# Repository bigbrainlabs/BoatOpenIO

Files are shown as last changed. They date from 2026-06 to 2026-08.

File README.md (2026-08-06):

# BoatOpenIO




**Universal Marine IO System – Open Source, modular, fully configurable**

> *"Plug in, configure, done."*

BoatOpenIO is an open hardware platform for sensor integration on boats. Each of the 16 sensor terminals can be freely assigned to any of the up to 16 input channels via software. Pluggable mini-boards handle signal conditioning — no soldering, no rewiring.

Part of the **[Logbook Without Posing](https://www.amazon.com/s?k=logbook+without+posing)** series – Volume 3.

---

## 📚 Support the project

This project is 100% open source and free. The complete story – every idea, mistake, detour and solution – is documented in the book series **"Logbook Without Posing"**.

If you find this project useful and want to support it: buying the books is the best way.

> *"Found this useful? Grab a book — or the whole series. You'll be supporting further development."*

**[👉 Logbook Without Posing on Amazon](https://amzn.to/4e5swN6)**

Prefer not to deal with a PCB fab? The manufactured board set is available on Tindie — same design as the Gerbers in this repo, which stay free to download and order yourself.

**[👉 BoatOpenIO v2 PCB Set (4 boards) on Tindie](https://www.tindie.com/products/bigbrainlabs/boatopenio-v2-pcb-set-4-boards/)**

### 🏭 Boards sponsored by PCBWay

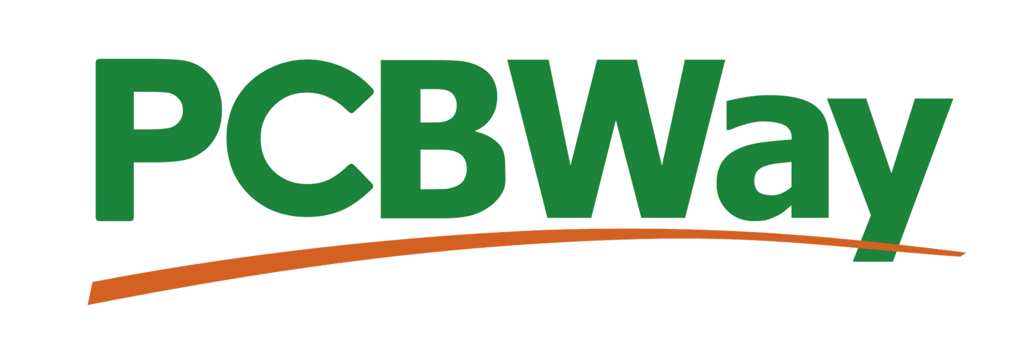
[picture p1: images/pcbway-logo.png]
PCBWay


**[PCBWay](https://www.pcbway.com)** sponsors the board manufacturing for BoatOpenIO, the sensor gateway of this ecosystem — thank you!

**[👉 Order the boards directly: PCBWay project page](https://www.pcbway.com/project/member/?bmbno=0EDF2E80-7ABD-44)**

---

## ⚠️ Safety Warning

**Always verify which mini-board is plugged into which channel before applying power.**

Connecting 12V directly to a pull-up channel (instead of through a voltage divider) will destroy the MUX, all ADS1115 and the ESP32 through I2C chain reaction.

The input board includes protection circuitry (3.3V) on all 16 signal inputs — but correct mini-board assignment is still essential.

---

## Concept

Commercial marine IO systems cost hundreds of euros and are closed black boxes.

BoatOpenIO costs a fraction of that — and anyone can adapt, extend, and improve it.

```
Sensor → Mini-Board → JST 3-Pin → PCB → Zener Protection → MUX → ADS1115 → ESP32 → MQTT → BoatOS
```

---

## Who Is This For?

**If your boat was built before 2000, this project was built for you.**

Boats from that era came with **analog VDO sensors** — oil pressure, oil temperature, coolant temperature, tank level, RPM. These sensors are robust, time-tested, and still doing their job perfectly. The problem: no modern system speaks their language.

NMEA 2000 gateways that bridge analog signals to modern boat networks exist — but they cost **300–500€**, are closed proprietary boxes, and give you zero insight or control over what happens inside.

**BoatOpenIO is an open analog marine gateway.**

Plug in your existing VDO sensors. Get clean MQTT output. Forward to Signal K or BoatOS. Done — without replacing a single sensor, without rewiring, without a black box.

```
VDO sensor → BoatOpenIO → MQTT → Signal K / BoatOS → modern dashboard
```

> **Built for boats built before 2000 that will sail for another 20 years — and deserve a modern dashboard without a full refit.**

---

## Hardware – v2 PCB

Four separate boards, connected via IDC ribbon cables: **input board**, **main board**, **ESP32 adapter board**, and **VCC distributor**. Gerber files ready to order in `hardware/v2/*/gerber/`.

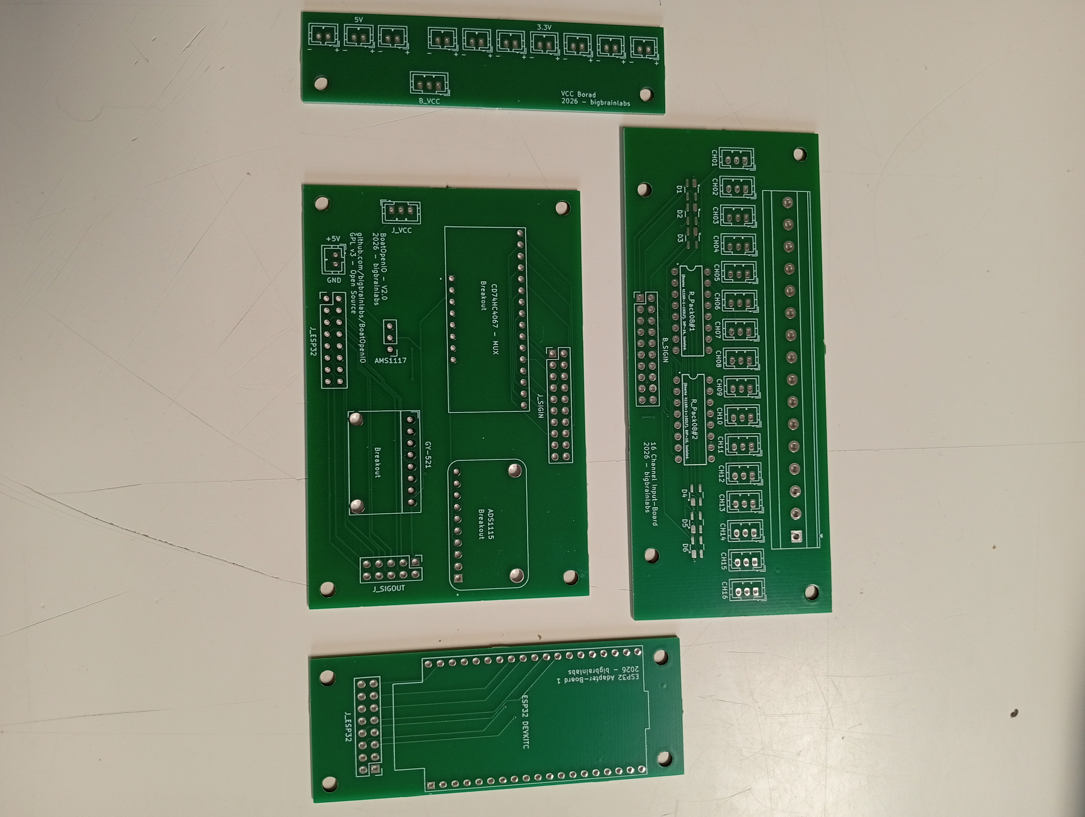
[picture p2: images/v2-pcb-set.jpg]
The bare v2 board set: input board, main board, ESP32 adapter board and VCC distributor


> 🛒 **Don't want to order at a PCB fab?** The fabricated set of all four boards is available ready-made: **[BoatOpenIO v2 PCB Set on Tindie](https://www.tindie.com/products/bigbrainlabs/boatopenio-v2-pcb-set-4-boards/)** — bare PCBs, components not included (see the parts list below).

```
Input Board ──20-pin ribbon──> Main Board <──16-pin ribbon── ESP32 Adapter Board
                                    │
                               3-pin JST
                                    │
                               VCC Board
```

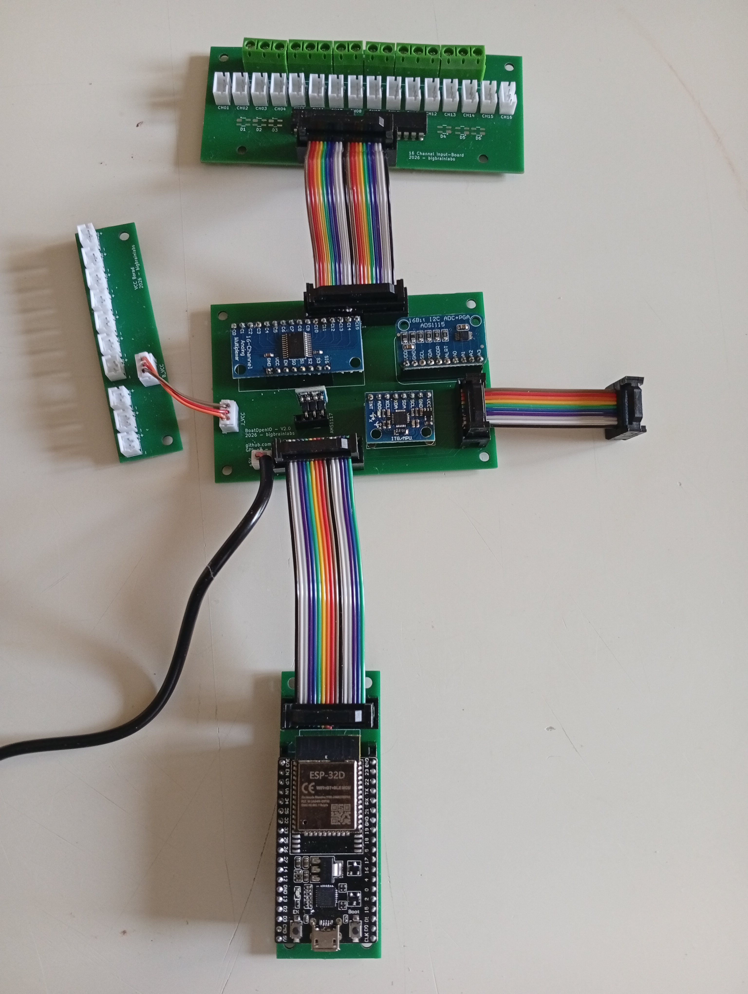
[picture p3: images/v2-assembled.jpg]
Populated and wired v2 assembly with breakouts and ribbon cables


### Main Board Components

| Component | Description | Socketed |
|---|---|---|
| ESP32-DEVKITC-32D-F (38-pin) | Microcontroller, WiFi, I2C, MUX control – on its own adapter board | ✅ |
| CD74HC4067 Breakout | 16:1 analog multiplexer | ✅ |
| ADS1115 Breakout (1×) | 16-bit ADC | ✅ |
| MPU6050 Breakout (GY-521) | 6-DOF IMU, tilt/impact detection | ✅ |
| AMS1117-3.3 Breakout | 5V → 3.3V regulator | ✅ |

**Everything socketed** — no component soldered directly. Faulty ESP32? Swap the adapter board. Done.

The ESP32 sits on its own dedicated adapter board. The first adapter board is designed for the 38-pin ESP32 DevKitC-32D — swappable and ready for future ESP32 variants.

### Protection Circuit (Input Board)

Every one of the 16 signal inputs has a hardware protection circuit, directly on the input board:

```
Sensor → Screw terminal → R_Pack08 (resistor network) → SP0503BAHTG (Zener array, 3.3V) → MUX signal
```

2× Bourns 4116R-1-102LF (R_Pack08, DIL-16, isolated) + 6× SP0503BAHTG (SOT-143, 3 channels each).

> ⚠️ **Pull-up voltage is 3.3V** — the ADS1115 VDD is at 3.3V; higher voltages on the inputs risk component damage.

#### Running without the protection circuit (not recommended)

If the Bourns or Zener components are unavailable and you want to get the board running first, the resistor networks can be bypassed — but understand what you are giving up.

**How to bypass the Bourns 4116R-1-102LF:**  
The DIL-16 package contains 8 isolated resistors. Each resistor connects a pin on the left row to the opposing pin on the right row:

```
Pin 1  ──[R]──  Pin 16
Pin 2  ──[R]──  Pin 15
Pin 3  ──[R]──  Pin 14
  ...             ...
Pin 8  ──[R]──  Pin 9
```

To bypass: solder a short jumper wire across each pair (8 bridges per chip, 16 total for both R_Pack08). The signal then passes through without series resistance. The SP0503BAHTG Zener pads can simply be left empty.

> 🔴 **Without this protection, all 16 inputs are exposed.** A wrong mini-board, a wiring mistake, or any brief overvoltage can destroy the MUX, ADS1115, and ESP32 in a chain reaction — all three at once. Only bypass for bench tests with known, clean signals. Fit the real parts before installing on the boat.

### Input Board – Connectors

```
16× screw terminal 5.08mm   → raw sensor signal
20-pin IDC header            → connection to main board (SIG1–16 + GND)
```

### VCC Board – Connectors

The VCC board distributes power to the mini-boards via JST connectors. It connects to the main board via a 3-pin JST cable (5V, 3.3V, GND).

```
7× JST 2-pin (3.3V)         → VCC rail for passive/ESP01 mini-boards
3× JST 2-pin (5V)           → VCC rail for Arduino Nano mini-boards
3-pin JST                   → connection to main board (5V · 3.3V · GND)
```

### I2C Address

Only 1× ADS1115 fitted (the MUX routes all 16 channels onto a single signal line) → fixed address **0x48**.

### GPIO Assignment (ESP32, via 16-pin main board ↔ adapter board connector)

| GPIO | Function |
|---|---|
| GPIO21 | I2C SDA |
| GPIO22 | I2C SCL |
| GPIO14 | MUX S0 |
| GPIO27 | MUX S1 |
| GPIO26 | MUX S2 |
| GPIO25 | MUX S3 |
| GPIO4 / 5 / 13 / 16 / 17 / 18 / 19 / 23 | OUT1–OUT8 (prepared for output channels) |

### Output Channels (prepared)

The main board already has a 10-pin header prepared for 8 signal output channels (+5V/GND) — e.g. for heaters, pumps, horns via relay or MOSFET mini-boards. Works on the same plug-in principle as the inputs.

### Compatible ESP32 Modules (first adapter board)

The footprint fits all modules in the 38-pin DevKitC layout: **ESP32-WROOM-32 / -32D / -32E / -32U / -32UE**, as well as **ESP32-SOLO-1**.

> ⚠️ **ESP32-WROVER is NOT compatible** — GPIO16/17 are internally reserved for PSRAM on WROVER and therefore blocked for output channels.

---

## Mini-Boards (pluggable)

| Type | Code | Use case |
|---|---|---|
| Voltage divider | VT | 12V VDO sensors → 3.3V |
| Pull-down | PD | Digital sensors, switches |
| Pull-up | PU | Open-collector outputs |
| Schmitt trigger | ST | Magnetic pickup sensors, 50Hz generators |
| Pulse board | ISP | RPM, flow (Arduino Nano / ESP01) |
| Optocoupler | OPT | Galvanic isolation (W-terminal RPM) |
| Direct / jumper | DIR | 3.3V signals directly |
| GND collector | GND | Multiple sensor ground loops → single reference |

### MotorCombo — everything on one board

The **MotorCombo** taps the most common engine sensors directly, so you don't have to plug in six separate mini-boards:

| Channel | Conditioning |
|---|---|
| Battery 1 + 2 | Voltage divider |
| Oil pressure | Pull-up |
| Temperature | Pull-up |
| Tank | Pull-up |
| RPM | Optocoupler + ESP-01 |

**[MotorCombo THT](hardware/mini-boards/MotorCombo_THT/README.md)** — through-hole, hand-solderable. Gerbers and documentation are in the repo. Resistor values are deliberately left open so everyone can fit what matches their own VDO senders — which is also why there is no pre-assembled SMD variant: with the values depending on the senders, a fixed pre-populated board makes no sense.

**Design and submit your own mini-boards** — pull requests welcome!

---

## Multiplexer Logic

The CD74HC4067 routes one of 16 inputs onto the shared ADS pin A0 via a 4-bit address (S3–S0). Address and chip input follow the datasheet: `0000 → C0` … `1111 → C15`.

> **Rev.1 note — channels are mirrored in software.** On the Rev.1 board the channel wiring is reversed (terminal 1 sits on the input that address `1111` selects, terminal 16 on `0000`). The firmware compensates in software (`MUX_MIRROR`): terminal *N* → address `16 − N`. The terminal numbering you see is therefore correct. A later board revision straightens the wiring, then the mirror is switched off (`MUX_MIRROR 0`).

| Terminal | Address S3 S2 S1 S0 | CD74HC4067 input |
|---|---|---|
| 1 | `1111` | C15 |
| 2 | `1110` | C14 |
| … | … | … |
| 16 | `0000` | C0 |

---

## Software Configuration

```json
{
  "kanaele": [
    {"klemme": 1, "sensor": "battery1",     "einheit": "V",   "faktor": 4.7, "offset": 0, "aktiv": true,  "topic": ""},
    {"klemme": 2, "sensor": "oil_temp",     "einheit": "°C",  "faktor": 1.0, "offset": 0, "aktiv": true,  "topic": "vessels/self/propulsion/engine/oilTemperature"},
    {"klemme": 3, "sensor": "oil_pressure", "einheit": "bar", "faktor": 1.0, "offset": 0, "aktiv": true,  "topic": "vessels/self/propulsion/engine/oilPressure"},
    {"klemme": 4, "sensor": "tank",         "einheit": "%",   "faktor": 1.0, "offset": 0, "aktiv": true,  "topic": ""},
    {"klemme": 5, "sensor": "rpm",          "einheit": "rpm", "faktor": 1.0, "offset": 0, "aktiv": false, "topic": ""}
  ]
}
```

> All 16 channels are routed via the MUX (CD74HC4067) to a single ADS1115 @ 0x48 on pin A0. No `ads` or `pin` fields needed — the channel number (`klemme`) maps directly to the MUX select lines.
>
> **`topic`** — optional. If empty (`""`), the firmware publishes to `boat/io/<sensor>` (default). Set a custom topic for Signal K compatibility or any other MQTT schema. The "SK" button in the web UI auto-fills the correct Signal K path for common sensor names.

---

## MQTT Topics

```
boat/io/battery1       → 12.43
boat/io/oil_temp       → 87
boat/io/oil_pressure   → 3.2
boat/io/tank           → 48
boat/io/rpm            → 1450
boat/io/pitch          → 1.2
boat/io/roll           → -0.5
boat/io/impact         → LIGHT
boatopenio/status      → online
```

---

## Firmware Features

| Feature | Description |
|---|---|
| Web UI | Configuration at `192.168.4.1`, bilingual DE/EN |
| WiFiManager | AP on first start for WiFi setup |
| MQTT | Publish all sensor values, LWT, auth support |
| OTA | Over-the-air firmware updates |
| mDNS | Reachable as `boatopenio.local` |
| Impact Detection | MPU6050 G-force monitoring with severity levels |
| Watchdog | Automatic restart on firmware hang |
| LittleFS | Persistent configuration storage |

---

## Supported Sensors

| Sensor | Type | Mini-Board |
|---|---|---|
| VDO temperature (NTC) | Resistance | VT |
| VDO oil pressure | Linear resistance | VT |
| VDO tank sender | Potentiometer | VT |
| Battery voltage 12V | Voltage divider | VT (10k/2.2k) |
| RPM (W-terminal) | Pulse/AC | OPT + ISP |
| RPM (magnetic pickup) | AC signal | ST + ISP |
| Fuel flow | Pulse | ISP |
| Bilge sensor | Digital | PD |
| Door/hatch contact | Digital | PD |
| DS18B20 temperature | Digital 1-Wire | custom board |

---

## Bill of Materials – PCB Kit

**[👉 Complete parts list on Amazon](https://www.amazon.de/hz/wishlist/ls/2ZLKK0GZJ5RZE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)**

> **Note:** Items 7, 8, 13, and 14 are from the same set — one purchase covers all. Same applies to 12 and 15.

| # | Component | Notes | Source |  |
|---|---|---|---|---|
| 1 | ESP32 DevKitC-32D (38-pin) | Main controller | [Amazon](https://amzn.to/441f1bl) |  |
| 2 | CD74HC4067 Breakout | 16:1 MUX | [Amazon](https://amzn.to/4vPmaHH) |  |
| 3 | ADS1115 Breakout (1×) | 16-bit ADC | [Amazon](https://amzn.to/4gg8mRQ) |  |
| 4 | MPU6050 Breakout (GY-521) | IMU | [Amazon](https://amzn.to/3S3gGKJ) |  |
| 5 | AMS1117-3.3 Breakout | Voltage regulator | [Amazon](https://amzn.to/4gfqqeL) |  |
| 6 | Female header assortment | Sockets for all breakouts | [Amazon](https://amzn.to/3S1rXLD) |  |
| 7 | Pin header 2×10 (20-pin) | Main board ↔ input board | [Amazon](https://amzn.to/4f2awU6) |  |
| 8 | Pin header 2×08 (16-pin) | Main board ↔ ESP32 adapter board | [Amazon](https://amzn.to/4f2awU6) |  |
| 9 | Screw terminals 5.08mm | 16× sensor inputs | [Amazon](https://amzn.to/4e6bJcN) |  |
| 10 | Bourns 4116R-1-102LF (2×) | Resistor network DIL-16 | [Conrad](https://www.conrad.de/de/p/bourns-4116r-1-102lf-4116r-1-102lf-widerstandsnetzwerk-1-k-radial-bedrahtet-dip-16-0-25-w-1-st-1055156.html) | [Amazon](https://amzn.to/3SuSZeD) |
| 11 | SP0503BAHTG (6×) | Zener array SOT-143 | [Amazon](https://amzn.to/4aippiv) |  |
| 12 | JST 2-pin connector | VCC rails | [Amazon](https://amzn.to/43y2Suh) |  |
| 13 | Pin header 2×10 (20-pin) | Input board side | [Amazon](https://amzn.to/4f2awU6) |  |
| 14 | Pin header 2×08 (16-pin) | ESP32 adapter board side | [Amazon](https://amzn.to/4f2awU6) |  |
| 15 | JST 2-pin connector (10×) | VCC distribution | [Amazon](https://amzn.to/43y2Suh) |  |
| 16 | Ribbon cable + IDC 20-pin | Main board ↔ input board | [Amazon](https://amzn.to/4w6858M) |  |
| 17 | Ribbon cable + IDC 16-pin | Main board ↔ ESP32 adapter board | [Amazon](https://amzn.to/3SuZ3DQ) |  |
| 18 | Pin socket 2×05 (10-pin) | SIG-OUT prep on main board | — |  |
| 19 | JST 3-pin connector | VCC board ↔ main board | [Amazon](https://amzn.to/4ush82N) |  |
| 20 | PCB set (4 boards) | Order the Gerbers in `hardware/v2/` yourself, or get the ready-made set | [Tindie](https://www.tindie.com/products/bigbrainlabs/boatopenio-v2-pcb-set-4-boards/) |  |

> Amazon: faster delivery. AliExpress links to follow.
>
> **Item 10 comes from Conrad**, not Amazon: the same Bourns part is around €1.30 there versus roughly €10. For the 2 pieces needed that saves nearly €18. The Amazon link beside it is just the fallback source.
>
> The Tindie set covers item 20 only — bare boards. Items 1–19 are the components you still need.

---

## Directory Structure

```
BoatOpenIO/
├── README.md                          ← English (this file)
├── README_de.md                       ← German version
├── LICENSE                            ← GPL-3.0
├── boatopenio_final_architektur.svg   ← system architecture diagram
├── firmware_src/
│   ├── firmware_src.ino               ← main firmware
│   ├── webui.h                        ← web UI & captive portal
│   └── data/
│       └── config.json                ← default channel config
├── hardware/
│   ├── boatopenio-gehaeuse-draufsicht.svg  ← housing top-view
│   ├── mini-boards/                   ← mini-board designs
│   └── v2/                            ← KiCad PCB project (4 boards)
│       ├── main-board/
│       │   └── gerber/main-board.zip
│       ├── input-board/
│       │   └── gerber/input-board.zip
│       ├── esp32-adapter-board/
│       │   └── gerber/esp32-adapter-board.zip
│       └── vcc-board/
│           └── gerber/vcc-board.zip
├── images/                            ← build photos
└── docs/
    ├── setup.md              / setup_de.md          ← commissioning guide
    ├── configuration.md      / configuration_de.md  ← config reference
    └── backend.md            / backend_de.md        ← firmware & backend reference
```

---

## Roadmap

What's done, what's planned, what's on the backlog — see [ROADMAP.md](ROADMAP.md).

---

## Integration with BoatOS

BoatOpenIO sends all values via MQTT. BoatOS auto-discovers all topics and displays them in the dashboard. No manual configuration needed.

**➡️ [github.com/bigbrainlabs/BoatOS](https://github.com/bigbrainlabs/BoatOS)**

---

## License

**GNU General Public License v3.0 (GPL-3.0)**

Free to use, modify, distribute — derivative works must also be GPL-3.0. See [LICENSE](LICENSE).

**Exception:** the community enclosure designs in `hardware/enclosures/` are licensed **CC BY-SA 4.0** — the better fit for CAD work. Submitting a design means licensing it that way; see the [enclosure README](hardware/enclosures/README.md).

---

## Part of the Series

**Logbook Without Posing** — authentic DIY projects around boating.

> *"Build it yourself and you know what's in it — and what it cost."*

📖 [Book series on Amazon](https://amzn.to/4e5swN6) · 🔧 [BoatOS](https://github.com/bigbrainlabs/BoatOS) · ⚡ [BoatOpenIO](https://github.com/bigbrainlabs/BoatOpenIO) · 🛒 [PCB set on Tindie](https://www.tindie.com/products/bigbrainlabs/boatopenio-v2-pcb-set-4-boards/)

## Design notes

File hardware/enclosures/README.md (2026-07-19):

# BoatOpenIO v2 — Enclosure Designs

Community-designed enclosures for the BoatOpenIO v2 PCB set.

## Contest

We're running a community design contest (August–September 2026). The winning designs go into the `winner/` folder and are free for everyone to print.

## Submitting

Designs are submitted via [GitHub issue](../../issues/new?template=enclosure-submission.yml). Alternatively, open a pull request placing the files directly in `community/<your-name>/`.

Please include:

- An STL for printing, plus the source format if possible (STEP, FCStd, f3d …) — that's the only way someone else can build on your design
- A short description: print settings, material, required screws / heat-set inserts
- A photo or render, if you have one

The template for this is in [`SUBMISSION_TEMPLATE.md`](SUBMISSION_TEMPLATE.md).

## Rights & License

> **By submitting a design you license it under [CC BY-SA 4.0](https://creativecommons.org/licenses/by-sa/4.0/).** Without that permission we cannot publish your design.

What this means in practice:

- **You keep your copyright.** You're only granting a license — you remain free to use and publish your design anywhere else.
- **Attribution (BY).** Anyone using or modifying your design must credit you. So tell us the name you want to be credited under.
- **Share-alike (SA).** Anyone who modifies and redistributes your design must license the result under CC BY-SA 4.0 as well. That includes us, should we develop a design into the official BoatOpenIO enclosure.
- **The license is irrevocable.** Copies already published stay usable even if you later have your design removed from the repo. Only submit what you're willing to release permanently.
- **It has to be your own work.** Watch out for imported third-party parts: manufacturer CAD for connectors or housings (STEP downloads) often may not be redistributed. Please remove such parts before submitting, or replace them with your own models.

You confirm these points explicitly when submitting — via checkbox in the issue form, or in the description of your pull request.

The rest of this repo is licensed GPL-3.0. The enclosure designs are deliberately excluded from that, because CC BY-SA 4.0 is the better fit for hardware and CAD work.

## Reference Scans

3D scans of all four assembled boards are in `reference_scans/`. Available as STL — import into your CAD software as reference geometry.

Provided by community member Bernd — attribution per CC BY-SA 4.0.

> **Note:** Scans are measurements, not engineering drawings. For fits and tolerances use the dimensions in the specs below, not the scan geometry.

## Specs

Four boards need to fit inside:

| Board | Dimensions | Mounting holes |
|---|---|---|
| Main Board | 90×60mm | 4× M3, 4.2mm from edge |
| Input Board | 110×46mm | 4× M3, 4.5mm from edge |
| ESP32 Adapter | 80×30mm | 4× M3, 4.5mm (X) / 3.8–4.2mm (Y) from edge |
| VCC Board | 20×80mm | 2× M3, 4.2mm from edge |

**Accessible with enclosure closed:**
- 16× screw terminals SIG-IN
- 16× JST 3-pin (mini board connectors)
- 10× JST 2-pin (VCC rails)
- 1× 5V power input
- Cable gland for SIG-OUT extension (8-pin IDC ribbon cable)

**Additional requirements:**
- Boat mounting — vibration resistant, wall mount or DIN rail
- Optional: space for active fan (40 or 60mm)
- Material: 3D print, ASA recommended

## Community Designs

All submitted designs are in `community/`. Print them, improve them, share them — crediting the respective author.

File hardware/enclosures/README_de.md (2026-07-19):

# BoatOpenIO v2 — Gehäuse-Designs

Community-Designs für das BoatOpenIO v2 Platinensatz-Gehäuse.

## Wettbewerb

Wir veranstalten einen Community-Design-Wettbewerb (August–September 2026). Die Gewinner-Designs landen im Ordner `winner/` und sind für alle zum Nachdrucken frei verfügbar.

## Einreichen

Designs werden über ein [GitHub-Issue eingereicht](../../issues/new?template=enclosure-submission.yml). Alternativ per Pull Request mit den Dateien direkt in `community/<dein-name>/`.

Bitte mitliefern:

- STL zum Drucken, plus wenn möglich das Quellformat (STEP, FCStd, f3d …) — nur so kann jemand dein Design weiterentwickeln
- Kurze Beschreibung: Druckeinstellungen, Material, benötigte Schrauben/Einschmelzmuttern
- Foto oder Render, wenn vorhanden

Die Vorlage dafür liegt in [`SUBMISSION_TEMPLATE.md`](SUBMISSION_TEMPLATE.md).

## Rechte & Lizenz

> **Mit dem Einreichen eines Designs stellst du es unter [CC BY-SA 4.0](https://creativecommons.org/licenses/by-sa/4.0/deed.de).** Ohne diese Zustimmung können wir dein Design nicht veröffentlichen.

Was das konkret bedeutet:

- **Du behältst dein Urheberrecht.** Du erteilst lediglich eine Nutzungslizenz — du darfst dein Design weiterhin überall sonst verwenden und veröffentlichen.
- **Namensnennung (BY).** Jeder, der dein Design nutzt oder verändert, muss dich nennen. Sag uns deshalb, unter welchem Namen du genannt werden willst.
- **Weitergabe unter gleichen Bedingungen (SA).** Wer dein Design verändert und weitergibt, muss das Ergebnis wieder unter CC BY-SA 4.0 stellen. Das gilt auch für uns, falls wir ein Design zum offiziellen BoatOpenIO-Gehäuse weiterentwickeln.
- **Die Lizenz ist unwiderruflich.** Einmal veröffentlichte Kopien bleiben nutzbar, auch wenn du dein Design später aus dem Repo entfernen lässt. Bitte reiche nur ein, was du dauerhaft freigeben willst.
- **Es muss deine eigene Arbeit sein.** Achtung bei importierten Fremdteilen: Hersteller-CAD von Steckern oder Gehäusen (STEP-Downloads) darf oft nicht weiterverbreitet werden. Solche Teile bitte vor dem Einreichen entfernen oder durch eigene Nachbauten ersetzen.

Beim Einreichen bestätigst du diese Punkte einmal ausdrücklich — im Issue-Formular per Checkbox, beim Pull Request in der Beschreibung.

Der übrige Inhalt dieses Repos steht unter GPL-3.0. Die Gehäuse-Designs sind davon bewusst ausgenommen, weil CC BY-SA 4.0 die passendere Lizenz für Hardware- und CAD-Werke ist.

## Referenz-Scans

3D-Scans aller vier bestückten Platinen befinden sich in `reference_scans/`. Als STL verfügbar — einfach in die CAD-Software als Referenzgeometrie importieren.

Bereitgestellt von Community-Mitglied Bernd — Namensnennung gemäß CC BY-SA 4.0.

> **Hinweis:** Scans sind Messwerte, keine Konstruktionszeichnungen. Für Passungen und Toleranzen gelten die Maße aus der Spezifikation unten, nicht die Scan-Geometrie.

## Spezifikation

Vier Boards müssen ins Gehäuse passen:

| Board | Abmessungen | Befestigungsbohrungen |
|---|---|---|
| Mainboard | 90×60mm | 4× M3, je 4,2mm vom Rand |
| Eingangsboard | 110×46mm | 4× M3, je 4,5mm vom Rand |
| ESP32-Adapterboard | 80×30mm | 4× M3, je 4,5mm (X) / 3,8–4,2mm (Y) vom Rand |
| VCC-Verteilerboard | 20×80mm | 2× M3, je 4,2mm vom Rand |

**Bei geschlossenem Gehäuse zugänglich:**
- 16× Schraubklemmen SIG-IN
- 16× JST 3-Pin (Mini-Platinen Signalstecker)
- 10× JST 2-Pin (VCC-Leisten)
- 1× 5V Stromeingang
- Kabeldurchführung für SIG-OUT Erweiterungsmodul (8-pol IDC Flachbandkabel)

**Weitere Anforderungen:**
- Bootsmontage berücksichtigen — vibrationssicher, Wandmontage oder Hutschiene
- Optional: Platz für aktiven Lüfter (40 oder 60mm)
- Material: 3D-Druck, ASA empfohlen

## Community-Designs

Alle eingereichten Designs befinden sich in `community/`. Nachdrucken, verbessern, teilen — unter Nennung des jeweiligen Urhebers.

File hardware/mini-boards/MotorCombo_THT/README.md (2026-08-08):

# MotorCombo THT — Combo Mini-Board for Engine Sensors

> 🚧 **Prototype stage.** This board (Rev.1) has not been fully validated yet. Five of the six channels are tested, the RPM channel is not (see below). Resistor values, mounting holes and layout may still change in future revisions. Build at your own risk, and ideally with feedback.

Through-hole (THT) variant of the MotorCombo board. Combines the six typical engine room signals onto a single board instead of plugging in six separate mini-boards.

Every part is through-hole — hand-solderable, no SMD equipment needed.

---

## Channels

| Channel | Connector | Signal conditioning | Typical sensor |
|---|---|---|---|
| Battery 1 | `Batt1` | Voltage divider (R1 / R2) | 12 V house voltage |
| Battery 2 | `Batt2` | Voltage divider (R3 / R4) | Second battery bank |
| Tank | `Tank1` | Pull-up to 3.3 V (R5) | VDO tank sender, resistive |
| Temperature | `Temp1` | Pull-up to 3.3 V (R6) | VDO temperature sender, resistive |
| Oil pressure | `Oil1` | Pull-up to 3.3 V (R7) | VDO pressure sender, resistive |
| RPM | `RPM1` | Optocoupler PC817 + ESP-01 | Alternator W terminal, pulse pickup |

Every channel has a 100 nF capacitor for signal smoothing (C1–C6).

> Channels 1–5 (`Batt1`, `Batt2`, `Tank1`, `Temp1`, `Oil1`) are **not hardwired** to one mode — two solder jumpers per channel select pull-up or voltage-divider. See [Channel Mode — Jumpers](#channel-mode--jumpers-channels-15). The table shows the typical default for each sensor.

---

## Signal Path

Per the netlist, the JST 3-pin connectors are wired as **input / GND / output**: the raw signal arrives on pin 1, the conditioned signal returns on pin 3.

```
Pin 1 (raw) → conditioning → Pin 3 (conditioned)
Pin 2 = GND
```

**Voltage divider (Batt1, Batt2)**
```
Pin 1 ──[R1]──┬── Pin 3
              ├── C1 ── GND
              └──[R2]── GND
```

**Pull-up (tank, temperature, oil)**
```
3.3 V ──[R5]──┬── Pin 1 = Pin 3
              └── C3 ── GND
```
Pin 1 and pin 3 are tied together — the resistive sender forms the divider together with the pull-up resistor.

**RPM (RPM1)**
```
Pin 1 ──[R8]── PC817 LED ── GND
               PC817 transistor ── GPIO0 (ESP-01), pull-up R9
               GPIO2 ──[R10]──┬── Pin 3
                              └── C6 ── GND
```
The optocoupler isolates the pulse input galvanically. The ESP-01 counts the pulses and outputs an RPM-proportional value on pin 3.

---

## Channel Mode — Jumpers (channels 1–5)

Channels 1–5 (`Batt1`, `Batt2`, `Tank1`, `Temp1`, `Oil1`) are **not hardwired to one mode**. Two solder jumpers **JP1** and **JP2** plus the channel's divider resistor **R2** select **pull-up** (resistive VDO senders) or **voltage-divider** (active voltage inputs) — per channel.

**JP1 (3 pads):**
- **P1 = 3.3 V** (pull-up)
- **P3 = SIG-IN** (voltage divider)
- **P2 = common** (centre pad)

| | Pull-up mode | Voltage-divider mode |
|---|---|---|
| **JP1** | bridge **P2–P3** | bridge **P2–P1** |
| **JP2** | **bridged** | **open** |
| **R2** (channel divider resistor) | **fit a bridge** (0 Ω) | **fit** |

- **Pull-up:** JP1 P2–P3 closed, JP2 closed, R2 position populated with a **bridge** (a 0 Ω resistor in the same footprint, or a wire link) — the pull-up is active and SIG-OUT is passed through. **Important:** do not leave R2 open here. The board has no separate direct GND connection, so the R2 position provides the ground for the smoothing capacitor; left open, the ceramic cap would sit in series in the signal path instead of to ground.
- **Voltage divider:** JP1 P2–P1 closed, JP2 open, R2 fitted — the divider is formed.

Channel 6 (`RPM1`) is the optocoupler + ESP-01 path and has no mode jumper.

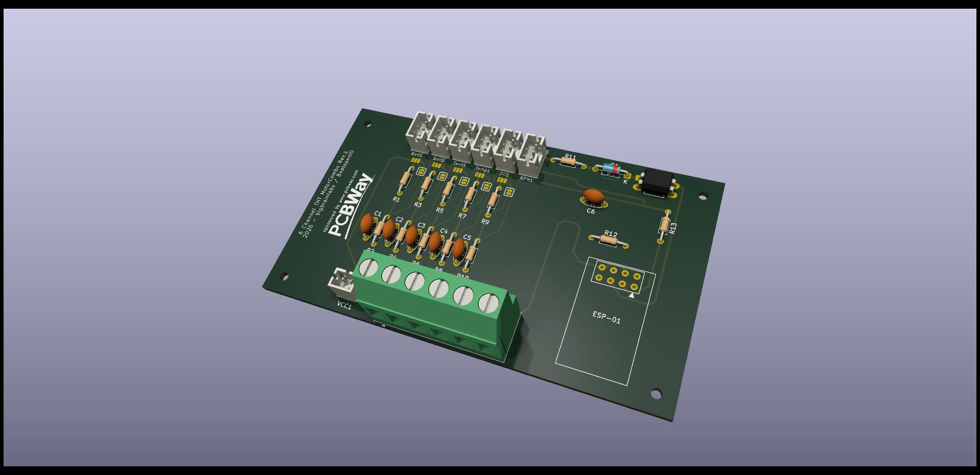
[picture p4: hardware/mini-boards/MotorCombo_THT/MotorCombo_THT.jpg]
MotorCombo THT Rev.1 board with component designators


---

## Connectors

| Designator | Type | Function |
|---|---|---|
| `Batt1`, `Batt2`, `Tank1`, `Temp1`, `Oil1`, `RPM1` | JST PH 3-pin, 2.0 mm | Channels to the main board |
| `J7` | JST PH 2-pin, 2.0 mm | 3.3 V / GND supply from the VCC board |
| `GND_Collector1` | Screw terminal 5-way, 5.08 mm | Common point for sensor grounds |

---

## Board

| | |
|---|---|
| Revision | Rev.1 |
| Dimensions | 75 × 55 mm |
| Layers | 2 |
| Assembly | through-hole throughout |
| Mounting | 4 holes, one per corner |
| Gerbers | [`gerber/`](gerber/) — ready to order, ZIP included |

> 🏭 **Order ready-made:** the boards are sponsored by [PCBWay](https://www.pcbway.com) and shared in the [PCBWay project](https://www.pcbway.com/project/member/?bmbno=0EDF2E80-7ABD-44) — order directly, no Gerber upload needed.
>
> <a href="https://www.pcbway.com/project/member/?bmbno=0EDF2E80-7ABD-44">PCBWay</a>

---

## Bill of Materials

| Item | Part | Qty | Package |
|---|---|-----|---|
| 1 | Resistor, axial | 10 | DIN0204, 7.62 mm pitch |
| 2 | Capacitor 100 nF, ceramic | 6 | disc D5 mm, 5.00 mm pitch |
| 3 | PC817 optocoupler | 1 | DIP-4 |
| 4 | ESP-01 (ESP8266) | 1 | ESP-01 module, 2×4 socket |
| 5 | JST PH header 3-pin, vertical | 6 | B3B-PH-K |
| 6 | JST PH header 2-pin, vertical | 1 | B2B-PH-K |
| 7 | Screw terminal 5-way | 1 | Phoenix MKDS-3/5-5.08 |

---

## Resistor Values

**Values R1–R10 are deliberately left open in the schematic.** VDO senders differ in resistance range depending on year and manufacturer — a value that works cleanly on one engine can cause distorted readings on the next. Rather than prescribing one size, everyone fits what matches their own senders.

The following values have proven themselves in practice and are a good starting point:

| Channel | Resistors | Recommended | Alternative |
|---|---|---|---|
| Battery 1 | R1 / R2 | 10 kΩ / 2.2 kΩ | 100 kΩ / 22 kΩ |
| Battery 2 | R3 / R4 | 10 kΩ / 2.2 kΩ | 100 kΩ / 22 kΩ |
| Tank | R5 | 10 kΩ | adjust to your sender |
| Temperature | R6 | 10 kΩ | adjust to your sender |
| Oil pressure | R7 | 10 kΩ | adjust to your sender |

**Voltage dividers.** 10 kΩ / 2.2 kΩ is tested and works. The divider ratio is 2.2 / (10 + 2.2) = 0.180, so 12 V becomes roughly 2.16 V. As a factor in the channel configuration that works out to about **5.55**, and with a 3.3 V input limit the upper end lands at roughly 18 V. The 100 kΩ / 22 kΩ variant has the same ratio but loads the battery ten times less — at the cost of being more susceptible to interference.

**Pull-ups.** 10 kΩ has shown itself to be a good compromise in testing. If a sender uses a different resistance range, the pull-up should be adjusted along with it — best measured on the installed sender, choosing a value that makes good use of the measuring range.

**Optocoupler.** R8 sets the PC817 LED current, R9 is the pull-up at the ESP-01. This combination has not yet been proven in practice (see below).

---

## ESP-01 Notes

The ESP-01 is **socketed** — it needs a dedicated USB adapter for flashing anyway, so it is taken out of the board for programming. That is why `RST`, `URXD` and `UTXD` are left unconnected.

> 🚧 **The RPM channel via PC817 and ESP-01 has not been tested in practice yet.** The other five channels are proven.

Worth keeping in mind during assembly: on the ESP8266, `GPIO0` and `GPIO2` double as boot-mode straps, and both are wired here.

- **GPIO0** is tied to the optocoupler transistor. If a pulse happens to be present at power-on, the optocoupler pulls GPIO0 low and the ESP-01 boots into flash mode instead of running the firmware — quite possible with the engine running.
- **GPIO2** drives the output through R10. C6 is discharged at power-on — depending on the values chosen for R10 and C6, this may hold GPIO2 low for too long during boot.

Both depend on the values of R8, R9, R10 and C6, and can be settled together when the RPM channel is trialled.

> 💡 **Tip: use an ESP-01S instead of an ESP-01.** The newer ESP-01S variant already has a pull-up fitted on GPIO0. This mitigates the boot-mode issue above, since GPIO0 is safely held high at idle. The ESP-01S is pin-compatible and fits the same socket.

---

## Safety

> ⚠️ **Verify which channel sits on which terminal before applying power.**
>
> The battery channels are designed for 12 V through voltage dividers. If 12 V accidentally reaches one of the pull-up channels (tank, temperature, oil), it will destroy the MUX, ADS1115 and ESP32 through an I2C chain reaction. See the safety warning in the [main README](../../../README.md).

---

## License

GPL-3.0, same as the rest of the repo. See [LICENSE](../../../LICENSE).

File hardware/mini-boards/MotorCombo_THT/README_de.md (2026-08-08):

# MotorCombo THT — Kombi-Mini-Platine für Motorsensoren

> 🚧 **Prototyp-Phase.** Diese Platine (Rev.1) ist noch nicht final erprobt. Fünf der sechs Kanäle sind getestet, der Drehzahlkanal noch nicht (siehe unten). Widerstandswerte, Bohrungen und Layout können sich in kommenden Revisionen noch ändern. Nachbau auf eigenes Risiko und am besten mit Rückmeldung.

Bedrahtete (THT) Variante der MotorCombo-Platine. Fasst die sechs typischen Motorraum-Signale auf einer Platine zusammen, statt sechs einzelne Mini-Platinen zu stecken.

Alle Bauteile sind bedrahtet — von Hand lötbar, ohne SMD-Ausrüstung.

---

## Kanäle

| Kanal | Stecker | Signalaufbereitung | Typischer Sensor |
|---|---|---|---|
| Batterie 1 | `Batt1` | Spannungsteiler (R1 / R2) | Bordspannung 12 V |
| Batterie 2 | `Batt2` | Spannungsteiler (R3 / R4) | Zweite Batteriebank |
| Tank | `Tank1` | Pull-up nach 3.3 V (R5) | VDO-Tankgeber, resistiv |
| Temperatur | `Temp1` | Pull-up nach 3.3 V (R6) | VDO-Temperaturgeber, resistiv |
| Öldruck | `Oil1` | Pull-up nach 3.3 V (R7) | VDO-Druckgeber, resistiv |
| Drehzahl | `RPM1` | Optokoppler PC817 + ESP-01 | W-Klemme Lichtmaschine, Impulsgeber |

Jeder Kanal hat einen 100 nF Kondensator zur Signalglättung (C1–C6).

> Die Kanäle 1–5 (`Batt1`, `Batt2`, `Tank1`, `Temp1`, `Oil1`) sind **nicht fest verdrahtet** — zwei Lötbrücken je Kanal wählen Pull-up- oder Spannungsteiler-Modus. Siehe [Kanalmodus — Jumper](#kanalmodus--jumper-kanäle-15). Die Tabelle zeigt den typischen Standard je Sensor.

---

## Signalführung

Die JST-3-Pin-Stecker sind laut Netzliste als **Eingang / GND / Ausgang** belegt: Das Rohsignal kommt auf Pin 1 an, das aufbereitete Signal geht auf Pin 3 zurück zum Board.

```
Pin 1 (roh) → Aufbereitung → Pin 3 (aufbereitet)
Pin 2 = GND
```

**Spannungsteiler (Batt1, Batt2)**
```
Pin 1 ──[R1]──┬── Pin 3
              ├── C1 ── GND
              └──[R2]── GND
```

**Pull-up (Tank, Temp, Öl)**
```
3.3 V ──[R5]──┬── Pin 1 = Pin 3
              └── C3 ── GND
```
Pin 1 und Pin 3 sind durchverbunden — der resistive Geber bildet zusammen mit dem Pull-up-Widerstand den Spannungsteiler.

**Drehzahl (RPM1)**
```
Pin 1 ──[R8]── PC817 LED ── GND
               PC817 Transistor ── GPIO0 (ESP-01), Pull-up R9
               GPIO2 ──[R10]──┬── Pin 3
                              └── C6 ── GND
```
Der Optokoppler trennt den Impulseingang galvanisch. Der ESP-01 zählt die Impulse und gibt auf Pin 3 einen drehzahlproportionalen Wert aus.

---

## Kanalmodus — Jumper (Kanäle 1–5)

Die Kanäle 1–5 (`Batt1`, `Batt2`, `Tank1`, `Temp1`, `Oil1`) sind **nicht fest auf einen Modus verdrahtet**. Zwei Lötbrücken **JP1** und **JP2** sowie der Teilerwiderstand **R2** des Kanals wählen **Pull-up** (resistive VDO-Geber) oder **Spannungsteiler** (aktive Spannungseingänge) — je Kanal.

**JP1 (3 Pads):**
- **P1 = 3.3 V** (Pull-up)
- **P3 = SIG-IN** (Spannungsteiler)
- **P2 = gemeinsam** (mittleres Pad)

| | Pull-up-Modus | Spannungsteiler-Modus |
|---|---|---|
| **JP1** | **P2–P3** brücken | **P2–P1** brücken |
| **JP2** | **gebrückt** | **offen** |
| **R2** (Teilerwiderstand des Kanals) | **Brücke einlöten** (0 Ω) | **einlöten** |

- **Pull-up:** JP1 P2–P3 gebrückt, JP2 gebrückt, R2-Position als **Brücke** bestückt (0-Ω-Widerstand im selben Footprint oder Drahtbrücke) — der Pull-up ist aktiv und SIG-OUT wird durchgereicht. **Wichtig:** R2 hier nicht offen lassen. Die direkte GND-Verbindung fehlt auf der Platine, deshalb stellt die R2-Position die Masse für den Glättungs-Kerko her; bliebe sie offen, läge der Kerko in Reihe im Signalpfad statt gegen Masse.
- **Spannungsteiler:** JP1 P2–P1 gebrückt, JP2 offen, R2 bestückt — der Teiler wird gebildet.

Kanal 6 (`RPM1`) ist der Optokoppler-/ESP-01-Pfad und hat keinen Modus-Jumper.

MotorCombo THT Rev.1 Platine mit Bauteilbezeichnern

---

## Anschlüsse

| Bezeichner | Typ | Funktion |
|---|-----|---|
| `Batt1`, `Batt2`, `Tank1`, `Temp1`, `Oil1`, `RPM1` | JST PH 3-Pin, 2.0 mm | Kanäle zum Mainboard |
| `J7` | JST PH 2-Pin, 2.0 mm | Versorgung 3.3 V / GND vom VCC-Board |
| `GND_Collector1` | Schraubklemme 5-polig, 5.08 mm | Sammelpunkt für Sensormassen |

---

## Platine

| | |
|---|---|
| Revision | Rev.1 |
| Abmessungen | 75 × 55 mm |
| Lagen | 2 |
| Bauform | durchgehend THT |
| Befestigung | 4 Bohrungen, eine je Ecke |
| Gerber | [`gerber/`](gerber/) — bestellfertig, inkl. ZIP |

> 🏭 **Fertig bestellen:** Die Platinen werden von [PCBWay](https://www.pcbway.com) gesponsert und sind im [PCBWay-Projekt](https://www.pcbway.com/project/member/?bmbno=0EDF2E80-7ABD-44) geteilt — direkt bestellbar, ohne Gerber hochzuladen.
>
> <a href="https://www.pcbway.com/project/member/?bmbno=0EDF2E80-7ABD-44">PCBWay</a>

---

## Stückliste

| Pos. | Bauteil | Anzahl | Gehäuse |
|---|---|---|---|
| 1 | Widerstand, axial | 10 | DIN0204, RM 7.62 mm |
| 2 | Kondensator 100 nF, keramisch | 6 | Scheibe D5 mm, RM 5.00 mm |
| 3 | PC817 Optokoppler | 1 | DIP-4 |
| 4 | ESP-01 (ESP8266) | 1 | ESP-01 Modul, 2×4 Buchsenleiste |
| 5 | JST PH Stiftleiste 3-Pin, vertikal | 6 | B3B-PH-K |
| 6 | JST PH Stiftleiste 2-Pin, vertikal | 1 | B2B-PH-K |
| 7 | Schraubklemme 5-polig | 1 | Phoenix MKDS-3/5-5.08 |

---

## Widerstandswerte

**Die Werte R1–R10 sind im Schaltplan bewusst offen gelassen.** VDO-Geber unterscheiden sich je nach Baujahr und Hersteller im Widerstandsbereich — ein Wert, der an einem Motor sauber funktioniert, kann am nächsten zu Verfälschungen führen. Statt eine Größe vorzugeben, bestückt jeder passend zu seinen eigenen Gebern.

Die folgenden Werte haben sich in der Praxis bewährt und sind ein guter Startpunkt:

| Kanal | Widerstände | Empfehlung | Alternative |
|---|---|---|---|
| Batterie 1 | R1 / R2 | 10 kΩ / 2.2 kΩ | 100 kΩ / 22 kΩ |
| Batterie 2 | R3 / R4 | 10 kΩ / 2.2 kΩ | 100 kΩ / 22 kΩ |
| Tank | R5 | 10 kΩ | je nach Geber anpassen |
| Temperatur | R6 | 10 kΩ | je nach Geber anpassen |
| Öldruck | R7 | 10 kΩ | je nach Geber anpassen |

**Spannungsteiler.** 10 kΩ / 2.2 kΩ ist getestet und funktioniert. Das Teilerverhältnis beträgt 2.2 / (10 + 2.2) = 0.180, aus 12 V werden also rund 2.16 V. Als Faktor in der Kanalkonfiguration ergibt das etwa **5.55**, die Obergrenze liegt bei 3.3 V Eingangsspannung entsprechend bei rund 18 V. Die Variante 100 kΩ / 22 kΩ hat dasselbe Verhältnis, belastet die Batterie aber zehnmal weniger — dafür ist sie empfindlicher gegen Einstreuungen.

**Pull-ups.** 10 kΩ hat sich in Tests als guter Kompromiss gezeigt. Nutzt ein Geber einen anderen Widerstandsbereich, sollte der Pull-up mit angepasst werden — am besten am eingebauten Geber durchmessen und den Wert so wählen, dass der Messbereich gut ausgenutzt wird.

**Optokoppler.** R8 bestimmt den LED-Strom des PC817, R9 ist der Pull-up am ESP-01. Diese Kombination ist noch nicht in der Praxis erprobt (siehe unten).

---

## ESP-01 Hinweise

Der ESP-01 wird **gesockelt** — er braucht zum Flashen ohnehin einen speziellen USB-Adapter und wird deshalb zum Programmieren aus der Platine genommen. `RST`, `URXD` und `UTXD` sind aus diesem Grund nicht beschaltet.

> 🚧 **Der Drehzahlkanal über PC817 und ESP-01 ist noch nicht in der Praxis getestet.** Die übrigen fünf Kanäle sind erprobt.

Beim Aufbau zu beachten: `GPIO0` und `GPIO2` legen beim ESP8266 gleichzeitig den Bootmodus fest, und beide sind hier beschaltet.

- **GPIO0** hängt am Optokoppler-Transistor. Liegt beim Einschalten gerade ein Impuls an, zieht der Optokoppler GPIO0 auf Masse und der ESP-01 startet in den Flash-Modus statt in die Firmware. Bei laufendem Motor also durchaus möglich.
- **GPIO2** treibt über R10 den Ausgang. C6 ist beim Einschalten entladen — je nach Wahl von R10 und C6 kann GPIO2 dadurch beim Booten zu lange auf Masse liegen.

Beides hängt an den Werten von R8, R9, R10 und C6 und lässt sich beim Erproben des Drehzahlkanals gemeinsam festlegen.

> 💡 **Tipp: ESP-01S statt ESP-01 verwenden.** Die neuere ESP-01S-Variante hat GPIO0 bereits mit einem Pull-up bestückt. Das entschärft das Boot-Modus-Problem oben, da GPIO0 im Ruhezustand sicher auf High gehalten wird. Der ESP-01S ist pinkompatibel und passt in denselben Sockel.

---

## Sicherheit

> ⚠️ **Vor dem Einschalten prüfen, welcher Kanal auf welcher Klemme liegt.**
>
> Die Batteriekanäle sind für 12 V über Spannungsteiler ausgelegt. Kommen 12 V versehentlich auf einen der Pull-up-Kanäle (Tank, Temperatur, Öl), zerstört das MUX, ADS1115 und ESP32 über eine I2C-Kettenreaktion. Siehe Sicherheitshinweis in der [Haupt-README](../../../README_de.md).

---

## Lizenz

GPL-3.0, wie das übrige Repo. Siehe [LICENSE](../../../LICENSE).

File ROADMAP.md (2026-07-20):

# BoatOpenIO – Roadmap

> Feature freeze in effect. The items below reflect planned directions, not commitments.  
> Pull requests welcome for anything on this list.

---

## Done – v2.2 (current)

**Security & hardening**
- [x] First-time setup routes (`/setup`, `/dosetup`) auth-gated once completed
- [x] JSON APIs (`/api/values`, `/api/raw`, `/api/imu`) require authentication
- [x] CSRF protection on all POST endpoints (Origin/Referer check)
- [x] Input filtering (sensor/topic whitelist) + HTML escaping against injection

**Field reliability**
- [x] Automatic WiFi reconnect after outage (cold start after power loss)
- [x] OTA update no longer aborted by the watchdog
- [x] Config integrity: larger JSON buffers, overflow-safe save (no data loss)
- [x] Retained impact alarm cleared on MQTT connect (no "stuck" alarm)
- [x] TEST mode publishes alarms to `boat/test/alarm/*` instead of real topics
- [x] Reduced flash wear (write config only on change) · ADC averaging · terminal validation

**Calibration**
- [x] Two-point calibration calculator (computes factor **and** offset)
- [x] Ω mode for resistive VDO senders (+ `/api/adc` endpoint for live reads)

**Documentation**
- [x] New firmware/backend reference (`docs/backend.md` / `backend_de.md`)
- [x] `setup.md` and `configuration.md` brought up to date

---

## Done – v2.1

**Hardware**
- [x] 4-board architecture: main board, input board, ESP32 adapter, VCC distributor
- [x] Single ADS1115 @ 0x48 + CD74HC4067 16:1 MUX (all 16 channels on one ADC)
- [x] Hardware protection on all 16 inputs: Bourns resistor network + SP0503BAHTG Zener array (3.3V clamp)
- [x] All components socketed — no direct soldering
- [x] 8× output channel header prepared on main board (GPIO 4/5/13/16–19/23)
- [x] Pluggable mini-boards: VT, PD, PU, ST, ISP, OPT, DIR, GND
- [x] Gerber files ready for JLCPCB (all 4 boards)

**Firmware**
- [x] 16-channel analog read via MUX (faktor + offset calibration per channel)
- [x] MPU6050 IMU: pitch / roll / impact detection with severity levels
- [x] MQTT: all sensor values, LWT, auth, configurable topic per channel
- [x] Signal K path suggestions (SK button in web UI)
- [x] OTA firmware updates (ArduinoOTA)
- [x] mDNS (`boatopenio.local`)
- [x] WiFiManager captive portal (AP on first boot)
- [x] LittleFS config persistence (config.json)
- [x] Watchdog (automatic restart on hang)
- [x] Web UI: bilingual DE/EN, dark theme, responsive, live values, calibration

---

## Planned – v2.x

**Firmware**
- [ ] Output channels: firmware support for 8× GPIO outputs (on/off, PWM)
- [ ] Output mini-boards: relay and MOSFET designs
- [ ] DS18B20 1-Wire temperature sensor support
- [ ] Web UI: inline config.json editor (raw JSON view/edit in browser)
- [ ] Web UI: OTA upload trigger (flash firmware directly from browser)
- [ ] Clean up legacy `ads` / `pin` fields from config schema and firmware

**Docs**
- [ ] Node-RED integration example (MQTT → dashboard)
- [ ] Signal K server setup guide (BoatOpenIO as data source)

---

## Ideas / Backlog

These are directions worth exploring — no timeline attached.

- [ ] **BoatOS auto-discovery** — announce all active topics and units on connect
- [ ] **Second ESP32 adapter board** — smaller footprint, or ESP32-S3 / C3 variant
- [ ] **PWM gauge output** — drive analog cockpit instruments from digital values
- [ ] **Data logging** — optional SD card module for offline value history
- [ ] **NMEA 2000 bridge** — CAN bus module, both directions:
  - [ ] **Transmit** — output active channels to NMEA 2000
  - [ ] **Receive** — read existing NMEA 2000 devices on the bus and publish them as MQTT
- [ ] **Per-channel alert thresholds** — configurable min/max with MQTT alert topic
- [ ] **Enclosure** — housing for all 4 boards with dedicated slots for mini-boards (3D print / DIN rail)

---

## Not Planned

To keep the project focused:

- No cloud dependency, no vendor accounts, no subscriptions
- No proprietary app — web UI runs entirely on the ESP32
- No support for sensors that require active current excitation (4–20mA loops) — out of scope for this hardware revision

---

## Contributing

Found a bug? Have a mini-board design? Open a pull request or issue on GitHub.

**[github.com/bigbrainlabs/BoatOpenIO](https://github.com/bigbrainlabs/BoatOpenIO)**

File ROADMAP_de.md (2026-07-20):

# BoatOpenIO – Roadmap

> Feature Freeze aktiv. Die folgenden Punkte zeigen geplante Richtungen, keine verbindlichen Zusagen.  
> Pull Requests für alles auf dieser Liste sind willkommen.

---

## Fertig – v2.2 (aktuell)

**Sicherheit & Härtung**
- [x] Ersteinrichtungs-Routen (`/setup`, `/dosetup`) nach Abschluss auth-geschützt
- [x] JSON-APIs (`/api/values`, `/api/raw`, `/api/imu`) erfordern Authentifizierung
- [x] CSRF-Schutz auf allen POST-Endpunkten (Origin/Referer-Prüfung)
- [x] Eingabe-Filterung (Sensor/Topic-Whitelist) + HTML-Escaping gegen Injection

**Zuverlässigkeit im Feld**
- [x] Automatischer WiFi-Reconnect nach Ausfall (Kaltstart nach Stromausfall)
- [x] OTA-Update wird nicht mehr vom Watchdog abgebrochen
- [x] Config-Integrität: größere JSON-Puffer, overflow-sicheres Speichern (kein Datenverlust)
- [x] Retained Aufprall-Alarm wird beim MQTT-Connect bereinigt (kein „hängender" Alarm)
- [x] TEST-Modus publiziert Alarme auf `boat/test/alarm/*` statt echter Topics
- [x] Flash-Wear reduziert (Config nur bei Änderung schreiben) · ADC-Mittelung · Klemme-Validierung

**Kalibrierung**
- [x] Zwei-Punkt-Kalibrierungs-Rechner (berechnet Faktor **und** Offset)
- [x] Ω-Modus für resistive VDO-Geber (+ `/api/adc`-Endpunkt zum Live-Lesen)

**Dokumentation**
- [x] Neue Firmware-/Backend-Referenz (`docs/backend.md` / `backend_de.md`)
- [x] `setup.md` und `configuration.md` auf aktuellen Stand gebracht

---

## Fertig – v2.1

**Hardware**
- [x] 4-Platinen-Architektur: Mainboard, Eingangsboard, ESP32-Adapterboard, VCC-Verteiler
- [x] Einzelner ADS1115 @ 0x48 + CD74HC4067 16:1 MUX (alle 16 Kanäle über einen ADC)
- [x] Hardwareschutz an allen 16 Eingängen: Bourns Widerstandsnetzwerk + SP0503BAHTG Zener-Array (3,3V Clamp)
- [x] Alle Komponenten auf Sockeln — kein Bauteil fest verlötet
- [x] 8× Ausgangskanal-Header auf dem Mainboard vorbereitet (GPIO 4/5/13/16–19/23)
- [x] Steckbare Mini-Platinen: VT, PD, PU, ST, ISP, OPT, DIR, GND
- [x] Gerber-Dateien bestellfertig für JLCPCB (alle 4 Platinen)

**Firmware**
- [x] 16-Kanal-Analogmessung über MUX (Faktor + Offset-Kalibrierung pro Kanal)
- [x] MPU6050 IMU: Pitch / Roll / Aufprallerkennung mit Schweregradabstufung
- [x] MQTT: alle Sensorwerte, LWT, Auth, frei konfigurierbarer Topic pro Kanal
- [x] Signal K-Pfadvorschläge (SK-Button im Web-UI)
- [x] OTA-Firmware-Updates (ArduinoOTA)
- [x] mDNS (`boatopenio.local`)
- [x] WiFiManager Captive Portal (WLAN-Einrichtung beim ersten Start)
- [x] LittleFS Konfigurationsspeicher (config.json)
- [x] Watchdog (automatischer Neustart bei Firmware-Hänger)
- [x] Web-UI: zweisprachig DE/EN, dunkles Theme, responsiv, Live-Werte, Kalibrierung

---

## Geplant – v2.x

**Firmware**
- [ ] Ausgangskanäle: Firmware-Unterstützung für 8× GPIO-Ausgänge (An/Aus, PWM)
- [ ] Ausgangs-Mini-Platinen: Relais- und MOSFET-Designs
- [ ] DS18B20 1-Wire Temperatursensor-Unterstützung
- [ ] Web-UI: eingebetteter config.json-Editor (JSON direkt im Browser bearbeiten)
- [ ] Web-UI: OTA-Upload direkt aus dem Browser heraus
- [ ] Veraltete Felder `ads` / `pin` aus Config-Schema und Firmware entfernen

**Dokumentation**
- [ ] Node-RED Integrationsbeispiel (MQTT → Dashboard)
- [ ] Signal K Server Einrichtungsanleitung (BoatOpenIO als Datenquelle)

---

## Ideen / Backlog

Mögliche Richtungen ohne festen Zeitplan.

- [ ] **BoatOS Auto-Discovery** — alle aktiven Topics und Einheiten beim Verbinden ankündigen
- [ ] **Zweites ESP32-Adapterboard** — kleinerer Footprint oder ESP32-S3 / C3 Variante
- [ ] **PWM-Gauge-Ausgang** — analoge Cockpit-Instrumente aus digitalen Werten ansteuern
- [ ] **Datenprotokollierung** — optionales SD-Karten-Modul für lokale Wertehistorie
- [ ] **NMEA-2000-Bridge** — CAN-Bus-Modul, beide Richtungen:
  - [ ] **Senden** — aktive Kanäle auf NMEA 2000 ausgeben
  - [ ] **Empfangen** — bestehende NMEA-2000-Geräte am Bus mitlesen und als MQTT publizieren
- [ ] **Kanalbasierte Grenzwerte** — konfigurierbare Min/Max-Schwellen mit MQTT-Alarm-Topic
- [ ] **Gehäuse** — Aufnahme für alle 4 Platinen mit dedizierten Steckplätzen für Mini-Platinen (3D-Druck / Hutschiene)

---

## Nicht geplant

Um den Projektkern zu erhalten:

- Keine Cloud-Abhängigkeit, keine Herstellerkonten, keine Abonnements
- Keine proprietäre App — das Web-UI läuft vollständig auf dem ESP32
- Keine Unterstützung für Sensoren mit Stromspeisung (4–20mA-Schleifen) — außerhalb des Rahmens dieser Hardware-Revision

---

## Mitmachen

Fehler gefunden? Eigenes Mini-Platinen-Design? Pull Request oder Issue auf GitHub eröffnen.

**[github.com/bigbrainlabs/BoatOpenIO](https://github.com/bigbrainlabs/BoatOpenIO)**

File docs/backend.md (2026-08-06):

# BoatOpenIO – Firmware & Backend Reference

This reference describes **what the firmware does at runtime** – boot sequence, measurement
and publishing behaviour, the HTTP/MQTT interfaces, the security model and persistence.
It is meant as a lookup and operating manual for the backend.

For first-time commissioning see [`setup.md`](setup.md); for the field-by-field
configuration reference see [`configuration.md`](configuration.md).

> As of firmware **v2.2**. Source files: `firmware_src/firmware_src.ino` (logic) and
> `firmware_src/webui.h` (web UI, HTTP handlers).

---

## 1. Architecture at a glance

```
              ┌──────────────────────────── ESP32-WROOM-32D ───────────────────────────┐
  Sensors  →  │  CD74HC4067 MUX ──► ADS1115 @ 0x48 (A0)      MPU6050 @ 0x68/0x69 (I²C)  │
  (16 terms)  │         ▲                                                                │
              │         │ S0–S3 (GPIO 14/27/26/25)                                       │
              │   ┌─────┴───── loop() (Core 1, non-blocking, millis()-paced) ────────┐   │
              │   │  channels 2 s · IMU 50 Hz · pitch/roll 1 s · heartbeat 10 s      │   │
              │   └──────────────────────────────────────────────────────────────────┘  │
              │      │                 │                    │                             │
              │   WebServer:80    PubSubClient (MQTT)   ArduinoOTA / mDNS                 │
              └──────┼─────────────────┼────────────────────┼─────────────────────────────┘
                     │                 │                    │
                Browser (AP/STA)   MQTT broker         Arduino IDE (OTA)
```

There are **no** application FreeRTOS tasks – everything runs cooperatively in `loop()`.
All timing uses the overflow-safe `millis()` subtraction pattern, so no timer drifts after
the 49.7-day millis rollover.

---

## 2. Boot sequence (`setup()`)

Order at boot:

1. **Serial** (115200 baud) – status output.
2. **Factory-reset check** – holding GPIO0 at power-on for 3 s clears NVS and `config.json`
   and restarts (see §11).
3. **I²C** (`Wire.begin`, SDA 21 / SCL 22) and **LittleFS** mount.
4. **`loadNetConfig()`** – network/portal/IMU settings from NVS.
5. **`loadConfig()`** – channel config from `/config.json`. On a read/JSON error the default
   channels stay active and the file is **not** overwritten.
6. **I²C scan** – discovered addresses are listed in the serial monitor.
7. **ADS1115 @ 0x48**, gain `GAIN_TWOTHIRDS` (±6.144 V range, matching the 3.3 V front-end).
8. **MPU6050 @ 0x68 or 0x69**, accel ±8 g, gyro ±250 °/s, filter bandwidth **94 Hz**
   (high enough to catch impact transients). If absent, the fake IMU (demo motion) runs.
9. **Gyro-bias calibration** – 100 samples (~0.5 s), keep the board still.
10. **WiFi** in `WIFI_AP_STA` mode: the **AP always starts immediately**; if STA credentials
    exist it additionally waits up to 10 s for a router connection.
11. **MQTT** – server/port set, receive buffer **4096 bytes** (so full config payloads arrive).
12. **`ensureStaServices()`** – mDNS (`boatopenio.local`) + OTA as soon as STA is connected.
13. **Web server + captive portal** start.
14. **Task watchdog** (10 s, panic reset) registered on the loop task.

---

## 3. Operating modes: TEST vs. LIVE

| Mode | Channel values | Purpose |
|---|---|---|
| **TEST** (default) | Simulated sine values (`2.5 V + sin(...)·0.3`) | Safe commissioning without real sensors |
| **LIVE** | Real ADS1115 readings via the MUX | Production |

Toggle in the portal under **Actions**. The mode is stored in NVS and restored at boot.

> **Important:** In TEST mode impact alarms are published to `boat/test/alarm/*` instead of
> the real `boat/alarm/*` topics – a freshly configured device won't trigger real alarm
> displays.

---

## 4. Measurement chain

### 4.1 Analog channels (all 16)

All 16 terminals share **one** ADS1115. The CD74HC4067 multiplexer routes the selected
terminal onto ADS pin A0:

```
selectChannel(terminal-1)  →  set S0–S3 (mirrored, Rev.1)  →  settle  →  read ADS A0
```

> **Rev.1:** the Rev.1 board has the channel wiring reversed, so `selectChannel()` mirrors the address in software (`MUX_MIRROR`, terminal *N* → address `16 − N`). See the Multiplexer Logic section in the [README](../README.md#multiplexer-logic). A later board revision drops the mirror.

Each reading **averages 4 samples** (`ADS_SAMPLES`) to smooth engine-bay noise
(alternator, ignition). Conversion to the published value:

```
published_value = raw_voltage × factor + offset
```

Only channels marked **active** are read and published, every **2 s** (`READ_INTERVAL`).

### 4.2 Attitude & impact (MPU6050)

- **50 Hz sampling** (`IMU_INTERVAL` = 20 ms): a complementary filter (α = 0.98) of gyro +
  accel yields pitch/roll; in parallel the acceleration magnitude is checked for impacts.
- **Pitch/roll publishing** is decoupled to every **1 s** (`IMU_PUBLISH_INTERVAL`) to avoid
  flooding the broker. Values are axis-swap, mounting-offset and inversion corrected (in that order).
- **Impact detection:** when net acceleration `|a|/9.81 − 1` exceeds **0.5 g** an impact is
  active; the peak is held. After **8 s** without a new spike (`IMPACT_DECAY`) the alarm resets.

| Peak (g) | Severity |
|---|---|
| < 1.0 | `LEICHT` (light) |
| < 3.0 | `MITTEL` (medium) |
| < 6.0 | `STARK` (strong) |
| ≥ 6.0 | `KRITISCH` (critical) |

---

## 5. MQTT interface

### 5.1 Connection

- Client ID `BoatOpenIO`, optionally with user/password.
- **Last Will (LWT):** `boatopenio/status` = `offline` (retained), on connect → `online`.
- **Reconnect backoff:** 5 s after success, **30 s** after a failed attempt – a dead broker
  won't keep stalling the loop.
- **On (re)connect** the retained alarm state is cleared (see §5.2), unless an impact is
  currently active – this prevents a permanently "stuck" alarm after a brownout mid-impact.

### 5.2 Published topics (ESP32 → broker)

| Topic | Payload | Retained | Interval |
|---|---|:---:|---|
| `boat/io/<sensor>` or custom `topic` | float value | no | 2 s |
| `boat/io/pitch` | float °, corrected | yes | 1 s |
| `boat/io/roll` | float °, corrected | yes | 1 s |
| `boatopenio/status` | `online` / `offline` | yes | 10 s + LWT |
| `boatopenio/uptime` | seconds since boot | no | 10 s |
| `boatopenio/rssi` | WiFi signal (dBm) | no | 10 s |
| `boatopenio/mode` | `TEST` / `LIVE` | yes | 10 s |
| `boat/alarm/impact_g` ¹ | peak g value | yes | on event |
| `boat/alarm/impact_severity` ¹ | `LEICHT`/`MITTEL`/`STARK`/`KRITISCH` | yes | on event |
| `boat/alarm/impact_active` ¹ | `true` / `false` | yes | on event |

¹ In **TEST** mode the prefix is `boat/test/alarm/` instead of `boat/alarm/`.

### 5.3 Subscribed topics (broker → ESP32)

**`boatopenio/config`** – full or partial `config.json` structure (JSON). Overwrites the
in-RAM channel config and stores it (only when actually changed) to LittleFS. Only fields
present in the payload are changed. Sensor and topic strings are filtered server-side (only
`A–Z a–z 0–9 _ - . /`), `klemme` is clamped to 1–16. After applying, `boatopenio/status` =
`config_updated` is reported.

**Example – activate a channel with a Signal K topic:**
```json
{ "kanaele": [
  { "klemme": 3, "sensor": "oeldruck", "faktor": 1.25, "aktiv": true,
    "topic": "vessels/self/propulsion/engine/oilPressure" }
] }
```

> **Signal K units:** the firmware sends **raw values** (degrees, °C, bar, %), not the SI
> units Signal K expects (rad, K, Pa, ratio). Convert via factor/offset or in the SK server
> if needed.

---

## 6. Web portal & HTTP API

### 6.1 Reachability

| Address | Requirement |
|---|---|
| `http://192.168.4.1` | Always – via the built-in AP |
| `http://boatopenio.local` | When on WiFi (mDNS) |
| `http://<IP>` | When on WiFi (IP in serial monitor) |

### 6.2 Routes

| Route | Method | Protection | Function |
|---|---|---|---|
| `/` | GET | Auth | Dashboard (full web UI) |
| `/setup` | GET | setup only, Auth afterwards | First-time setup form |
| `/dosetup` | POST | setup/Auth + CSRF | Set portal/AP credentials |
| `/save` | POST | Auth + CSRF | Save channel config |
| `/savenet` | POST | Auth + CSRF | Save WiFi/MQTT (+ restart) |
| `/savesec` | POST | Auth + CSRF | AP/portal credentials (+ restart) |
| `/testmode` | POST | Auth + CSRF | Toggle TEST/LIVE (+ restart) |
| `/reboot` | POST | Auth + CSRF | Restart |
| `/calibrate` | POST | Auth + CSRF | Set current pitch/roll as mounting offset |
| `/setinvert` | POST | Auth + CSRF | Set pitch/roll inversion and axis swap (`pi`/`ri`/`as`) |
| `/api/values` | GET | Auth | Active channel values + pitch/roll (corrected), JSON |
| `/api/raw` | GET | Auth | Raw ADS A0–A3 voltages (diagnostics), JSON |
| `/api/adc?ch=<1–16>` | GET | Auth | Select MUX terminal, averaged voltage, JSON |
| `/api/imu` | GET | Auth | Pitch/roll raw + corrected, offsets, gyro bias, JSON |

`/api/adc` always reads real ADS hardware (regardless of TEST mode) and serves the
calibration calculator (§8).

### 6.3 JSON response examples

```
GET /api/values → {"batterie_starter":12.48,"tank_diesel":47.0,"pitch":1.2,"roll":-0.4}
GET /api/adc?ch=3 → {"ok":true,"v":1.8342}
GET /api/imu    → {"pitch_raw":1.4,"roll_raw":-0.3,"pitch_corr":1.2,...,"bias_x":0.0012,...}
```

---

## 7. Security model

- **Enforced first-time setup:** while no portal password is set, all routes redirect to
  `/setup`. After setup, `/setup` and `/dosetup` require admin login.
- **HTTP Basic Auth** on every route (dashboard, POST actions, JSON APIs). Portal user and
  password are independent of the AP password.
- **CSRF protection:** POST requests are only accepted when `Origin`/`Referer` match the own
  host (foreign pages can't trigger actions).
- **Input filtering:** sensor/topic names are restricted to `A–Z a–z 0–9 _ - . /` – ruling
  out MQTT wildcards (`#`, `+`) and HTML/script injection.
- **Output escaping:** all stored values are HTML-escaped when rendered.
- **Factory guard:** while the AP password is still the default (`boatopenio`), the portal
  shows a yellow warning banner at the top.

---

## 8. Calibration calculator (web UI)

Two-point linear calibration that derives **factor and offset** from two known states
(`value = factor·V + offset`):

- For each point you enter the **real value** of that state (e.g. 40 °C and 100 °C, or 50 %
  and 75 %) and the ADS voltage measured for it.
- **"Read A0"** grabs the current voltage of the selected channel via `/api/adc`.
- **"Apply to channel"** writes the result straight into the factor/offset fields of the
  channel table.

Calculation:
```
Factor = (value₂ − value₁) / (V₂ − V₁)
Offset = value₁ − Factor · V₁
```

### Ω mode (resistive VDO senders)

Switchable to **resistance input** for resistive senders (e.g. fuel 10–180 Ω). Instead of
voltage you enter each point's **resistance**; the firmware converts it to ADS voltage via
the divider parameters:

| Parameter | Default | Meaning |
|---|---|---|
| Reference voltage | 3.3 V | Divider supply voltage |
| Fixed resistor | 1000 Ω | Fixed resistor (Bourns 4116R-1-102, 1 kΩ) |
| Circuit | pull-up | `sender → GND` (pull-up) or `sender → Vref` (pull-down) |

Conversion (pull-up): `V = Vref · R / (R_fix + R)`, inverse `R = R_fix · V / (Vref − V)`.
In Ω mode "Read A0" returns the back-calculated resistance.

---

## 9. Persistence

### 9.1 NVS (Preferences, namespace `boatopenio`)

Survives firmware updates. Only changeable via the portal or clearable by a factory reset.

| Key | Type | Default | Description |
|-----|---|---|---|
| `wifi_ssid` / `wifi_pass` | string | `""` | WiFi credentials |
| `mqtt_ip` | string | `192.168.1.100` | Broker address |
| `mqtt_port` | string | `1883` | Broker port (1–65535, validated) |
| `mqtt_user` / `mqtt_pass` | string | `""` | MQTT auth |
| `testmode` | bool | `true` | TEST mode active |
| `pitch_off` / `roll_off` | float | `0.0` | IMU mounting offset (°) |
| `pitch_inv` / `roll_inv` | bool | `false` | Axis inversion |
| `axes_swap` | bool | `false` | Swap pitch/roll axes (IMU mounted rotated 90°) |
| `ap_ssid` | string | `BoatOpenIO-Setup` | AP name |
| `ap_pass` | string | `boatopenio` | AP password |
| `portal_user` | string | `admin` | Portal user |
| `portal_pass` | string | `""` | Portal password (empty = setup pending) |

### 9.2 LittleFS `/config.json`

Channel config (16 entries). Loaded at boot and **only rewritten when actually changed**
(saves flash). Local source: `firmware_src/data/config.json`.

| Field | Type | Description |
|---|---|---|
| `klemme` | int 1–16 | Physical terminal (clamped to 1–16) |
| `sensor` | string | Sensor name → topic suffix when `topic` empty |
| `einheit` | string | Unit label (display only) |
| `faktor` | float | Voltage multiplier |
| `offset` | float | Additive offset |
| `aktiv` | bool | Read/publish channel |
| `topic` | string | Custom MQTT topic (empty = `boat/io/<sensor>`) |

The `ads`/`pin` fields exist in the format for historical reasons but are no longer used in
the single-ADS design.

---

## 10. Network resilience & OTA

- **AP always on:** the access point runs regardless of WiFi status – the portal stays
  reachable even without a router.
- **WiFi reconnect:** if STA is configured but disconnected, `loop()` forces a new attempt
  every **30 s**. Once connected, mDNS and OTA are brought up automatically – important for
  cold start after a power outage when the router boots slower than the ESP32.
- **OTA update:** over WiFi via the Arduino IDE (network port "BoatOpenIO at \<IP\>").
  Password = portal password (before setup, `boatopenio` as fallback). During upload the
  loop task is de-registered from the watchdog so the TWDT doesn't abort the update.
- **Watchdog:** 10 s task watchdog with panic reset on the loop task. If the loop hangs
  (e.g. a stuck I²C bus) the device reboots automatically.

---

## 11. Factory reset

| Action | Trigger | Effect |
|---|---|---|
| **WiFi reset** | Hold GPIO0 **during operation** for 3 s | Clears only `wifi_ssid`/`wifi_pass`, restarts. Everything else stays. |
| **Full reset** | Hold GPIO0 **at boot** for 3 s | Clears all NVS + `config.json`. First-time setup required afterwards. |

After a full reset `config.json` may need re-uploading to LittleFS
(Arduino IDE → *ESP32 Sketch Data Upload*).

---

## 12. Timing & constants reference

| Constant | Value | Meaning |
|---|---|---|
| `READ_INTERVAL` | 2000 ms | Read/publish channels |
| `IMU_INTERVAL` | 20 ms (50 Hz) | IMU sampling / impact check |
| `IMU_PUBLISH_INTERVAL` | 1000 ms | Pitch/roll over MQTT |
| `STATUS_INTERVAL` | 10 000 ms | Heartbeat (status/uptime/rssi/mode) |
| `ADS_SAMPLES` | 4 | Averaging per channel reading |
| `WDT_TIMEOUT` | 10 s | Task watchdog |
| `IMPACT_THRESHOLD` | 0.5 g | Impact threshold |
| `IMPACT_DECAY` | 8000 ms | Alarm fall-back time |
| MQTT buffer | 4096 B | Receive buffer (config payloads) |
| WiFi reconnect | 30 s | Interval when STA disconnected |
| MQTT backoff | 5 s / 30 s | after success / after failed attempt |

---

## 13. Troubleshooting (serial monitor, 115200 baud)

| Symptom | Cause / check |
|---|---|
| `ADS1115 @ 0x48 nicht gefunden` | Check I²C wiring, address jumper, VCC/GND (see I²C scan in log). |
| `MPU6050 nicht gefunden – Fake-IMU aktiv` | Sensor at 0x68/0x69? Check AD0 level. Pitch/roll are then simulated. |
| Channels jump a lot | LIVE mode in the engine bay without a clean ground; check wiring/shielding (4-sample averaging is already on). |
| No MQTT data | Broker IP/port, reachability; is `boatopenio/status` = `online`? Check RSSI in log. |
| Portal asks for login, AP password doesn't work | Portal login ≠ AP password. Use the portal user/password from setup. |
| POST rejected with `403 CSRF blocked` | Request didn't originate from the portal page itself (foreign origin). Operate from the portal directly. |
| MQTT config update has no effect | Payload > 4096 B, invalid JSON, or sensor/topic emptied by the filter. |
| Impact alarm stuck at "true" | Should clear on reconnect; in TEST mode alarms live under `boat/test/alarm/*`. |

---

*Part of the "Logbook Without Posing" series · [BoatOpenIO](https://github.com/bigbrainlabs/BoatOpenIO)*

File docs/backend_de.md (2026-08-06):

# BoatOpenIO – Firmware- & Backend-Referenz

Diese Referenz beschreibt, **was die Firmware im Betrieb tut** – Startablauf, Mess- und
Publish-Verhalten, die HTTP-/MQTT-Schnittstellen, das Sicherheitsmodell und die
Persistenz. Sie ist als Nachschlagewerk und Bedienungsanleitung für das Backend gedacht.

Für die reine Erstinbetriebnahme siehe [`setup_de.md`](setup_de.md), für die
Feld-für-Feld-Konfigurationsreferenz [`configuration_de.md`](configuration_de.md).

> Stand: Firmware **v2.2**. Quelldateien: `firmware_src/firmware_src.ino` (Logik) und
> `firmware_src/webui.h` (Web-UI, HTTP-Handler).

---

## 1. Architektur auf einen Blick

```
              ┌──────────────────────────── ESP32-WROOM-32D ───────────────────────────┐
  Sensoren →  │  CD74HC4067 MUX ──► ADS1115 @ 0x48 (A0)      MPU6050 @ 0x68/0x69 (I²C)  │
  (16 Klemmen)│         ▲                                                                │
              │         │ S0–S3 (GPIO 14/27/26/25)                                       │
              │   ┌─────┴───── loop() (Core 1, non-blocking, millis()-getaktet) ─────┐   │
              │   │  Kanäle 2 s · IMU 50 Hz · Pitch/Roll 1 s · Heartbeat 10 s        │   │
              │   └──────────────────────────────────────────────────────────────────┘  │
              │      │                 │                    │                             │
              │   WebServer:80    PubSubClient (MQTT)   ArduinoOTA / mDNS                 │
              └──────┼─────────────────┼────────────────────┼─────────────────────────────┘
                     │                 │                    │
                Browser (AP/STA)   MQTT-Broker         Arduino IDE (OTA)
```

Es gibt **keine** FreeRTOS-Tasks in der Anwendung – alles läuft kooperativ in `loop()`.
Sämtliche Zeitsteuerung nutzt das overflow-feste `millis()`-Subtraktionsmuster, sodass
kein Timer nach 49,7 Tagen (millis-Überlauf) aus dem Tritt gerät.

---

## 2. Startablauf (`setup()`)

Reihenfolge beim Booten:

1. **Serial** (115200 Baud) – Statusausgaben.
2. **Werksreset-Prüfung** – ist GPIO0 beim Einschalten gedrückt und bleibt 3 s gedrückt,
   werden NVS und `config.json` gelöscht und das Gerät startet neu (siehe §11).
3. **I²C** (`Wire.begin`, SDA 21 / SCL 22) und **LittleFS** mounten.
4. **`loadNetConfig()`** – Netzwerk-/Portal-/IMU-Einstellungen aus NVS.
5. **`loadConfig()`** – Kanalkonfiguration aus `/config.json`. Bei Lese-/JSON-Fehler
   bleiben die Default-Kanäle aktiv und die Datei wird **nicht** überschrieben.
6. **I²C-Scan** – gefundene Adressen werden im Serial Monitor gelistet.
7. **ADS1115 @ 0x48**, Gain `GAIN_TWOTHIRDS` (±6,144 V Messbereich, passend zur 3,3-V-Beschaltung).
8. **MPU6050 @ 0x68 oder 0x69**, Accel ±8 g, Gyro ±250 °/s, Filterbandbreite **94 Hz**
   (hoch genug, um Aufprall-Transienten zu erfassen). Fehlt der Sensor, läuft die
   Fake-IMU (Demo-Bewegung).
9. **Gyro-Bias-Kalibrierung** – 100 Samples (~0,5 s), Board dabei ruhig halten.
10. **WiFi** im `WIFI_AP_STA`-Modus: der **AP startet immer sofort**; bei hinterlegten
    STA-Zugangsdaten wird zusätzlich max. 10 s auf eine Router-Verbindung gewartet.
11. **MQTT** – Server/Port gesetzt, Empfangspuffer auf **4096 Byte** (damit vollständige
    Konfig-Payloads ankommen).
12. **`ensureStaServices()`** – mDNS (`boatopenio.local`) + OTA, sobald STA verbunden ist.
13. **Webserver + Captive Portal** starten.
14. **Task-Watchdog** (10 s, Panik-Reset) auf die loop-Task registrieren.

---

## 3. Betriebsmodi: TEST vs. LIVE

| Modus | Kanalwerte | Zweck |
|---|---|---|
| **TEST** (Default) | Simulierte Sinuswerte (`2,5 V + sin(...)·0,3`) | Gefahrlose Inbetriebnahme ohne echte Sensoren |
| **LIVE** | Echte ADS1115-Messung über den MUX | Realbetrieb |

Umschalten im Portal unter **Aktionen**. Der Modus wird in NVS gespeichert und beim
Booten wiederhergestellt.

> **Wichtig:** Im TEST-Modus werden Aufprall-Alarme auf `boat/test/alarm/*` statt auf die
> echten `boat/alarm/*`-Topics publiziert – ein frisch aufgesetztes Gerät löst so keine
> realen Alarm-Anzeigen aus.

---

## 4. Messkette

### 4.1 Analogkanäle (alle 16)

Alle 16 Klemmen teilen sich **einen** ADS1115. Der CD74HC4067-Multiplexer routet die
gewählte Klemme auf ADS-Pin A0:

```
selectChannel(klemme-1)  →  S0–S3 setzen (gespiegelt, Rev.1)  →  Settling  →  ADS A0 lesen
```

> **Rev.1:** Die Rev.1-Platine hat die Kanäle vertauscht verdrahtet, daher spiegelt `selectChannel()` die Adresse softwareseitig (`MUX_MIRROR`, Klemme *N* → Adresse `16 − N`). Siehe Abschnitt Multiplexer-Logik in der [README](../README_de.md#multiplexer-logik). Eine spätere Board-Revision entfernt die Spiegelung.

Pro Messung werden **4 Samples gemittelt** (`ADS_SAMPLES`), um Störungen im Motorraum
(Lichtmaschine, Zündimpulse) zu glätten. Die Umrechnung in den publizierten Wert:

```
publizierter_wert = rohspannung × faktor + offset
```

Nur als **aktiv** markierte Kanäle werden gelesen und publiziert. Getaktet alle
**2 s** (`READ_INTERVAL`).

### 4.2 Lage & Aufprall (MPU6050)

- **50 Hz Sampling** (`IMU_INTERVAL` = 20 ms): Komplementärfilter (α = 0,98) aus Gyro +
  Accel liefert Pitch/Roll; parallel wird die Beschleunigungs­magnitude auf Aufprall geprüft.
- **Pitch/Roll-Publish** entkoppelt nur alle **1 s** (`IMU_PUBLISH_INTERVAL`), um den
  Broker nicht zu fluten. Ausgegeben werden achsentausch-, montage-offset- und invertierungs-korrigierte Werte (in dieser Reihenfolge).
- **Aufprallerkennung:** übersteigt die Netto-Beschleunigung `|a|/9,81 − 1` den Schwellwert
  **0,5 g**, gilt ein Impact als aktiv; der Spitzenwert wird gehalten. Nach **8 s** ohne
  neuen Ausschlag (`IMPACT_DECAY`) wird der Alarm zurückgesetzt.

| Peak (g) | Schweregrad |
|---|---|
| < 1,0 | `LEICHT` |
| < 3,0 | `MITTEL` |
| < 6,0 | `STARK` |
| ≥ 6,0 | `KRITISCH` |

---

## 5. MQTT-Schnittstelle

### 5.1 Verbindung

- Client-ID `BoatOpenIO`, optional mit User/Passwort.
- **Last Will (LWT):** `boatopenio/status` = `offline` (retained), bei Verbindung → `online`.
- **Reconnect-Backoff:** 5 s nach Erfolg, **30 s** nach Fehlversuch – ein toter Broker
  bremst so nicht dauerhaft die loop-Schleife.
- **Beim (Neu-)Verbinden** wird der retained Alarm-Zustand bereinigt (siehe §5.2), sofern
  gerade kein Impact aktiv ist – verhindert einen dauerhaft „hängenden" Alarm nach einem
  Spannungseinbruch mitten im Aufprall.

### 5.2 Publizierte Topics (ESP32 → Broker)

| Topic | Payload | Retained | Intervall |
|---|---|:---:|---|
| `boat/io/<sensor>` oder eigener `topic` | Float-Wert | nein | 2 s |
| `boat/io/pitch` | Float °, korrigiert | ja | 1 s |
| `boat/io/roll` | Float °, korrigiert | ja | 1 s |
| `boatopenio/status` | `online` / `offline` | ja | 10 s + LWT |
| `boatopenio/uptime` | Sekunden seit Boot | nein | 10 s |
| `boatopenio/rssi` | WLAN-Signal (dBm) | nein | 10 s |
| `boatopenio/mode` | `TEST` / `LIVE` | ja | 10 s |
| `boat/alarm/impact_g` ¹ | Peak-G-Wert | ja | bei Ereignis |
| `boat/alarm/impact_severity` ¹ | `LEICHT`/`MITTEL`/`STARK`/`KRITISCH` | ja | bei Ereignis |
| `boat/alarm/impact_active` ¹ | `true` / `false` | ja | bei Ereignis |

¹ Im **TEST**-Modus lautet das Präfix `boat/test/alarm/` statt `boat/alarm/`.

### 5.3 Abonnierte Topics (Broker → ESP32)

**`boatopenio/config`** – vollständige oder partielle `config.json`-Struktur (JSON).
Überschreibt die Kanalkonfiguration im RAM und speichert sie (nur bei tatsächlicher
Änderung) in LittleFS. Es werden nur die im Payload vorhandenen Felder geändert.
Sensor- und Topic-Strings werden serverseitig gefiltert (nur `A–Z a–z 0–9 _ - . /`),
`klemme` wird auf 1–16 begrenzt. Nach Übernahme wird `boatopenio/status` = `config_updated`
gemeldet.

**Beispiel – einen Kanal mit Signal-K-Topic aktivieren:**
```json
{ "kanaele": [
  { "klemme": 3, "sensor": "oeldruck", "faktor": 1.25, "aktiv": true,
    "topic": "vessels/self/propulsion/engine/oilPressure" }
] }
```

> **Signal-K-Einheiten:** Die Firmware sendet **Rohwerte** (Grad, °C, bar, %), nicht die
> von Signal K erwarteten SI-Einheiten (rad, K, Pa, Ratio). Bei Bedarf über Faktor/Offset
> oder im SK-Server umrechnen.

---

## 6. Web-Portal & HTTP-API

### 6.1 Erreichbarkeit

| Adresse | Voraussetzung |
|---|---|
| `http://192.168.4.1` | Immer – über den integrierten AP |
| `http://boatopenio.local` | Bei WLAN-Verbindung (mDNS) |
| `http://<IP>` | Bei WLAN-Verbindung (IP im Serial Monitor) |

### 6.2 Routen

| Route | Methode | Schutz | Funktion |
|---|---|---|---|
| `/` | GET | Auth | Dashboard (gesamte Web-UI) |
| `/setup` | GET | nur Ersteinrichtung, danach Auth | Ersteinrichtungs-Formular |
| `/dosetup` | POST | Ersteinrichtung/Auth + CSRF | Portal-/AP-Zugangsdaten setzen |
| `/save` | POST | Auth + CSRF | Kanalkonfiguration speichern |
| `/savenet` | POST | Auth + CSRF | WiFi/MQTT speichern (+ Neustart) |
| `/savesec` | POST | Auth + CSRF | AP-/Portal-Zugangsdaten (+ Neustart) |
| `/testmode` | POST | Auth + CSRF | TEST/LIVE umschalten (+ Neustart) |
| `/reboot` | POST | Auth + CSRF | Neustart |
| `/calibrate` | POST | Auth + CSRF | Aktuellen Pitch/Roll als Montage-Offset setzen |
| `/setinvert` | POST | Auth + CSRF | Pitch-/Roll-Invertierung und Achsentausch setzen (`pi`/`ri`/`as`) |
| `/api/values` | GET | Auth | Aktive Kanalwerte + Pitch/Roll (korrigiert), JSON |
| `/api/raw` | GET | Auth | Rohspannungen ADS A0–A3 (Diagnose), JSON |
| `/api/adc?ch=<1–16>` | GET | Auth | MUX auf Klemme wählen, gemittelte Spannung, JSON |
| `/api/imu` | GET | Auth | Pitch/Roll roh + korrigiert, Offsets, Gyro-Bias, JSON |

`/api/adc` liest immer die echte ADS-Hardware (unabhängig vom TEST-Modus) und dient dem
Kalibrierungs-Rechner (§8).

### 6.3 JSON-Antwortbeispiele

```
GET /api/values → {"batterie_starter":12.48,"tank_diesel":47.0,"pitch":1.2,"roll":-0.4}
GET /api/adc?ch=3 → {"ok":true,"v":1.8342}
GET /api/imu    → {"pitch_raw":1.4,"roll_raw":-0.3,"pitch_corr":1.2,...,"bias_x":0.0012,...}
```

---

## 7. Sicherheitsmodell

- **Ersteinrichtung erzwungen:** Solange kein Portal-Passwort gesetzt ist, leiten alle
  Routen auf `/setup` um. `/setup` und `/dosetup` sind nach abgeschlossener Einrichtung
  nur noch mit Admin-Login erreichbar.
- **HTTP Basic Auth** auf allen Routen (Dashboard, POST-Aktionen, JSON-APIs). Portal-User
  und -Passwort sind unabhängig vom AP-Passwort.
- **CSRF-Schutz:** POST-Requests werden nur akzeptiert, wenn `Origin`/`Referer` zum eigenen
  Host passen (Fremd-Seiten können so keine Aktionen auslösen).
- **Eingabe-Filterung:** Sensor-/Topic-Namen werden auf `A–Z a–z 0–9 _ - . /` beschränkt –
  schließt MQTT-Wildcards (`#`, `+`) und HTML/Script-Injection aus.
- **Ausgabe-Escaping:** Alle gespeicherten Werte werden beim Rendern HTML-escaped.
- **Werksschutz:** Solange das AP-Passwort dem Standard (`boatopenio`) entspricht, blendet
  das Portal oben ein gelbes Warnbanner ein.

---

## 8. Kalibrierungs-Rechner (Web-UI)

Zwei-Punkt-Linearkalibrierung, die **Faktor und Offset** aus zwei bekannten Zuständen
bestimmt (`Wert = Faktor·V + Offset`):

- Pro Punkt trägt man den **echten Wert** des Zustands (z. B. 40 °C und 100 °C, oder 50 %
  und 75 %) sowie die dazu gemessene ADS-Spannung ein.
- **„A0 lesen"** holt die aktuelle Spannung des gewählten Kanals per `/api/adc`.
- **„In Kanal übernehmen"** schreibt das Ergebnis direkt in die Faktor-/Offset-Felder der
  Kanaltabelle.

Berechnung:
```
Faktor = (Wert₂ − Wert₁) / (V₂ − V₁)
Offset = Wert₁ − Faktor · V₁
```

### Ω-Modus (resistive VDO-Geber)

Umschaltbar auf **Widerstands-Eingabe** für resistive Geber (z. B. Tank 10–180 Ω). Statt
Spannung gibt man je Punkt den **Widerstand** ein; die Firmware rechnet ihn über die
Teilerparameter in die ADS-Spannung um:

| Parameter | Default | Bedeutung |
|---|---|---|
| Referenzspannung | 3,3 V | Speisespannung des Teilers |
| Vorwiderstand | 1000 Ω | Fester Widerstand (Bourns 4116R-1-102, 1 kΩ) |
| Schaltung | Pull-up | `Geber → GND` (Pull-up) oder `Geber → Vref` (Pull-down) |

Umrechnung (Pull-up): `V = Vref · R / (R_fix + R)`, Umkehrung `R = R_fix · V / (Vref − V)`.
Im Ω-Modus liefert „A0 lesen" den zurückgerechneten Widerstand.

---

## 9. Persistenz

### 9.1 NVS (Preferences, Namespace `boatopenio`)

Überlebt Firmware-Updates. Nur über das Portal änderbar oder per Werksreset löschbar.

| Schlüssel | Typ | Default | Beschreibung |
|---|-----|---|---|
| `wifi_ssid` / `wifi_pass` | string | `""` | WLAN-Zugangsdaten |
| `mqtt_ip` | string | `192.168.1.100` | Broker-Adresse |
| `mqtt_port` | string | `1883` | Broker-Port (1–65535, validiert) |
| `mqtt_user` / `mqtt_pass` | string | `""` | MQTT-Auth |
| `testmode` | bool | `true` | TEST-Modus aktiv |
| `pitch_off` / `roll_off` | float | `0.0` | IMU-Montage-Offset (°) |
| `pitch_inv` / `roll_inv` | bool | `false` | Achsen-Invertierung |
| `axes_swap` | bool | `false` | Pitch/Roll tauschen (IMU um 90° gedreht montiert) |
| `ap_ssid` | string | `BoatOpenIO-Setup` | AP-Name |
| `ap_pass` | string | `boatopenio` | AP-Passwort |
| `portal_user` | string | `admin` | Portal-Benutzer |
| `portal_pass` | string | `""` | Portal-Passwort (leer = Ersteinrichtung offen) |

### 9.2 LittleFS `/config.json`

Kanalkonfiguration (16 Einträge). Wird beim Booten geladen und **nur bei tatsächlicher
Änderung** neu geschrieben (schont den Flash). Lokale Quelle: `firmware_src/data/config.json`.

| Feld | Typ | Beschreibung |
|---|-----|---|
| `klemme` | int 1–16 | Physische Klemme (auf 1–16 begrenzt) |
| `sensor` | string | Sensorname → Topic-Suffix, wenn `topic` leer |
| `einheit` | string | Einheitenkürzel (nur Anzeige) |
| `faktor` | float | Spannungsmultiplikator |
| `offset` | float | Additiver Offset |
| `aktiv` | bool | Kanal lesen/publizieren |
| `topic` | string | Eigener MQTT-Topic (leer = `boat/io/<sensor>`) |

Die Felder `ads`/`pin` existieren im Format aus historischen Gründen, werden aber im
Single-ADS-Design nicht mehr ausgewertet.

---

## 10. Netzwerk-Resilienz & OTA

- **AP immer aktiv:** Der Access Point läuft unabhängig vom WLAN-Status – so bleibt das
  Portal auch ohne Router erreichbar.
- **WiFi-Reconnect:** Ist STA konfiguriert aber getrennt, erzwingt `loop()` alle **30 s**
  einen neuen Verbindungsversuch. Sobald die Verbindung steht, werden mDNS und OTA
  automatisch nachgezogen – wichtig für den Kaltstart nach Stromausfall, wenn der Router
  langsamer bootet als der ESP32.
- **OTA-Update:** Bei WLAN-Verbindung über die Arduino IDE (Netzwerk-Port „BoatOpenIO bei
  \<IP\>"). Passwort = Portal-Passwort (vor der Ersteinrichtung `boatopenio` als Fallback).
  Während des Uploads wird die loop-Task vom Watchdog abgemeldet, damit der TWDT das Update
  nicht abbricht.
- **Watchdog:** 10 s Task-Watchdog mit Panik-Reset auf die loop-Task. Hängt die Schleife
  (z. B. blockierender I²C-Bus), rebootet das Gerät automatisch.

---

## 11. Werksreset

| Aktion | Auslöser | Wirkung |
|---|---|---|
| **WiFi-Reset** | GPIO0 **im Betrieb** 3 s halten | Löscht nur `wifi_ssid`/`wifi_pass`, Neustart. Alles andere bleibt. |
| **Voll-Reset** | GPIO0 **beim Booten** gedrückt halten, 3 s | Löscht kompletten NVS + `config.json`. Danach ist erneut die Ersteinrichtung nötig. |

Nach einem Voll-Reset muss `config.json` ggf. neu ins LittleFS geladen werden
(Arduino IDE → *ESP32 Sketch Data Upload*).

---

## 12. Zeit- & Kennwerte-Referenz

| Konstante | Wert | Bedeutung |
|---|---|---|
| `READ_INTERVAL` | 2000 ms | Kanäle lesen/publizieren |
| `IMU_INTERVAL` | 20 ms (50 Hz) | IMU-Sampling / Aufprallprüfung |
| `IMU_PUBLISH_INTERVAL` | 1000 ms | Pitch/Roll per MQTT |
| `STATUS_INTERVAL` | 10 000 ms | Heartbeat (status/uptime/rssi/mode) |
| `ADS_SAMPLES` | 4 | Mittelung pro Kanalmessung |
| `WDT_TIMEOUT` | 10 s | Task-Watchdog |
| `IMPACT_THRESHOLD` | 0,5 g | Aufprall-Schwelle |
| `IMPACT_DECAY` | 8000 ms | Alarm-Rückfallzeit |
| MQTT-Puffer | 4096 B | Empfangspuffer (Config-Payloads) |
| WiFi-Reconnect | 30 s | Intervall bei getrennter STA |
| MQTT-Backoff | 5 s / 30 s | nach Erfolg / nach Fehlversuch |

---

## 13. Fehlersuche (Serial Monitor, 115200 Baud)

| Symptom | Ursache / Prüfung |
|---|---|
| `ADS1115 @ 0x48 nicht gefunden` | I²C-Verkabelung, Adress-Jumper, VCC/GND prüfen (I²C-Scan im Log). |
| `MPU6050 nicht gefunden – Fake-IMU aktiv` | Sensor auf 0x68/0x69? AD0-Pegel prüfen. Pitch/Roll sind dann simuliert. |
| Kanäle springen stark | LIVE-Modus im Motorraum ohne saubere Masse; ggf. Verkabelung/Abschirmung prüfen (4-fach-Mittelung ist bereits aktiv). |
| Keine MQTT-Daten | Broker-IP/Port, Erreichbarkeit; `boatopenio/status` = `online`? RSSI im Log. |
| Portal fragt Login, das AP-Passwort passt nicht | Portal-Login ≠ AP-Passwort. Portal-User/-Passwort aus der Ersteinrichtung nutzen. |
| POST wird mit `403 CSRF blocked` abgewiesen | Request kam nicht von der Portal-Seite selbst (fremder Origin). Direkt im Portal bedienen. |
| Config-Update per MQTT wirkt nicht | Payload > 4096 B, kein gültiges JSON, oder Sensor/Topic durch Filter geleert. |
| Aufprall-Alarm bleibt „true" hängen | Sollte durch Connect-Bereinigung verschwinden; im TEST-Modus liegen Alarme unter `boat/test/alarm/*`. |

---

*Teil der Serie „Logbook Without Posing" · [BoatOpenIO](https://github.com/bigbrainlabs/BoatOpenIO)*

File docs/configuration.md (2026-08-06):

# BoatOpenIO – Configuration Reference

There are three ways to configure BoatOpenIO. They complement each other — you don't have to use all of them.

---

## Overview

| What | Where stored | How to change |
|---|---|---|
| Channel mapping | LittleFS (`config.json`) | Web portal · MQTT · LittleFS upload |
| WiFi credentials | NVS (Preferences) | Web portal |
| MQTT connection | NVS (Preferences) | Web portal |
| AP credentials (SSID + password) | NVS (Preferences) | Web portal (Security card) · first-time setup |
| Portal credentials (user + password) | NVS (Preferences) | Web portal (Security card) · first-time setup |
| Test/Live mode | NVS (Preferences) | Web portal |
| IMU mounting offset | NVS (Preferences) | Web portal (IMU calibration) |
| Gyro bias | RAM only | Measured automatically at every boot |

NVS survives firmware updates. LittleFS `config.json` is only overwritten when you explicitly save via portal, MQTT, or re-upload the file.

---

## 1. Web Portal

### Access

| Address | Condition |
|---|---|
| `http://192.168.4.1` | Always — via the built-in AP |
| `http://boatopenio.local` | When connected to local network (mDNS) |
| `http://<IP>` | When connected to local network (IP shown in Serial Monitor) |

The portal requires **HTTP Basic Auth** after first-time setup. Enter the portal username and password set during `/setup`. This is separate from the AP password.

### First-Time Setup (`/setup`)

On first boot, all routes redirect to `/setup`. The portal is not accessible until a portal password is set here.

| Field | Requirement |
|---|---|
| Portal User | required |
| Portal Password | min. 6 characters |
| AP Name (SSID) | required |
| AP Password | min. 8 characters |

---

### WiFi & MQTT

```
WiFi SSID       your router's network name
WiFi Password   leave blank = keep existing
MQTT Server     IP or hostname, e.g. 192.168.1.100
MQTT Port       default 1883
MQTT User       leave blank if no auth
MQTT Password   leave blank = keep existing
```

→ Saved to NVS. Takes effect after restart.

---

### Channel Assignment

Each of the 16 terminals can be configured independently:

```
Sensor    sensor name — used as MQTT topic suffix if no custom topic is set
Factor    output = raw_voltage × factor + offset
Offset    additive offset (applied after factor)
Unit      string label, e.g. V · °C · bar · %  (display only)
Topic     custom MQTT topic — leave empty to use boat/io/<sensor>
          use the SK button to auto-fill a Signal K path
Active    only active channels are read and published to MQTT
```

> All 16 channels share a single ADS1115 @ 0x48. The CD74HC4067 MUX routes each channel in sequence — no ADS or pin selection needed.

→ Saved to LittleFS `config.json`. Takes effect immediately, no restart needed.

---

### IMU Calibration

```
Set Zero Now    stores current pitch/roll as mounting offset in NVS
                applied to all subsequent readings and MQTT publishes
```

Gyro bias (automatic): measured at boot over 100 samples (~0.5 s).  
Shown in the calibration card: `Gyro Bias: X=... Y=... Z=... rad/s`

The calibration card shows three rows for Pitch and Roll:

| Row | Description |
|-----|---|
| Raw | Gyro-bias-corrected angle, before mounting offset |
| Corrected | Final value — what gets published to MQTT |
| Offset | Stored mounting offset |

---

### Security

AP and portal credentials can be changed at any time in the **Security** card.

| Field | Requirement | Stored in |
|---|---|---|
| AP Name (SSID) | required | NVS `ap_ssid` |
| AP Password | min. 8 chars, blank = keep | NVS `ap_pass` |
| Portal User | required | NVS `portal_user` |
| Portal Password | min. 6 chars, blank = keep | NVS `portal_pass` |

A **yellow warning banner** is shown at the top of the portal as long as the AP password equals the factory default (`boatopenio`).

---

### API Endpoints

All endpoints are accessible without additional auth once the browser session is authenticated via Basic Auth.

| Endpoint | Method | Returns |
|---|---|---|
| `/api/values` | GET | Active channel values + pitch + roll (corrected) |
| `/api/raw` | GET | Raw ADS A0–A3 voltages (diagnostics) |
| `/api/adc?ch=<1–16>` | GET | Select MUX terminal, averaged voltage |
| `/api/imu` | GET | Pitch/roll raw, corrected, offset, gyro bias |
| `/calibrate` | POST | Sets current pitch/roll as mounting offset, returns new offsets |
| `/setinvert` | POST | Set pitch/roll inversion and axis swap |

> POST endpoints are additionally CSRF-protected (Origin/Referer must match the device).
> A full backend description is in [`backend.md`](backend.md).

---

## 2. config.json (LittleFS)

Stored on the ESP32's flash filesystem. Loaded at boot.

**Location on device:** `/config.json`  
**Local source:** `firmware_src/data/config.json`

### Structure

```json
{
  "kanaele": [
    {
      "klemme":  1,
      "sensor":  "battery_starter",
      "einheit": "V",
      "faktor":  3.127,
      "offset":  0.0,
      "aktiv":   true,
      "topic":   ""
    },
    {
      "klemme":  2,
      "sensor":  "oil_temp",
      "einheit": "°C",
      "faktor":  1.0,
      "offset":  0.0,
      "aktiv":   true,
      "topic":   "vessels/self/propulsion/engine/oilTemperature"
    }
  ]
}
```

### Field Reference

| Field | Type | Description |
|---|---|---|
| `klemme` | int 1–16 | Physical terminal number on the board |
| `sensor` | string | Sensor name — used as MQTT topic suffix when `topic` is empty |
| `einheit` | string | Unit label (display only) |
| `faktor` | float | Voltage multiplier: `value = voltage × faktor + offset` |
| `offset` | float | Additive offset after factor |
| `aktiv` | bool | `true` = channel is read and published |
| `topic` | string | Custom MQTT topic. Empty = publishes to `boat/io/<sensor>` |

### Voltage → Physical Value

Use the **Calibration Calculator** in the web portal (two-point, linear):
```
Per point: enter the real value of a known state + the measured ADS voltage
→ factor AND offset are computed and can be applied straight to the channel
```

Manual formula from two points (value₁@V₁, value₂@V₂):
```
faktor = (value₂ − value₁) / (V₂ − V₁)
offset = value₁ − faktor · V₁
```

For resistive VDO senders there is also an **Ω mode** (enter resistance instead of voltage,
converted via divider parameters). Details in [`backend.md`](backend.md) §8.

### How to Upload

1. Edit `firmware_src/data/config.json`
2. Arduino IDE → **Tools → ESP32 Sketch Data Upload**

Or: configure via the web portal — changes are saved to LittleFS automatically on every save.

---

## 3. MQTT

### Publish (ESP32 → Broker)

| Topic | Payload | Retained | Interval |
|---|---|---|---|
| `boat/io/<sensor>` or custom `topic` | float value | no | 2 s |
| `boat/io/pitch` | float °, corrected | yes | 1 s |
| `boat/io/roll` | float °, corrected | yes | 1 s |
| `boatopenio/status` | `online` / `offline` | yes | 10 s + LWT |
| `boatopenio/uptime` | seconds since boot | no | 10 s |
| `boatopenio/rssi` | WiFi signal dBm | no | 10 s |
| `boatopenio/mode` | `TEST` / `LIVE` | yes | 10 s |
| `boat/alarm/impact_g` ¹ | peak G value | yes | on event |
| `boat/alarm/impact_severity` ¹ | `LEICHT` / `MITTEL` / `STARK` / `KRITISCH` | yes | on event |
| `boat/alarm/impact_active` ¹ | `true` / `false` | yes | on event |

¹ In **TEST** mode the prefix is `boat/test/alarm/` instead of `boat/alarm/`.

### Subscribe (Broker → ESP32)

#### Update channel config

```
Topic:   boatopenio/config
Payload: full or partial config.json structure (JSON)
```

Overwrites the current channel configuration in memory and saves to LittleFS. Partial updates are supported — only fields present in the payload are changed.

**Example — activate one channel with a custom Signal K topic:**
```json
{
  "kanaele": [
    {"klemme": 3, "sensor": "oil_pressure", "faktor": 1.25, "aktiv": true, "topic": "vessels/self/propulsion/engine/oilPressure"}
  ]
}
```

---

## 4. NVS (Non-Volatile Storage)

Stored in the ESP32's NVS partition under namespace `boatopenio`. Survives firmware flashing (unless a full factory reset is performed).

| Key | Type | Default | Description |
|-----|---|---|---|
| `wifi_ssid` | string | `""` | WiFi network name |
| `wifi_pass` | string | `""` | WiFi password |
| `mqtt_ip` | string | `192.168.1.100` | MQTT broker address |
| `mqtt_port` | string | `1883` | MQTT broker port |
| `mqtt_user` | string | `""` | MQTT username |
| `mqtt_pass` | string | `""` | MQTT password |
| `testmode` | bool | `true` | Test mode active |
| `pitch_off` | float | `0.0` | IMU pitch mounting offset (°) |
| `roll_off` | float | `0.0` | IMU roll mounting offset (°) |
| `ap_ssid` | string | `BoatOpenIO-Setup` | AP network name |
| `ap_pass` | string | `boatopenio` | AP password |
| `portal_user` | string | `admin` | Web portal username |
| `portal_pass` | string | `""` | Web portal password (empty = first-time setup required) |

NVS is **not** accessible directly. All values are managed via the web portal or cleared by a factory reset.

---

## 5. Factor & Offset Calculation

The conversion formula for every channel:

```
published_value = raw_voltage × faktor + offset
```

### Common examples

**12V battery via resistor divider (R1=30kΩ, R2=10kΩ):**
```
ADS reads max 3.127V when battery is at 12.5V
faktor = 12.5 / 3.127 ≈ 4.0
offset = 0.0
```

**VDO oil pressure sender (0–150 psi, 10–180Ω):**
```
Requires voltage divider board (VT) first
Measure actual voltage at ADS pin and real pressure with gauge
faktor = real_pressure / ads_voltage
```

**NTC temperature sensor (linearized range):**
```
Use the calibration calculator in the web portal
Measure two points, calculate factor and offset from the linear fit
```

**Direct 3.3V signal:**
```
faktor = 1.0
offset = 0.0
```

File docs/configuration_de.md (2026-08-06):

# BoatOpenIO – Konfigurationsreferenz

Es gibt drei Wege BoatOpenIO zu konfigurieren. Sie ergänzen sich — nicht alle müssen genutzt werden.

---

## Übersicht

| Was | Wo gespeichert | Wie ändern |
|-----|---|---|
| Kanalzuordnung | LittleFS (`config.json`) | Web-Portal · MQTT · LittleFS-Upload |
| WiFi-Zugangsdaten | NVS (Preferences) | Web-Portal |
| MQTT-Verbindung | NVS (Preferences) | Web-Portal |
| AP-Zugangsdaten (SSID + Passwort) | NVS (Preferences) | Web-Portal (Sicherheit) · Ersteinrichtung |
| Portal-Zugangsdaten (Benutzer + Passwort) | NVS (Preferences) | Web-Portal (Sicherheit) · Ersteinrichtung |
| Test/Live-Modus | NVS (Preferences) | Web-Portal |
| IMU-Montage-Offset | NVS (Preferences) | Web-Portal (IMU-Kalibrierung) |
| Gyro-Bias | Nur RAM | Automatisch bei jedem Neustart gemessen |

NVS überlebt Firmware-Updates. LittleFS `config.json` wird nur überschrieben, wenn explizit über das Portal, MQTT oder einen Datei-Upload gespeichert wird.

---

## 1. Web-Portal

### Erreichbarkeit

| Adresse | Voraussetzung |
|---|---|
| `http://192.168.4.1` | Immer — über den integrierten AP |
| `http://boatopenio.local` | Bei WLAN-Verbindung im lokalen Netz (mDNS) |
| `http://<IP>` | Bei WLAN-Verbindung im lokalen Netz (IP im Serial Monitor) |

Das Portal erfordert **HTTP Basic Auth** nach der Ersteinrichtung. Portal-Benutzername und -Passwort eingeben (gesetzt bei `/setup`). Diese sind unabhängig vom AP-Passwort.

### Ersteinrichtung (`/setup`)

Beim ersten Start leiten alle Routen auf `/setup` um. Das Portal ist erst nach dem Setzen eines Portal-Passworts zugänglich.

| Feld | Anforderung |
|---|---|
| Portal-Benutzer | erforderlich |
| Portal-Passwort | min. 6 Zeichen |
| AP-Name (SSID) | erforderlich |
| AP-Passwort | min. 8 Zeichen |

---

### WiFi & MQTT

```
WiFi SSID       Name des Heim-/Bordsnetzes
WiFi Passwort   Leer = bestehendes Passwort beibehalten
MQTT Server     IP oder Hostname, z.B. 192.168.1.100
MQTT Port       Standard: 1883
MQTT User       Leer wenn keine Authentifizierung nötig
MQTT Passwort   Leer = bestehendes Passwort beibehalten
```

→ In NVS gespeichert. Wirksam nach Neustart.

---

### Kanalzuordnung

Jede der 16 Klemmen kann unabhängig konfiguriert werden:

```
Sensor    Sensorname — als MQTT-Topic-Suffix verwendet, wenn kein Topic gesetzt ist
Faktor    Ausgabe = Rohspannung × Faktor + Offset
Offset    Additiver Offset nach dem Faktor
Einheit   Einheitenkürzel, z.B. V · °C · bar · %  (nur Anzeige)
Topic     Eigener MQTT-Topic — leer lassen für boat/io/<sensor>
          SK-Button füllt Signal K-Pfad automatisch ein
Aktiv     Nur aktive Kanäle werden gelesen und an MQTT publiziert
```

> Alle 16 Kanäle teilen sich einen einzigen ADS1115 @ 0x48. Der CD74HC4067 MUX schaltet die Kanäle der Reihe nach durch — keine ADS- oder Pin-Auswahl nötig.

→ In LittleFS `config.json` gespeichert. Sofort wirksam, kein Neustart nötig.

---

### IMU-Kalibrierung

```
Jetzt Null setzen    Speichert aktuellen Pitch/Roll als Montage-Offset in NVS
                     Wird auf alle nachfolgenden Messwerte und MQTT-Publizierungen angewendet
```

Gyro-Bias (automatisch): beim Booten über 100 Samples gemessen (~0,5 s).  
In der Kalibrierungs-Card angezeigt: `Gyro-Bias: X=... Y=... Z=... rad/s`

Die Kalibrierungs-Card zeigt drei Zeilen für Pitch und Roll:

| Zeile | Beschreibung |
|---|---|
| Rohwert | Gyro-Bias-korrigierter Winkel, vor Montage-Offset |
| Korrigiert | Endwert — wird an MQTT publiziert |
| Offset | Gespeicherter Montage-Offset |

---

### Sicherheit

AP- und Portal-Zugangsdaten können jederzeit in der **Sicherheit**-Card geändert werden.

| Feld | Anforderung | Gespeichert in |
|---|---|---|
| AP-Name (SSID) | erforderlich | NVS `ap_ssid` |
| AP-Passwort | min. 8 Zeichen, leer = beibehalten | NVS `ap_pass` |
| Portal-Benutzer | erforderlich | NVS `portal_user` |
| Portal-Passwort | min. 6 Zeichen, leer = beibehalten | NVS `portal_pass` |

Solange das AP-Passwort dem Werksstandard (`boatopenio`) entspricht, wird oben im Portal ein **gelber Warnhinweis** angezeigt.

---

### API-Endpunkte

Alle Endpunkte sind im authentifizierten Browser-Session ohne weitere Anmeldung erreichbar.

| Endpunkt | Methode | Liefert |
|---|---|---|
| `/api/values` | GET | Aktive Kanalwerte + Pitch + Roll (korrigiert) |
| `/api/raw` | GET | Rohspannungen ADS A0–A3 (Diagnose) |
| `/api/adc?ch=<1–16>` | GET | MUX auf Klemme wählen, gemittelte Spannung |
| `/api/imu` | GET | Pitch/Roll roh, korrigiert, Offset, Gyro-Bias |
| `/calibrate` | POST | Setzt aktuellen Pitch/Roll als Montage-Offset, gibt neue Offsets zurück |
| `/setinvert` | POST | Pitch-/Roll-Invertierung und Achsentausch setzen |

> POST-Endpunkte sind zusätzlich CSRF-geschützt (Origin/Referer muss zum Gerät passen).
> Eine vollständige Backend-Beschreibung steht in [`backend_de.md`](backend_de.md).

---

## 2. config.json (LittleFS)

Auf dem Flash-Dateisystem des ESP32 gespeichert. Wird beim Booten geladen.

**Pfad auf dem Gerät:** `/config.json`  
**Lokale Quelle:** `firmware_src/data/config.json`

### Struktur

```json
{
  "kanaele": [
    {
      "klemme":  1,
      "sensor":  "batterie_starter",
      "einheit": "V",
      "faktor":  3.127,
      "offset":  0.0,
      "aktiv":   true,
      "topic":   ""
    },
    {
      "klemme":  2,
      "sensor":  "oeltemperatur",
      "einheit": "°C",
      "faktor":  1.0,
      "offset":  0.0,
      "aktiv":   true,
      "topic":   "vessels/self/propulsion/engine/oilTemperature"
    }
  ]
}
```

### Feldreferenz

| Feld | Typ | Beschreibung |
|---|-----|---|
| `klemme` | int 1–16 | Physische Klemmennummer auf der Platine |
| `sensor` | string | Sensorname — als MQTT-Topic-Suffix verwendet, wenn `topic` leer ist |
| `einheit` | string | Einheitenkürzel (nur Anzeige) |
| `faktor` | float | Spannungsmultiplikator: `Wert = Spannung × faktor + offset` |
| `offset` | float | Additiver Offset nach dem Faktor |
| `aktiv` | bool | `true` = Kanal wird gelesen und publiziert |
| `topic` | string | Eigener MQTT-Topic. Leer = publiziert auf `boat/io/<sensor>` |

### Spannung → Physikalischer Wert

Den **Kalibrierungs-Rechner** im Web-Portal nutzen (Zwei-Punkt, linear):
```
Pro Punkt: echten Wert eines bekannten Zustands + gemessene ADS-Spannung eintragen
→ Faktor UND Offset werden berechnet und lassen sich direkt in den Kanal übernehmen
```

Manuelle Formel aus zwei Punkten (Wert₁@V₁, Wert₂@V₂):
```
faktor = (Wert₂ − Wert₁) / (V₂ − V₁)
offset = Wert₁ − faktor · V₁
```

Für resistive VDO-Geber gibt es zusätzlich einen **Ω-Modus** (Widerstand statt Spannung
eingeben, Umrechnung über Teilerparameter). Details in [`backend_de.md`](backend_de.md) §8.

### Hochladen

1. `firmware_src/data/config.json` bearbeiten
2. Arduino IDE → **Tools → ESP32 Sketch Data Upload**

Alternativ: Konfiguration über das Web-Portal — Änderungen werden automatisch in LittleFS gespeichert.

---

## 3. MQTT

### Publizieren (ESP32 → Broker)

| Topic | Payload | Retained | Intervall |
|---|---|---|---|
| `boat/io/<sensor>` oder eigener `topic` | Float-Wert | nein | 2 s |
| `boat/io/pitch` | Float °, korrigiert | ja | 1 s |
| `boat/io/roll` | Float °, korrigiert | ja | 1 s |
| `boatopenio/status` | `online` / `offline` | ja | 10 s + LWT |
| `boatopenio/uptime` | Sekunden seit Boot | nein | 10 s |
| `boatopenio/rssi` | WLAN-Signal dBm | nein | 10 s |
| `boatopenio/mode` | `TEST` / `LIVE` | ja | 10 s |
| `boat/alarm/impact_g` ¹ | Peak-G-Wert | ja | bei Ereignis |
| `boat/alarm/impact_severity` ¹ | `LEICHT` / `MITTEL` / `STARK` / `KRITISCH` | ja | bei Ereignis |
| `boat/alarm/impact_active` ¹ | `true` / `false` | ja | bei Ereignis |

¹ Im **TEST**-Modus lautet das Präfix `boat/test/alarm/` statt `boat/alarm/`.

### Abonnieren (Broker → ESP32)

#### Kanalkonfiguration aktualisieren

```
Topic:   boatopenio/config
Payload: vollständige oder partielle config.json-Struktur (JSON)
```

Überschreibt die aktuelle Kanalkonfiguration im Speicher und speichert in LittleFS. Partielle Updates werden unterstützt — nur im Payload vorhandene Felder werden geändert.

**Beispiel — einen Kanal mit eigenem Signal K-Topic aktivieren:**
```json
{
  "kanaele": [
    {"klemme": 3, "sensor": "oeldruck", "faktor": 1.25, "aktiv": true, "topic": "vessels/self/propulsion/engine/oilPressure"}
  ]
}
```

---

## 4. NVS (Non-Volatile Storage)

Im NVS-Partition des ESP32 unter dem Namespace `boatopenio` gespeichert. Überlebt Firmware-Updates (außer bei vollständigem Werksreset).

| Schlüssel | Typ | Standard | Beschreibung |
|---|-----|---|---|
| `wifi_ssid` | string | `""` | WLAN-Netzwerkname |
| `wifi_pass` | string | `""` | WLAN-Passwort |
| `mqtt_ip` | string | `192.168.1.100` | MQTT-Broker-Adresse |
| `mqtt_port` | string | `1883` | MQTT-Broker-Port |
| `mqtt_user` | string | `""` | MQTT-Benutzername |
| `mqtt_pass` | string | `""` | MQTT-Passwort |
| `testmode` | bool | `true` | Test-Modus aktiv |
| `pitch_off` | float | `0.0` | IMU Pitch-Montage-Offset (°) |
| `roll_off` | float | `0.0` | IMU Roll-Montage-Offset (°) |
| `ap_ssid` | string | `BoatOpenIO-Setup` | AP-Netzwerkname |
| `ap_pass` | string | `boatopenio` | AP-Passwort |
| `portal_user` | string | `admin` | Web-Portal-Benutzername |
| `portal_pass` | string | `""` | Web-Portal-Passwort (leer = Ersteinrichtung erforderlich) |

Der NVS ist **nicht** direkt zugänglich. Alle Werte werden über das Web-Portal verwaltet oder durch einen Werksreset gelöscht.

---

## 5. Faktor- & Offset-Berechnung

Umrechnungsformel für jeden Kanal:

```
publizierter_wert = rohspannung × faktor + offset
```

### Typische Beispiele

**12V-Batterie über Spannungsteiler (R1=30kΩ, R2=10kΩ):**
```
ADS misst max. 3,127V wenn Batterie bei 12,5V
faktor = 12,5 / 3,127 ≈ 4,0
offset = 0,0
```

**VDO-Öldruckgeber (0–150 psi, 10–180Ω):**
```
Zuerst Spannungsteiler-Platine (VT) erforderlich
Tatsächliche Spannung am ADS-Pin und Realdruck mit Manometer messen
faktor = realdruck / ads_spannung
```

**NTC-Temperatursensor (linearisierter Bereich):**
```
Kalibrierungs-Hilfsrechner im Web-Portal nutzen
Zwei Messpunkte messen, Faktor und Offset aus linearer Interpolation berechnen
```

**Direktes 3,3V-Signal:**
```
faktor = 1,0
offset = 0,0
```

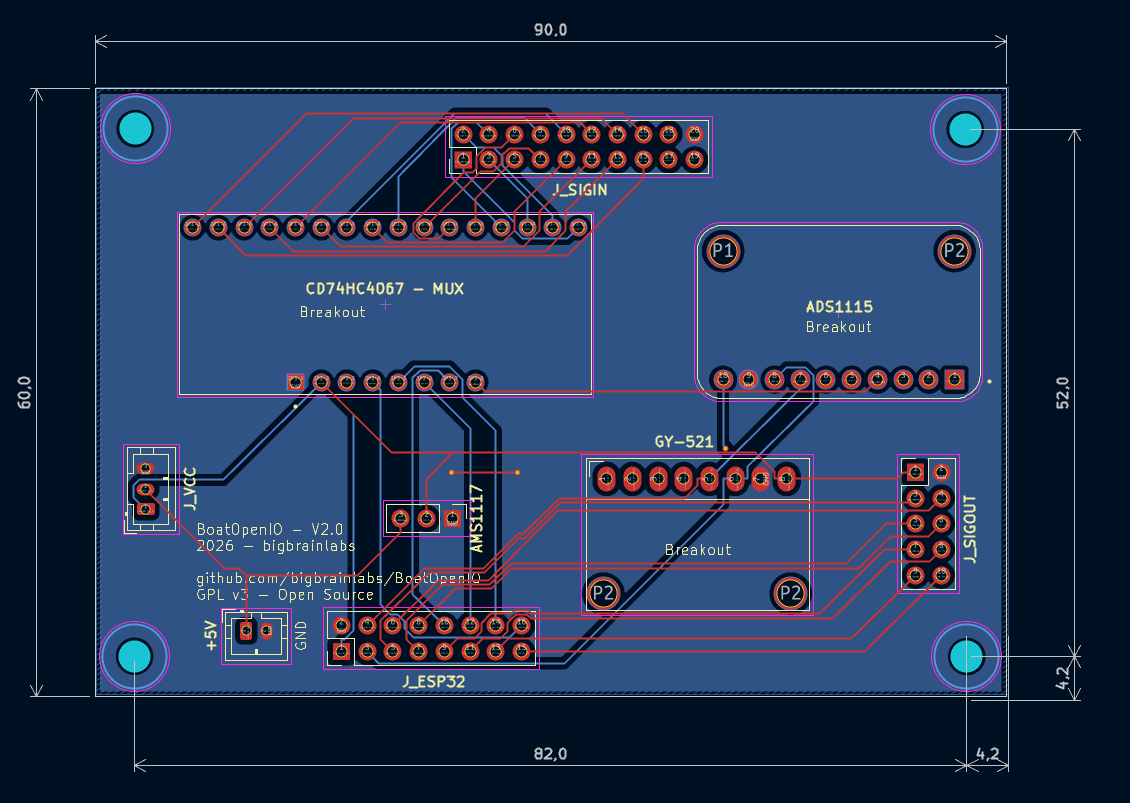
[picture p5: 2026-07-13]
images/main.png

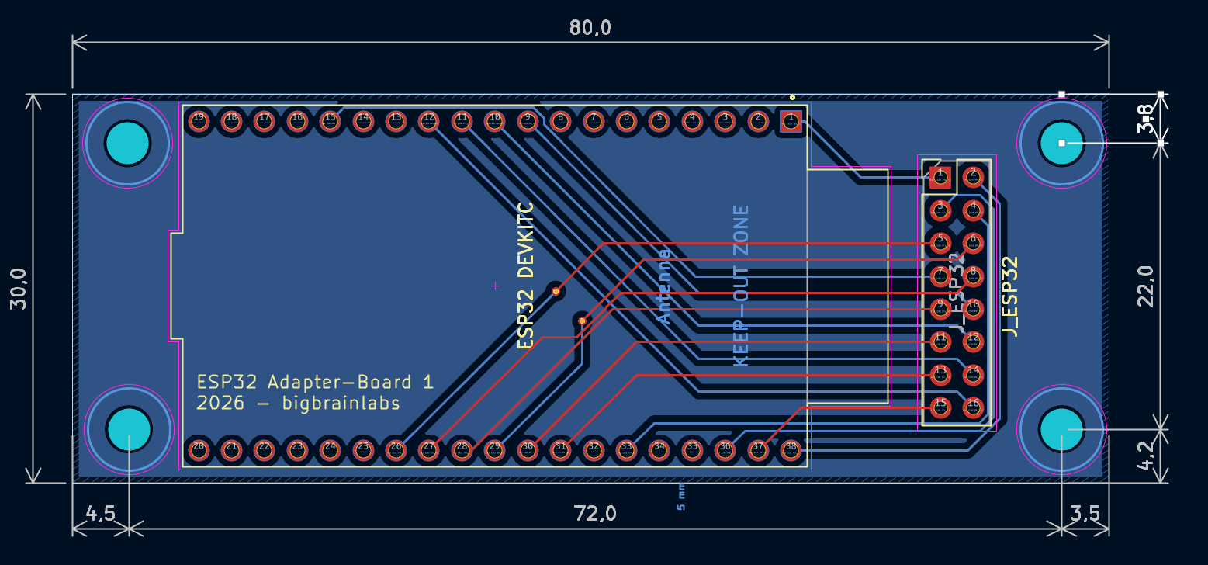
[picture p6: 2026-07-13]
images/esp-adapter.png

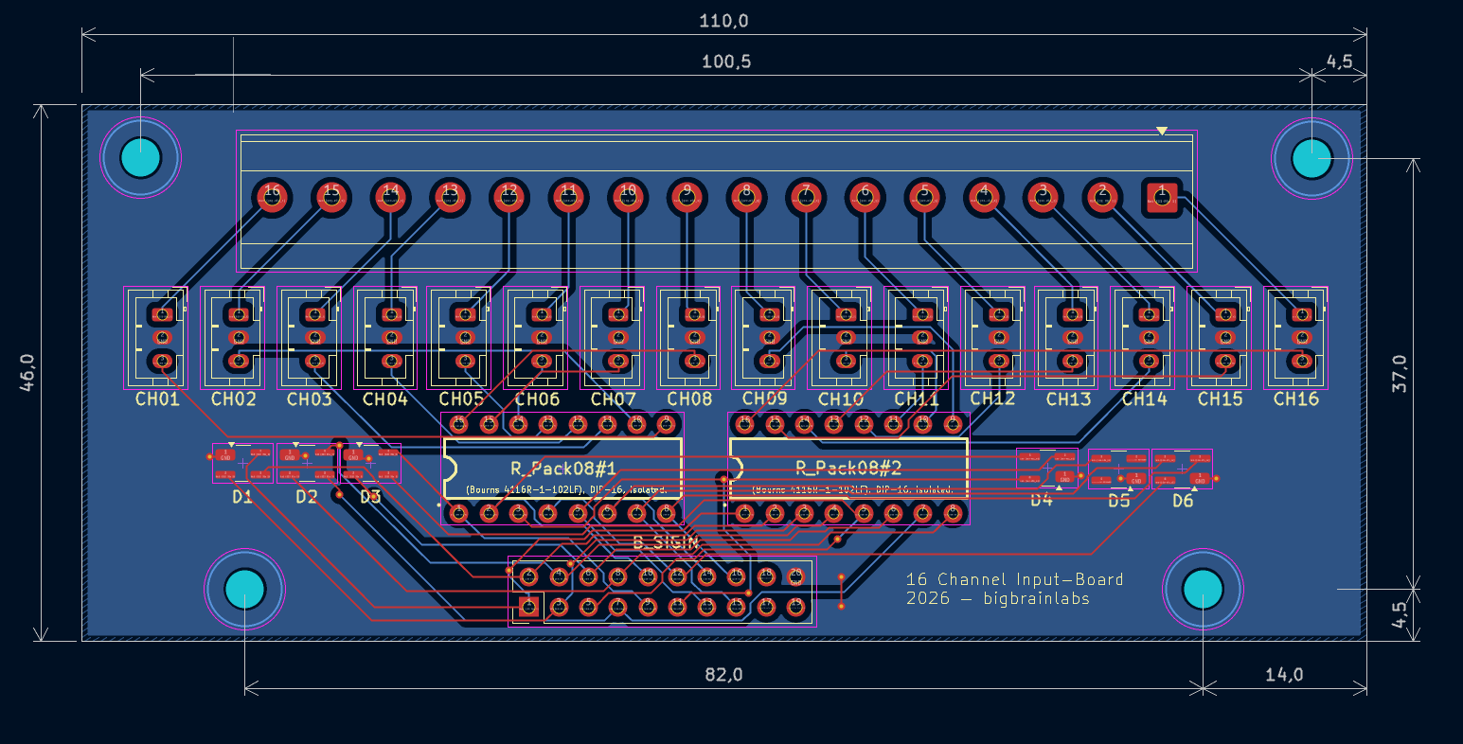
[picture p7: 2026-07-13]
images/sigin.png

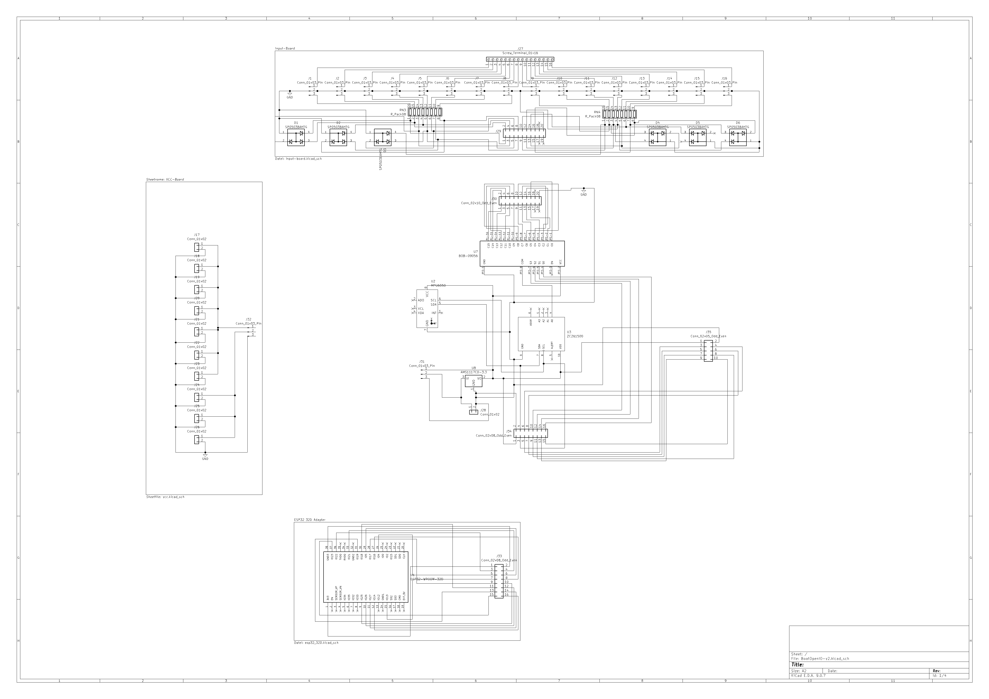
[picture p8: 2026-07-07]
images/schaltplan_v2.png

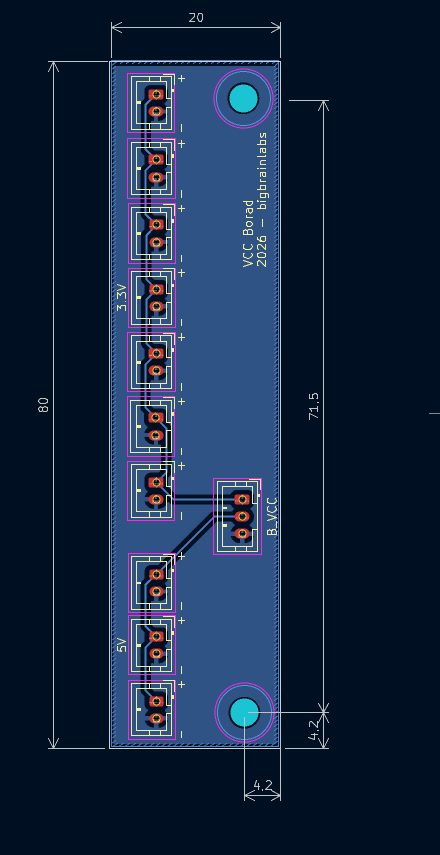
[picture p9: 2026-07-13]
images/vcc.png

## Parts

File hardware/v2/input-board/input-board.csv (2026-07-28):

Reference | Qty | Value | DNP | Exclude from BOM | Exclude from Board | Footprint | Datasheet
D1,D2,D3,D4,D5,D6,D7,D8,D9,D10,D11,D12,D13,D14,D15,D16 | 16 | D_Zener |  |  |  | PCM_Diode_SMD_AKL:D_SOD-123_Zener | ~
J1,J2,J3,J4,J5,J6,J7,J8,J9,J10,J11,J12,J13,J14,J15,J16 | 16 | Conn_01x03_Pin | Nicht bestücken |  |  | Connector_JST:JST_PH_B3B-PH-K_1x03_P2.00mm_Vertical | ~
J27 | 1 | Screw_Terminal_01x16 | Nicht bestücken |  |  | TerminalBlock_Phoenix:TerminalBlock_Phoenix_MKDS-3-16-5.08_1x16_P5.08mm_Horizontal | ~
J29 | 1 | Conn_02x10_Odd_Even | Nicht bestücken |  |  | Connector_PinHeader_2.54mm:PinHeader_2x10_P2.54mm_Vertical | ~
R1,R2,R3,R4,R5,R6,R7,R8,R9,R10,R11,R12,R13,R14,R15,R16 | 16 | 1k |  |  |  | Resistor_SMD:R_0805_2012Metric
R17,R18,R19,R20,R21,R22,R23,R24,R25,R26,R27,R28,R29,R30,R31,R32 | 16 | 1M |  |  |  | Resistor_SMD:R_0805_2012Metric

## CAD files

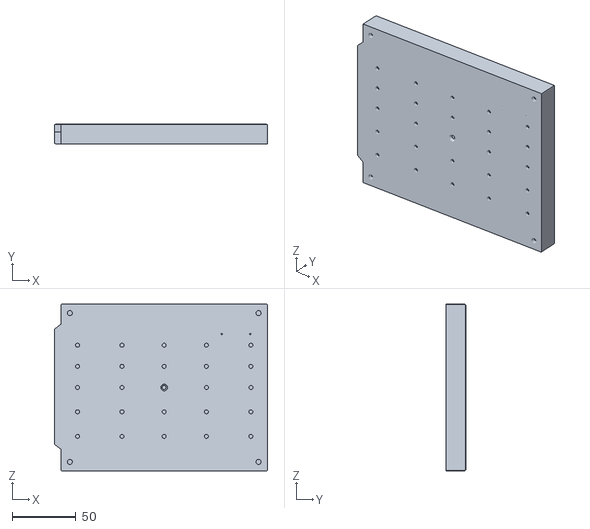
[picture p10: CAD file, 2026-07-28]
hardware/enclosures/community/Bernd/main obj.obj
166.6 x 15.3 x 130.4

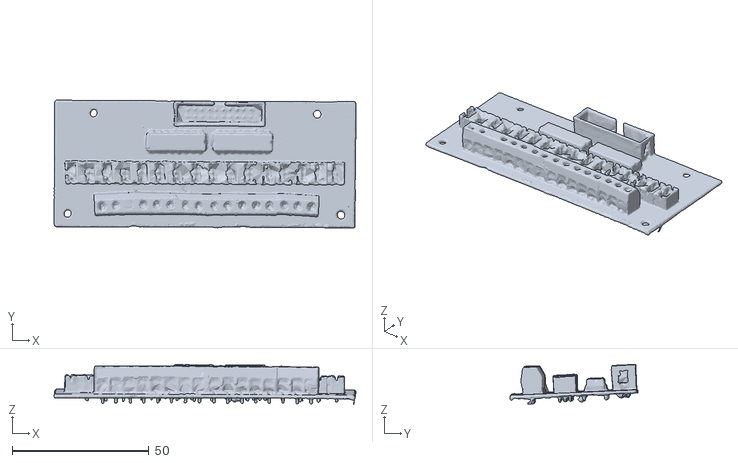
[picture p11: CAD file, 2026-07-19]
hardware/enclosures/reference_scans/SensorBoard-V1.stl
110.5 x 47.0 x 14.7

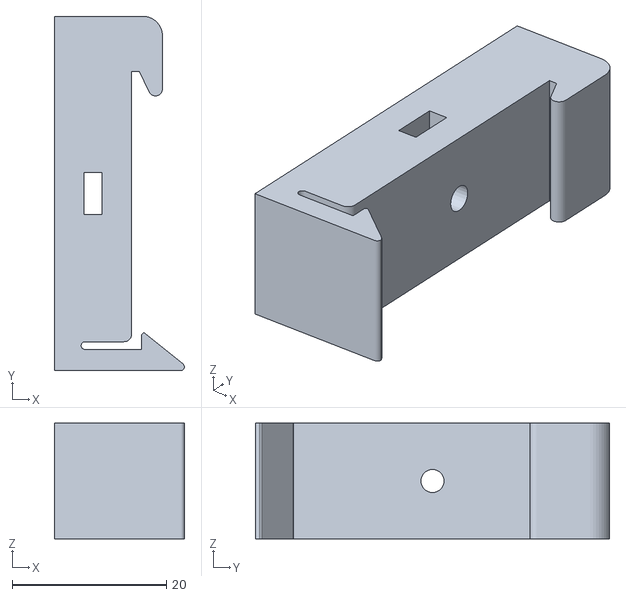
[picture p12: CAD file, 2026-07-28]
hardware/enclosures/community/Bernd/HutschienenMontage V2.stl
16.9 x 46.0 x 15.0

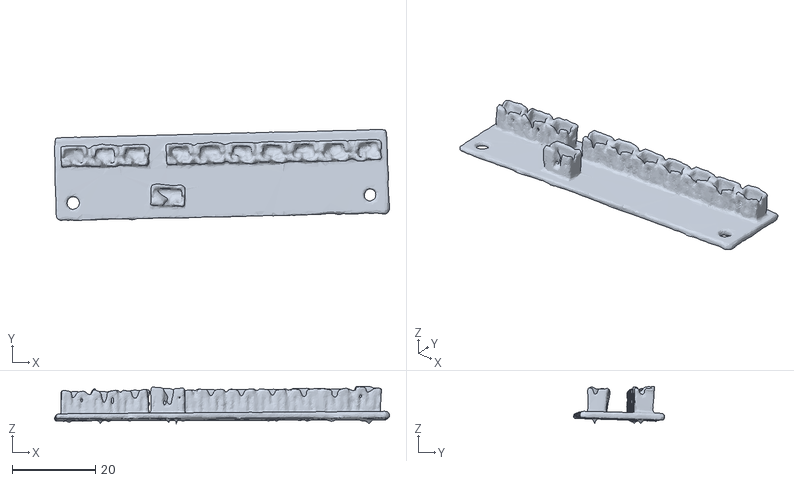
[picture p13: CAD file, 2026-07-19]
hardware/enclosures/reference_scans/VCC-Board-V1.stl
80.7 x 21.9 x 8.95

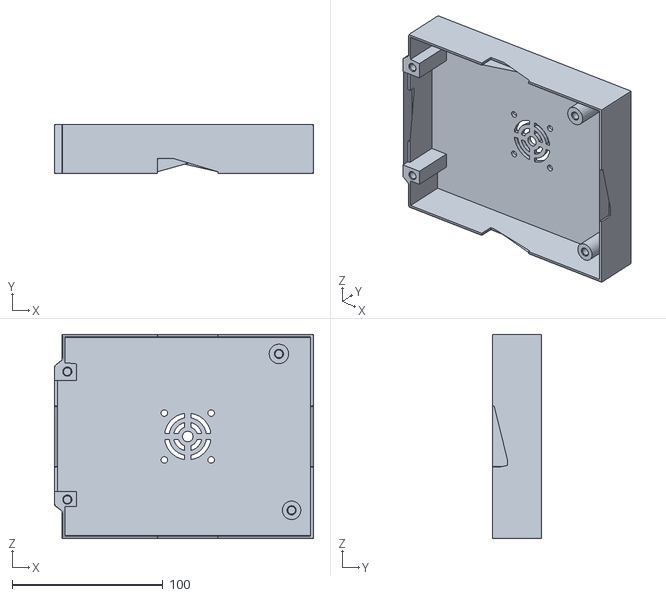
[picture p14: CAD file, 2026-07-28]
hardware/enclosures/community/Bernd/Lid Obj.obj
171.6 x 32.7 x 135.4

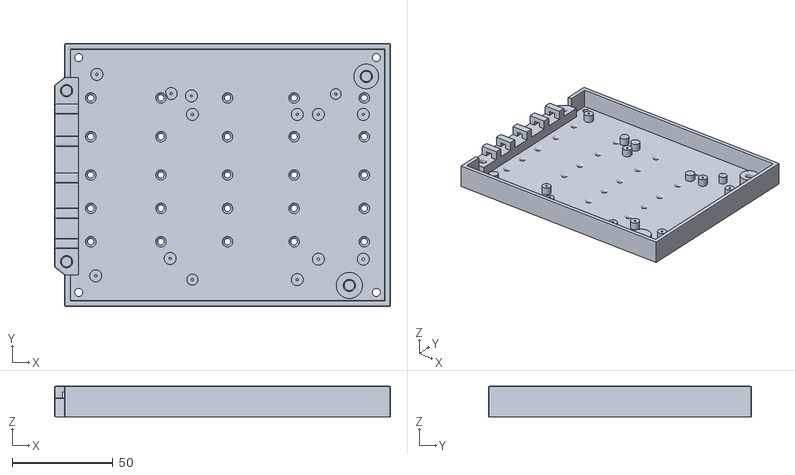
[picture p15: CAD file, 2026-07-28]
hardware/enclosures/community/Bernd/Boden V2.stl
166.6 x 130.4 x 15.3

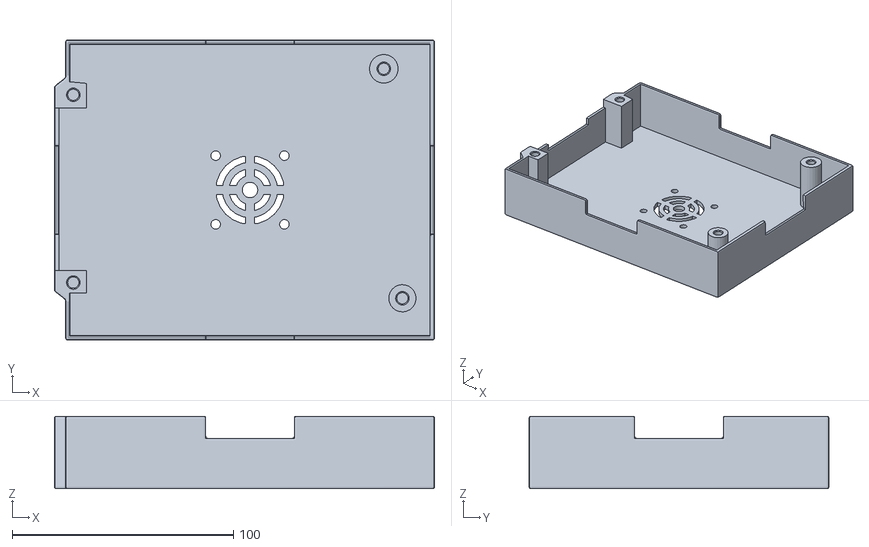
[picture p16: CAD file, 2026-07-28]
hardware/enclosures/community/Bernd/deckel V2.stl
171.6 x 135.4 x 32.7

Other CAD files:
hardware/enclosures/community/Bernd/dinrail.obj

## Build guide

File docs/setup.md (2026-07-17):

# BoatOpenIO – Setup Guide

## Requirements

**Hardware** — the v2 board set (input, main, ESP32 adapter, VCC). Either order the Gerbers in `hardware/v2/*/gerber/` at a PCB fab yourself, or get the ready-made set on [Tindie](https://www.tindie.com/products/bigbrainlabs/boatopenio-v2-pcb-set-4-boards/) (bare boards — components per the parts list in the [README](../README.md)).

**Software**

- Arduino IDE 1.8+ or 2.x
- ESP32 board package installed (`espressif/arduino-esp32`)
- Required libraries (install via Library Manager):
  - `Adafruit ADS1X15`
  - `Adafruit MPU6050`
  - `Adafruit Unified Sensor`
  - `PubSubClient`
  - `ArduinoJson` (v7)
  - `ESP32 Arduino` (includes `WebServer`, `ESPmDNS`, `ArduinoOTA`, `Preferences`, `LittleFS`)
- [ESP32 Sketch Data Upload plugin](https://github.com/me-no-dev/arduino-esp32fs-plugin) for LittleFS

---

## 1. Flash the Firmware

1. Open `firmware_src/firmware_src.ino` in Arduino IDE
2. Select board: **ESP32 Dev Module** (or your specific variant)
3. Set upload speed: **921600**
4. Select the correct COM port
5. Click **Upload**

---

## 2. Upload the Channel Configuration (LittleFS)

The default channel mapping is stored in `firmware_src/data/config.json`.

1. Install the [ESP32 Sketch Data Upload](https://github.com/me-no-dev/arduino-esp32fs-plugin) plugin
2. In Arduino IDE: **Tools → ESP32 Sketch Data Upload**
3. The `data/` folder is uploaded to LittleFS on the ESP32

> **Note:** This step is only needed on first flash or after a factory reset. Changes made via the web portal are saved automatically to LittleFS and survive reboots.

---

## 3. First Boot & Security Setup

On first boot the ESP32 starts its access point with default credentials:

```
AP:  BoatOpenIO-Setup
Key: boatopenio
IP:  192.168.4.1
```

Connect your phone or laptop to the AP. The browser opens the setup page automatically (captive portal). On desktop navigate to `http://192.168.4.1/setup`.

> **Important:** The portal is not accessible until the first-time setup is completed. All routes redirect to `/setup` until a portal password is set.

### First-Time Setup (`/setup`)

Fill in the form before anything else is accessible:

| Field | Requirement | Description |
|---|---|---|
| Portal User | required | Username for web portal login |
| Portal Password | min. 6 chars | Protects the entire configuration portal |
| Confirm Password | must match | |
| AP Name (SSID) | required | Name of the WiFi access point broadcast by the ESP32 |
| AP Password | min. 8 chars | Key required to connect to the AP |

Click **Complete Setup**. The ESP32 saves credentials to NVS and restarts.

> **After setup:** The portal requires HTTP Basic Auth on every visit. The browser will prompt for username and password. These are the credentials you just set — not the AP password.

---

## 4. Configure WiFi & MQTT

Log in to the portal (`http://192.168.4.1`, credentials from step 3), then scroll to **WiFi & MQTT**:

| Field | Description |
|---|---|
| WiFi SSID | Your router's network name |
| WiFi Password | Leave blank to keep the existing password |
| MQTT Server | IP or hostname of your MQTT broker |
| MQTT Port | Default: `1883` |
| MQTT User | Leave blank if no auth required |
| MQTT Password | Leave blank to keep the existing password |

Click **Save & Restart**. The ESP32 reboots and connects to your router.  
The AP remains active at `192.168.4.1` regardless of WiFi status.

---

## 5. Assign Channels

In the portal, scroll to **Channel Assignment**:

| Column | Description |
|---|---|
| # | Terminal number (1–16, physical connector) |
| Sensor | Sensor name — used as MQTT topic suffix if no custom topic is set |
| Factor | Multiplier: `output = voltage × factor + offset` |
| Offset | Additive offset after factor |
| Unit | Unit string (display only, not used in MQTT) |
| Topic | Custom MQTT topic. If left empty, publishes to `boat/io/<sensor>`. Use the **SK** button to auto-fill the correct Signal K path for common sensor names. |
| Active | Only active channels are read and published |

> All 16 channels share a single ADS1115 @ 0x48. The CD74HC4067 MUX routes each channel in sequence — no ADS or pin selection needed.

Click **Save Configuration**. Settings are written to LittleFS immediately, no restart needed.

---

## 6. Change Credentials (Security Card)

The **Security** section in the portal lets you update AP and portal credentials at any time.

| Field | Requirement | Effect |
|---|---|---|
| AP Name (SSID) | required | New AP name after restart |
| AP Password | min. 8 chars, leave blank to keep | New AP key after restart |
| Portal User | required | New portal login username |
| Portal Password | min. 6 chars, leave blank to keep | New portal login password |
| Confirm Password | must match portal password | |

> **Warning banner:** If the AP password is still the factory default (`boatopenio`), a yellow warning is shown at the top of the portal. Change it here.

---

## 7. Calibrate IMU (optional)

The MPU6050 runs two-stage calibration:

**Gyro bias** is measured automatically at every boot (~0.5 s, keep the board still during power-on).

**Mounting offset** corrects for the board's installation angle:

1. Scroll to **IMU Calibration** in the portal
2. Place the boat on calm water (or a level surface)
3. Watch the live Pitch/Roll readout stabilize
4. Click **Set Zero Now**

The offset is saved to NVS and applied to all future readings and MQTT publishes.

---

## 8. Test Mode vs. Live Mode

The firmware starts in **Test Mode** by default.

| Mode | Behaviour |
|---|---|
| TEST | Simulated sinusoidal sensor values — safe for commissioning |
| LIVE | Real ADC readings from the ADS1115 chips |

Toggle in the **Actions** section of the portal.

---

## 9. OTA Firmware Updates

Once the ESP32 is on your WiFi network, firmware can be updated over the air:

1. In Arduino IDE, select the network port: **BoatOpenIO at \<IP\>**
2. Enter the **portal password** (set during first-time setup) when prompted
3. Click **Upload** — no USB cable needed

mDNS hostname: `boatopenio.local` (on networks that support mDNS).

> **Note:** Before first-time setup is complete, the OTA password falls back to `boatopenio`.

---

## 10. Factory Reset

**At runtime** — hold GPIO0 button for 3 seconds:  
→ Clears WiFi credentials only. All other settings (MQTT, channels, portal credentials, IMU offset) are kept.

**At boot** — hold GPIO0 button while powering on, keep holding for 3 seconds:  
→ Full factory reset: clears all NVS entries (WiFi, MQTT, portal credentials, AP credentials, IMU offsets) and removes `config.json` from LittleFS.

After a full factory reset the first-time setup at `/setup` is required again before the portal becomes accessible. Re-upload `config.json` via the LittleFS tool (step 2).

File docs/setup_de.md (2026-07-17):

# BoatOpenIO – Einrichtungsanleitung

## Voraussetzungen

**Hardware** — das v2-Platinen-Set (Eingang, Main, ESP32-Adapter, VCC). Entweder die Gerber-Dateien aus `hardware/v2/*/gerber/` selbst bei einem Platinenhersteller bestellen, oder das fertige Set bei [Tindie](https://www.tindie.com/products/bigbrainlabs/boatopenio-v2-pcb-set-4-boards/) kaufen (nackte Platinen — Bauteile laut Stückliste in der [README](../README_de.md)).

**Software**

- Arduino IDE 1.8+ oder 2.x
- ESP32-Board-Paket installiert (`espressif/arduino-esp32`)
- Benötigte Bibliotheken (über den Library Manager installieren):
  - `Adafruit ADS1X15`
  - `Adafruit MPU6050`
  - `Adafruit Unified Sensor`
  - `PubSubClient`
  - `ArduinoJson` (v7)
  - `ESP32 Arduino` (enthält `WebServer`, `ESPmDNS`, `ArduinoOTA`, `Preferences`, `LittleFS`)
- [ESP32 Sketch Data Upload Plugin](https://github.com/me-no-dev/arduino-esp32fs-plugin) für LittleFS

---

## 1. Firmware flashen

1. `firmware_src/firmware_src.ino` in der Arduino IDE öffnen
2. Board auswählen: **ESP32 Dev Module** (oder die eigene Variante)
3. Upload-Geschwindigkeit: **921600**
4. Richtigen COM-Port auswählen
5. **Upload** klicken

---

## 2. Kanalkonfiguration hochladen (LittleFS)

Die Standard-Kanalzuordnung liegt in `firmware_src/data/config.json`.

1. [ESP32 Sketch Data Upload Plugin](https://github.com/me-no-dev/arduino-esp32fs-plugin) installieren
2. In der Arduino IDE: **Tools → ESP32 Sketch Data Upload**
3. Der `data/`-Ordner wird auf das LittleFS des ESP32 hochgeladen

> **Hinweis:** Dieser Schritt ist nur beim ersten Flash oder nach einem Werksreset nötig. Änderungen über das Web-Portal werden automatisch in LittleFS gespeichert und überleben Neustarts.

---

## 3. Erster Start & Sicherheitseinrichtung

Beim ersten Start öffnet der ESP32 seinen Access Point mit den Standard-Zugangsdaten:

```
AP:       BoatOpenIO-Setup
Passwort: boatopenio
IP:       192.168.4.1
```

Mit dem AP verbinden. Auf Mobilgeräten öffnet sich die Einrichtungsseite automatisch (Captive Portal). Am Desktop den Browser auf `http://192.168.4.1/setup` öffnen.

> **Wichtig:** Das Portal ist erst zugänglich, nachdem die Ersteinrichtung abgeschlossen wurde. Alle Routen leiten auf `/setup` um, solange kein Portal-Passwort gesetzt ist.

### Ersteinrichtung (`/setup`)

Das Formular muss ausgefüllt werden, bevor irgendetwas anderes zugänglich ist:

| Feld | Anforderung | Beschreibung |
|---|---|---|
| Portal-Benutzer | erforderlich | Benutzername für den Portal-Login |
| Portal-Passwort | min. 6 Zeichen | Schützt das gesamte Konfigurationsportal |
| Passwort bestätigen | muss übereinstimmen | |
| AP-Name (SSID) | erforderlich | Name des vom ESP32 ausgestrahlten WLANs |
| AP-Passwort | min. 8 Zeichen | Schlüssel zum Verbinden mit dem AP |

**Einrichtung abschließen** klicken. Der ESP32 speichert die Zugangsdaten in NVS und startet neu.

> **Nach der Einrichtung:** Das Portal erfordert bei jedem Aufruf HTTP Basic Auth. Der Browser fragt Benutzername und Passwort ab — das sind die soeben gesetzten Zugangsdaten, nicht das AP-Passwort.

---

## 4. WiFi & MQTT konfigurieren

Portal öffnen (`http://192.168.4.1`, Zugangsdaten aus Schritt 3), nach unten zu **WiFi & MQTT** scrollen:

| Feld | Beschreibung |
|---|---|
| WiFi SSID | Name des Heim-/Boarnetzwerks |
| WiFi Passwort | Leer lassen = bestehendes Passwort beibehalten |
| MQTT Server | IP oder Hostname des MQTT-Brokers |
| MQTT Port | Standard: `1883` |
| MQTT User | Leer lassen wenn keine Authentifizierung nötig |
| MQTT Passwort | Leer lassen = bestehendes Passwort beibehalten |

**Speichern & Neustart** klicken. Der ESP32 startet neu und verbindet sich mit dem Router.  
Der AP bleibt unter `192.168.4.1` immer aktiv, unabhängig vom WiFi-Status.

---

## 5. Kanäle zuweisen

Im Portal zu **Kanalzuordnung** scrollen:

| Spalte | Beschreibung |
|---|---|
| # | Klemmennummer (1–16, physischer Anschluss) |
| Sensor | Sensorname — wird als MQTT-Topic-Suffix verwendet, wenn kein eigener Topic gesetzt ist |
| Faktor | Multiplikator: `Ausgabe = Spannung × Faktor + Offset` |
| Offset | Additiver Offset nach dem Faktor |
| Einheit | Einheitenbezeichnung (nur Anzeige, nicht in MQTT) |
| Topic | Eigener MQTT-Topic. Leer lassen → publiziert auf `boat/io/<sensor>`. Mit dem **SK**-Button wird der passende Signal K-Pfad für gängige Sensornamen automatisch eingetragen. |
| Aktiv | Nur aktive Kanäle werden gelesen und publiziert |

> Alle 16 Kanäle teilen sich einen einzigen ADS1115 @ 0x48. Der CD74HC4067 MUX schaltet die Kanäle der Reihe nach durch — keine ADS- oder Pin-Auswahl nötig.

**Konfiguration speichern** klicken. Einstellungen werden sofort in LittleFS geschrieben, kein Neustart nötig.

---

## 6. Zugangsdaten ändern (Sicherheit)

Der Bereich **Sicherheit** im Portal erlaubt das Ändern von AP- und Portal-Zugangsdaten jederzeit.

| Feld | Anforderung | Wirkung |
|---|---|---|
| AP-Name (SSID) | erforderlich | Neuer AP-Name nach Neustart |
| AP-Passwort | min. 8 Zeichen, leer = beibehalten | Neuer AP-Schlüssel nach Neustart |
| Portal-Benutzer | erforderlich | Neuer Portal-Login-Benutzername |
| Portal-Passwort | min. 6 Zeichen, leer = beibehalten | Neues Portal-Login-Passwort |
| Passwort bestätigen | muss übereinstimmen | |

> **Warnbanner:** Solange das AP-Passwort noch dem Werksstandard (`boatopenio`) entspricht, wird oben im Portal ein gelber Warnhinweis angezeigt. Hier ändern.

---

## 7. IMU kalibrieren (optional)

Das MPU6050 läuft mit zweistufiger Kalibrierung:

**Gyro-Bias** wird automatisch bei jedem Neustart gemessen (~0,5 s, Board während des Einschaltens ruhig halten).

**Montage-Offset** korrigiert den Einbauwinkel des Boards:

1. Im Portal zu **IMU Kalibrierung** scrollen
2. Boot auf ruhigem Wasser (oder einer ebenen Fläche) ausrichten
3. Den Live-Pitch/Roll-Wert beobachten bis er stabil ist
4. **Jetzt Null setzen** klicken

Der Offset wird in NVS gespeichert und auf alle zukünftigen Messwerte und MQTT-Publizierungen angewendet.

---

## 8. Test-Modus vs. Live-Modus

Die Firmware startet standardmäßig im **Test-Modus**.

| Modus | Verhalten |
|---|---|
| TEST | Simulierte sinusförmige Sensorwerte — sicher für die Inbetriebnahme |
| LIVE | Echte ADC-Messwerte von den ADS1115-Chips |

Umschalten im Bereich **Aktionen** im Portal.

---

## 9. OTA Firmware-Updates

Sobald der ESP32 mit dem WLAN verbunden ist, kann die Firmware kabellos aktualisiert werden:

1. In der Arduino IDE den Netzwerk-Port auswählen: **BoatOpenIO bei \<IP\>**
2. Das **Portal-Passwort** (aus der Ersteinrichtung) eingeben, wenn danach gefragt wird
3. **Upload** klicken — kein USB-Kabel nötig

mDNS-Hostname: `boatopenio.local` (in Netzwerken mit mDNS-Unterstützung).

> **Hinweis:** Vor Abschluss der Ersteinrichtung wird `boatopenio` als Fallback-OTA-Passwort verwendet.

---

## 10. Werksreset

**Im Betrieb** — GPIO0-Taste 3 Sekunden gedrückt halten:  
→ Löscht nur die WiFi-Zugangsdaten. Alle anderen Einstellungen (MQTT, Kanäle, Portal-Zugangsdaten, IMU-Offset) bleiben erhalten.

**Beim Booten** — GPIO0-Taste beim Einschalten gedrückt halten, 3 Sekunden halten:  
→ Vollständiger Werksreset: löscht alle NVS-Einträge (WiFi, MQTT, Portal-Zugangsdaten, AP-Zugangsdaten, IMU-Offsets) und entfernt `config.json` aus LittleFS.

Nach einem vollständigen Werksreset ist erneut die Ersteinrichtung unter `/setup` erforderlich, bevor das Portal zugänglich wird. `config.json` über das LittleFS-Tool neu hochladen (Schritt 2).

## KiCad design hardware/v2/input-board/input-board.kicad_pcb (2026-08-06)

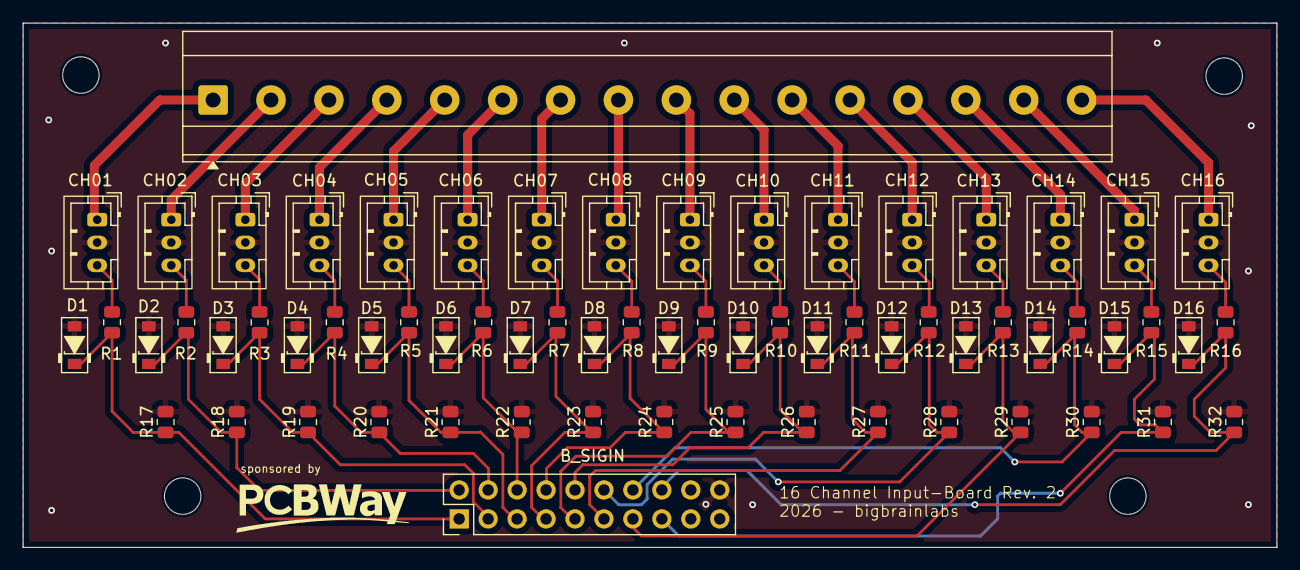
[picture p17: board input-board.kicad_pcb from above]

Board: 2 copper layers, 110.0 x 46.0 mm, 70 parts (0 on the bottom side), 49 nets.

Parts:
B11, B12, B13, B14: MountingHole_3.2mm_M3
B_SIGIN: Conn_02x10_Odd_Even; PinHeader_2x10_P2.54mm_Vertical
CH01, CH02, CH03, CH04, CH05, CH06, CH07, CH08, CH09, CH10, CH11, CH12, CH13, CH14, CH15, CH16: Conn_01x03_Pin; JST_PH_B3B-PH-K_1x03_P2.00mm_Vertical
D1, D2, D3, D4, D5, D6, D7, D8, D9, D10, D11, D12, D13, D14, D15, D16: D_Zener; D_SOD-123_Zener
J27: Screw_Terminal_01x16; TerminalBlock_Phoenix_MKDS-3-16-5.08_1x16_P5.08mm_Horizontal
R1, R2, R3, R4, R5, R6, R7, R8, R9, R10, R11, R12, R13, R14, R15, R16: 1k; R_0805_2012Metric
R17, R18, R19, R20, R21, R22, R23, R24, R25, R26, R27, R28, R29, R30, R31, R32: 1M; R_0805_2012Metric

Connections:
GND: B_SIGIN.20, CH01.2, CH02.2, CH03.2, CH04.2, CH05.2, CH06.2, CH07.2, CH08.2, CH09.2, CH10.2, CH11.2, CH12.2, CH13.2, CH14.2, CH15.2, CH16.2, D1.2 (A), D2.2 (A), D3.2 (A), D4.2 (A), D5.2 (A), D6.2 (A), D7.2 (A), D8.2 (A), D9.2 (A), D10.2 (A), D11.2 (A), D12.2 (A), D13.2 (A), D14.2 (A), D15.2 (A), D16.2 (A), R17.2, R18.2, R19.2, R20.2, R21.2, R22.2, R23.2, R24.2, R25.2, R26.2, R27.2, R28.2, R29.2, R30.2, R31.2, R32.2
unnamed: B_SIGIN.1, D1.1 (K), R1.1, R17.1
unnamed: B_SIGIN.2, D2.1 (K), R2.1, R18.1
unnamed: B_SIGIN.3, D3.1 (K), R3.1, R19.1
unnamed: B_SIGIN.4, D4.1 (K), R4.1, R20.1
unnamed: B_SIGIN.5, D5.1 (K), R5.1, R21.1
unnamed: B_SIGIN.6, D6.1 (K), R6.1, R22.1
unnamed: B_SIGIN.7, D7.1 (K), R7.1, R23.1
unnamed: B_SIGIN.8, D8.1 (K), R8.1, R24.1
unnamed: B_SIGIN.9, D9.1 (K), R9.1, R25.1
unnamed: B_SIGIN.10, D10.1 (K), R10.1, R26.1
unnamed: B_SIGIN.11, D11.1 (K), R11.1, R27.1
unnamed: B_SIGIN.12, D12.1 (K), R12.1, R28.1
unnamed: B_SIGIN.13, D13.1 (K), R13.1, R29.1
unnamed: B_SIGIN.14, D14.1 (K), R14.1, R30.1
unnamed: B_SIGIN.15, D15.1 (K), R15.1, R31.1
unnamed: B_SIGIN.16, D16.1 (K), R16.1, R32.1
unnamed: CH01.1, J27.1
unnamed: CH01.3, R1.2
unnamed: CH02.1, J27.2
unnamed: CH02.3, R2.2
unnamed: CH03.3, R3.2
unnamed: CH04.3, R4.2
unnamed: CH05.3, R5.2
unnamed: CH06.3, R6.2
unnamed: CH07.3, R7.2
unnamed: CH08.3, R8.2
unnamed: CH09.3, R9.2
unnamed: CH10.1, J27.10
unnamed: CH10.3, R10.2
unnamed: CH11.1, J27.11
unnamed: CH11.3, R11.2
unnamed: CH12.1, J27.12
unnamed: CH12.3, R12.2
unnamed: CH13.1, J27.13
unnamed: CH13.3, R13.2
unnamed: CH14.1, J27.14
unnamed: CH14.3, R14.2
unnamed: CH15.1, J27.15
unnamed: CH15.3, R15.2
unnamed: CH16.1, J27.16
unnamed: CH16.3, R16.2
unnamed: CH03.1, J27.3
unnamed: CH04.1, J27.4
unnamed: CH05.1, J27.5
unnamed: CH06.1, J27.6
unnamed: CH07.1, J27.7
unnamed: CH08.1, J27.8
unnamed: CH09.1, J27.9

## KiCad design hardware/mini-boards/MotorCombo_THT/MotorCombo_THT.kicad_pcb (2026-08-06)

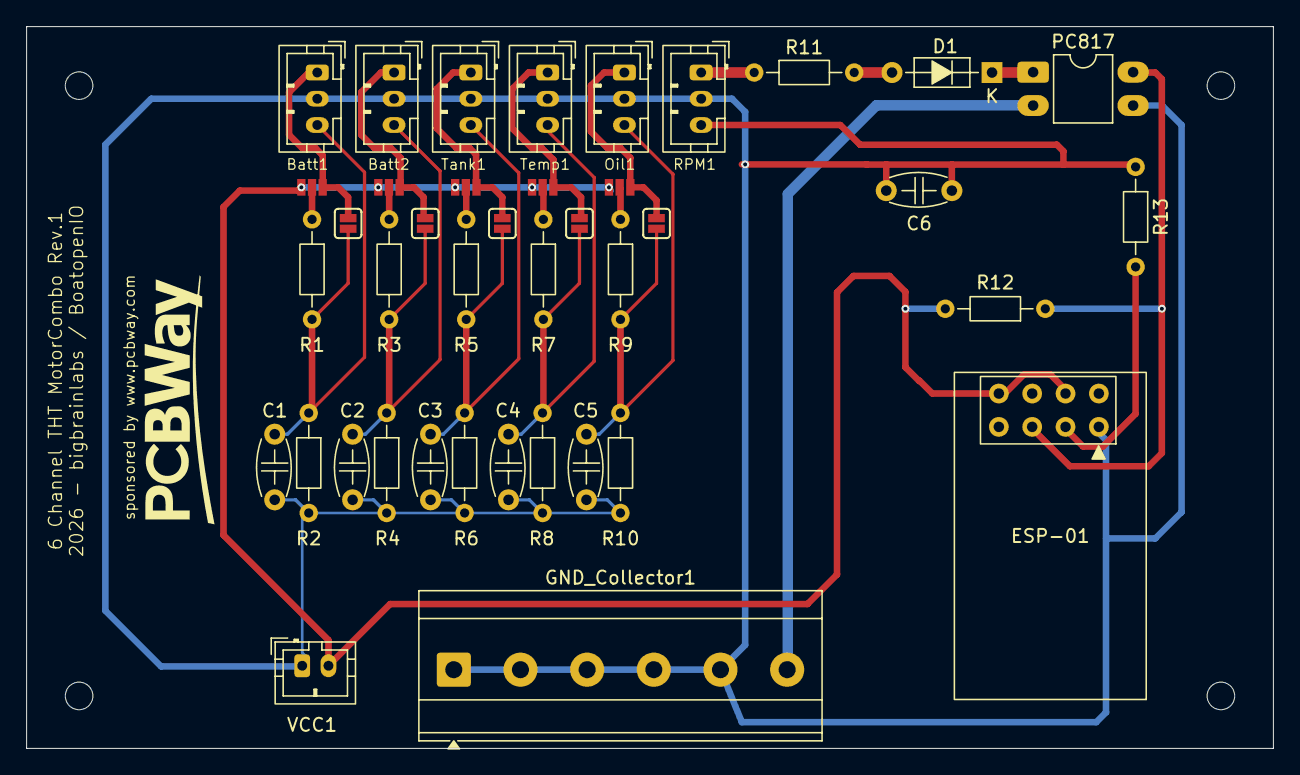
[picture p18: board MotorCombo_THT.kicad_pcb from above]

Board: 2 copper layers, 95.0 x 55.0 mm, 40 parts (0 on the bottom side), 23 nets.

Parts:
Batt1, Batt2: JST_2mm_3; JST_PH_B3B-PH-K_1x03_P2.00mm_Vertical
C1, C2, C3, C4, C5: 100nF_Ceramic; C_Disc_D5.0mm_W2.5mm_P5.00mm
C6: 100nF; C_Disc_D5.0mm_W2.5mm_P5.00mm
D1: 1N4148; D_DO-35_SOD27_P7.62mm_Horizontal
ESP-01: ESP-01v090; ESP-01
GND_Collector1: Screw_Terminal_01x05; TerminalBlock_Phoenix_MKDS-3-6-5.08_1x06_P5.08mm_Horizontal
JP1, JP3, JP5, JP7, JP9: Jumper_3_Open; Jumper_3_NO_NoSilk
JP2, JP4, JP6, JP8, JP10: Jumper_2_Open; Jumper_2_NO
Oil1: JST_2mm_3; JST_PH_B3B-PH-K_1x03_P2.00mm_Vertical
PC817: PC817; DIP-4_W7.62mm_LongPads
R1, R2, R3, R4, R5, R6, R7, R8, R9, R10: R; R_Axial_DIN0204_L3.6mm_D1.6mm_P7.62mm_Horizontal
R11: 1k; R_Axial_DIN0204_L3.6mm_D1.6mm_P7.62mm_Horizontal
R12, R13: 10k; R_Axial_DIN0204_L3.6mm_D1.6mm_P7.62mm_Horizontal
RPM1: JST_2mm_3; JST_PH_B3B-PH-K_1x03_P2.00mm_Vertical
Tank1: JST_2mm_3; JST_PH_B3B-PH-K_1x03_P2.00mm_Vertical
Temp1: JST_2mm_3; JST_PH_B3B-PH-K_1x03_P2.00mm_Vertical
VCC1: Conn_01x02; JST_PH_B2B-PH-K_1x02_P2.00mm_Vertical

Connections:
GND: Batt1.2, Batt2.2, C1.1, C2.1, C3.1, C4.1, C5.1, C6.1, C6.2, ESP-01.1 (GND), GND_Collector1.1, GND_Collector1.2, GND_Collector1.3, GND_Collector1.4, GND_Collector1.5, Oil1.2, PC817.3, R2.2, R4.2, R6.2, R8.2, R10.2, R13.1, RPM1.2, RPM1.3, Tank1.2, Temp1.2, VCC1.1
unnamed: D1.2 (A), R11.2
unnamed: D1.1 (K), PC817.1
unnamed: ESP-01.7 (CH_PD), ESP-01.8 (VCC), JP1.1 (A), JP3.1 (A), JP5.1 (A), JP7.1 (A), JP9.1 (A), R12.2, VCC1.2
unnamed: ESP-01.2 (GPIO0), PC817.4, R12.1
unnamed: ESP-01.5 (GPIO2), R13.2
unnamed: GND_Collector1.6, PC817.2
unnamed: Batt1.1, JP1.3 (B), JP2.2 (B)
unnamed: JP1.2 (C), R1.1
unnamed: Batt1.3, C1.2, JP2.1 (A), R1.2, R2.1
unnamed: Batt2.1, JP3.3 (B), JP4.2 (B)
unnamed: JP3.2 (C), R3.1
unnamed: Batt2.3, C2.2, JP4.1 (A), R3.2, R4.1
unnamed: JP5.3 (B), JP6.2 (B), Tank1.1
unnamed: JP5.2 (C), R5.1
unnamed: C3.2, JP6.1 (A), R5.2, R6.1, Tank1.3
unnamed: JP7.3 (B), JP8.2 (B), Temp1.1
unnamed: JP7.2 (C), R7.1
unnamed: C4.2, JP8.1 (A), R7.2, R8.1, Temp1.3
unnamed: JP9.2 (C), R9.1
unnamed: C5.2, JP10.1 (A), Oil1.3, R9.2, R10.1
unnamed: JP9.3 (B), JP10.2 (B), Oil1.1
unnamed: R11.1, RPM1.1

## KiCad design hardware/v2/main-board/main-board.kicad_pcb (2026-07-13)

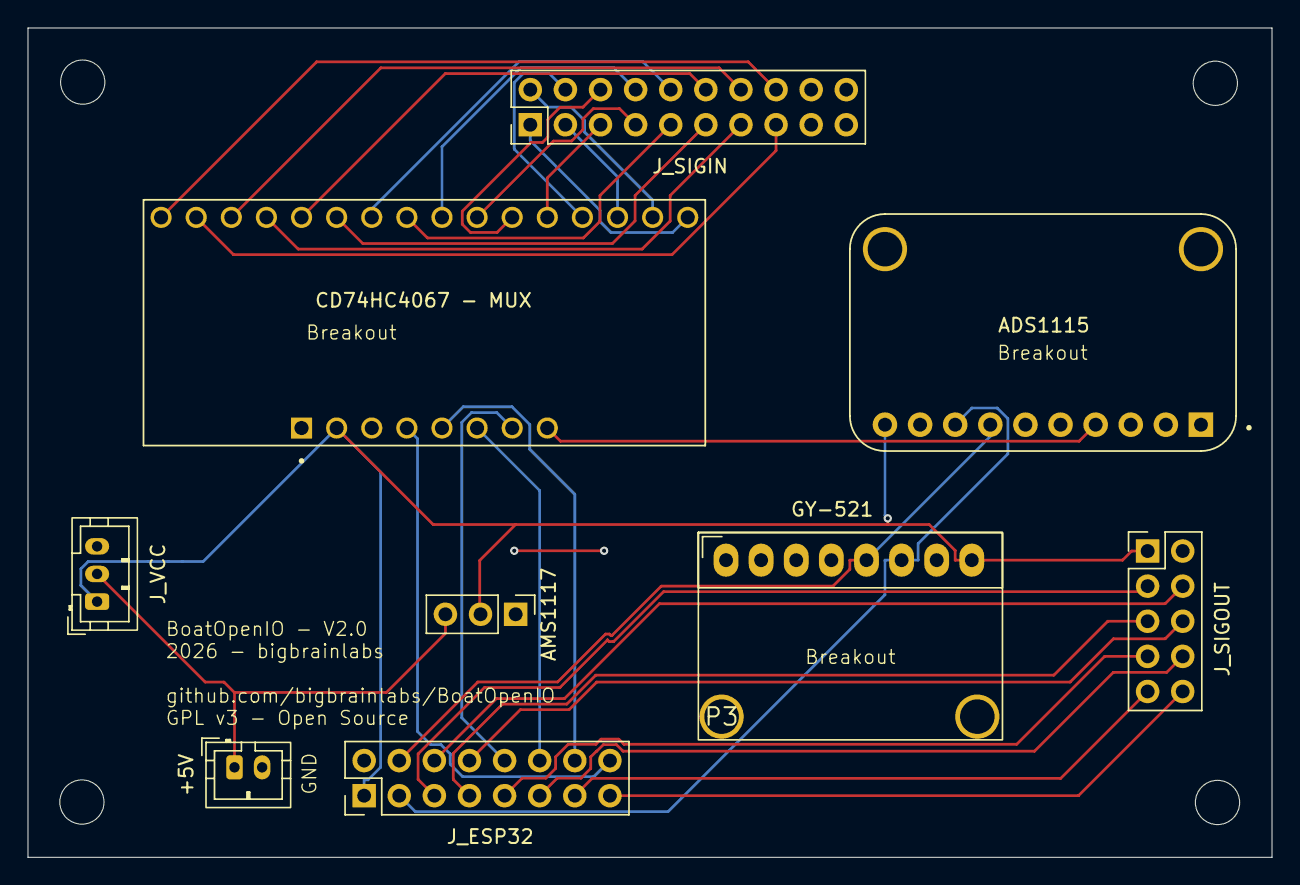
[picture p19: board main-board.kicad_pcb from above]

Board: 2 copper layers, 90.0 x 60.0 mm, 15 parts (0 on the bottom side), 34 nets.

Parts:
+5V: Conn_01x02; JST_PH_B2B-PH-K_1x02_P2.00mm_Vertical
ADS1115: ZC261500; MODULE_ZC261500
AMS1117: AMS1117CD-3.3; PinHeader_1x03_P2.54mm_Vertical
B4, B5, B6, B7: MountingHole_3.2mm_M3
CD74HC4067 - MUX: BOB-09056; MODULE_BOB-09056
GY-521: MPU6050; MPU6050_Breakout
J_ESP32: Conn_02x08_Odd_Even; PinHeader_2x08_P2.54mm_Vertical
J_SIGIN: Conn_02x10_Odd_Even; PinHeader_2x10_P2.54mm_Vertical
J_SIGOUT: Conn_02x05_Odd_Even; PinHeader_2x05_P2.54mm_Vertical
J_VCC: Conn_01x03_Pin; JST_PH_B3B-PH-K_1x03_P2.00mm_Vertical
P3, P4: (no value)

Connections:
GND: +5V.2, ADS1115.9 (GND), AMS1117.1 (GND), CD74HC4067 - MUX.JP3-1 (GND), GY-521.7 (GND), J_ESP32.2, J_SIGIN.20, J_SIGOUT.2, J_VCC.3
unnamed: +5V.1, AMS1117.3 (VI), J_VCC.2
unnamed: CD74HC4067 - MUX.JP1-16 (C15), J_SIGIN.1
unnamed: CD74HC4067 - MUX.JP1-15 (C14), J_SIGIN.2
unnamed: CD74HC4067 - MUX.JP1-14 (C13), J_SIGIN.3
unnamed: CD74HC4067 - MUX.JP1-13 (C12), J_SIGIN.4
unnamed: CD74HC4067 - MUX.JP1-12 (C11), J_SIGIN.5
unnamed: CD74HC4067 - MUX.JP1-11 (C10), J_SIGIN.6
unnamed: CD74HC4067 - MUX.JP1-10 (C9), J_SIGIN.7
unnamed: CD74HC4067 - MUX.JP1-9 (C8), J_SIGIN.8
unnamed: CD74HC4067 - MUX.JP1-8 (C7), J_SIGIN.9
unnamed: CD74HC4067 - MUX.JP1-7 (C6), J_SIGIN.10
unnamed: CD74HC4067 - MUX.JP1-6 (C5), J_SIGIN.11
unnamed: CD74HC4067 - MUX.JP1-5 (C4), J_SIGIN.12
unnamed: CD74HC4067 - MUX.JP1-4 (C3), J_SIGIN.13
unnamed: CD74HC4067 - MUX.JP1-3 (C2), J_SIGIN.14
unnamed: CD74HC4067 - MUX.JP1-2 (C1), J_SIGIN.15
unnamed: CD74HC4067 - MUX.JP1-1 (C0), J_SIGIN.16
unnamed: ADS1115.10 (VDD), AMS1117.2 (VO), CD74HC4067 - MUX.JP3-2 (VCC), GY-521.8 (VCC), J_ESP32.1, J_SIGOUT.1, J_VCC.1
unnamed: ADS1115.8 (SCL), GY-521.6 (SCL), J_ESP32.3
unnamed: ADS1115.7 (SDA), GY-521.5 (SDA), J_ESP32.4
unnamed: J_ESP32.5, J_SIGOUT.3
unnamed: J_ESP32.6, J_SIGOUT.4
unnamed: J_ESP32.7, J_SIGOUT.5
unnamed: J_ESP32.8, J_SIGOUT.6
unnamed: J_ESP32.9, J_SIGOUT.7
unnamed: CD74HC4067 - MUX.JP3-7 (S3), J_ESP32.10
unnamed: J_ESP32.11, J_SIGOUT.8
unnamed: CD74HC4067 - MUX.JP3-6 (S2), J_ESP32.12
unnamed: J_ESP32.13, J_SIGOUT.9
unnamed: CD74HC4067 - MUX.JP3-5 (S1), J_ESP32.14
unnamed: J_ESP32.15, J_SIGOUT.10
unnamed: CD74HC4067 - MUX.JP3-4 (S0), J_ESP32.16
unnamed: ADS1115.4 (A0), CD74HC4067 - MUX.JP3-8 (COM)

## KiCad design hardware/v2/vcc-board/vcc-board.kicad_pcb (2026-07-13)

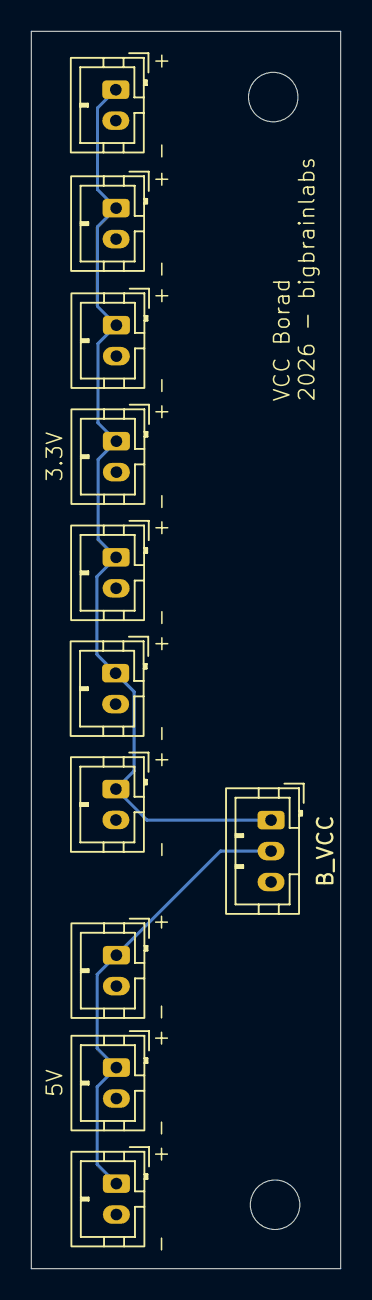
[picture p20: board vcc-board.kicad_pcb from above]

Board: 2 copper layers, 20.0 x 80.0 mm, 13 parts (0 on the bottom side), 3 nets.

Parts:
3.3V#1, 3.3V#2, 3.3V#3, 3.3V#4, 3.3V#5, 3.3V#6, 3.3V#7, 5V#1, 5V#2, 5V#3: Conn_01x02; JST_PH_B2B-PH-K_1x02_P2.00mm_Vertical
B9, B10: MountingHole_3.2mm_M3
B_VCC: Conn_01x03_Pin; JST_PH_B3B-PH-K_1x03_P2.00mm_Vertical

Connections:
GND: 3.3V#1.2, 3.3V#2.2, 3.3V#3.2, 3.3V#4.2, 3.3V#5.2, 3.3V#6.2, 3.3V#7.2, 5V#1.2, 5V#2.2, 5V#3.2, B_VCC.3
unnamed: 3.3V#1.1, 3.3V#2.1, 3.3V#3.1, 3.3V#4.1, 3.3V#5.1, 3.3V#6.1, 3.3V#7.1, B_VCC.1
unnamed: 5V#1.1, 5V#2.1, 5V#3.1, B_VCC.2

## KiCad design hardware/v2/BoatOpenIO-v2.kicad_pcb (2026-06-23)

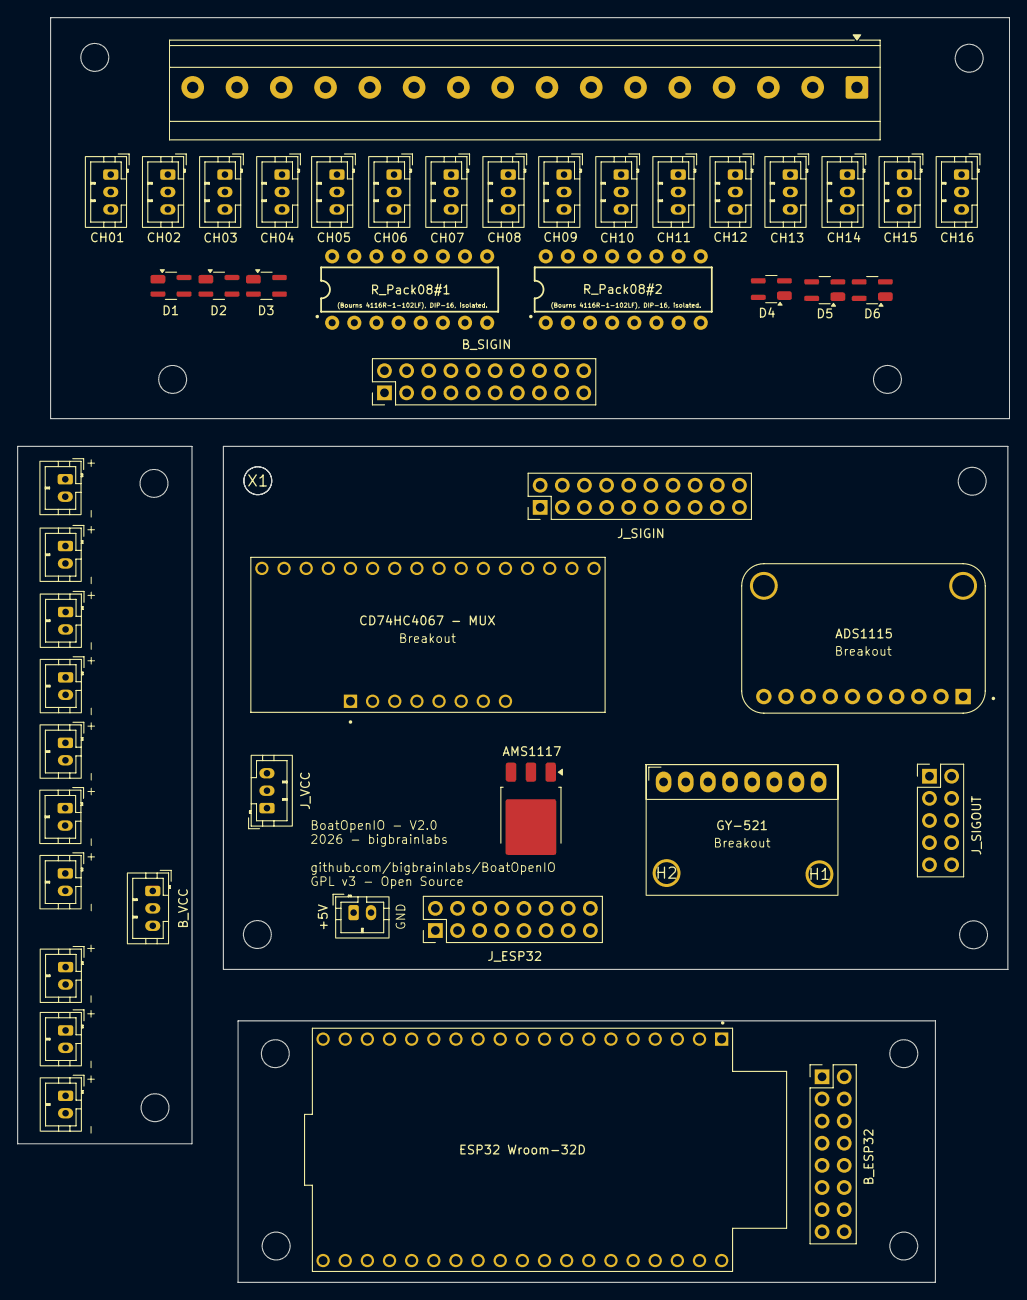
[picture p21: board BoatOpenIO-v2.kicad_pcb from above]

Board: 2 copper layers, 113.8 x 145.1 mm, 65 parts (0 on the bottom side), 100 nets, no tracks yet.

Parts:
3.3V#1, 3.3V#2, 3.3V#3, 3.3V#4, 3.3V#5, 3.3V#6, 3.3V#7, 5V#1, 5V#2, 5V#3: Conn_01x02; JST_PH_B2B-PH-K_1x02_P2.00mm_Vertical
+5V: Conn_01x02; JST_PH_B2B-PH-K_1x02_P2.00mm_Vertical
ADS1115: ZC261500; MODULE_ZC261500
AMS1117: AMS1117CD-3.3; TO-252-3_TabPin2
B1, B2, B3, B4, B5, B6, B7, B8, B9, B10, B11, B12, B13, B14: MountingHole_3.2mm_M3
B_ESP32: Conn_02x08_Odd_Even; PinHeader_2x08_P2.54mm_Vertical
B_SIGIN: Conn_02x10_Odd_Even; PinHeader_2x10_P2.54mm_Vertical
B_VCC: Conn_01x03_Pin; JST_PH_B3B-PH-K_1x03_P2.00mm_Vertical
CD74HC4067 - MUX: BOB-09056; MODULE_BOB-09056
CH01, CH02, CH03, CH04, CH05, CH06, CH07, CH08, CH09, CH10, CH11, CH12, CH13, CH14, CH15, CH16: Conn_01x03_Pin; JST_PH_B3B-PH-K_1x03_P2.00mm_Vertical
D1, D2, D3, D4, D5, D6: SP0503BAHTG; SOT-143_Handsoldering
ESP32 Wroom-32D: ESP32-WROOM-32D; MODULE_ESP32-DEVKITC
GY-521: MPU6050; MPU6050_Breakout
H1, H2: (no value)
J27: Screw_Terminal_01x16; TerminalBlock_Phoenix_MKDS-3-16-5.08_1x16_P5.08mm_Horizontal
J_ESP32: Conn_02x08_Odd_Even; PinHeader_2x08_P2.54mm_Vertical
J_SIGIN: Conn_02x10_Odd_Even; PinHeader_2x10_P2.54mm_Vertical
J_SIGOUT: Conn_02x05_Odd_Even; PinHeader_2x05_P2.54mm_Vertical
J_VCC: Conn_01x03_Pin; JST_PH_B3B-PH-K_1x03_P2.00mm_Vertical
R_Pack08#1, R_Pack08#2: R_Pack08; DIP-16
X1: (no value)

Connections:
GND: 3.3V#1.2, 3.3V#2.2, 3.3V#3.2, 3.3V#4.2, 3.3V#5.2, 3.3V#6.2, 3.3V#7.2, 5V#1.2, 5V#2.2, 5V#3.2, +5V.2, ADS1115.9 (GND), AMS1117.1 (GND), B_SIGIN.20, B_VCC.3, CD74HC4067 - MUX.JP3-1 (GND), CH01.2, CH02.2, CH03.2, CH04.2, CH05.2, CH06.2, CH07.2, CH08.2, CH09.2, CH10.2, CH11.2, CH12.2, CH13.2, CH14.2, CH15.2, CH16.2, D1.1, D2.1, D3.1, D4.1, D5.1, D6.1, GY-521.7 (GND), J_ESP32.2, J_SIGIN.20, J_SIGOUT.2, J_VCC.3
unnamed: CH16.1, J27.1
unnamed: CH16.3, R_Pack08#2.16 (R1.2)
unnamed: CH15.1, J27.2
unnamed: CH15.3, R_Pack08#2.15 (R2.2)
unnamed: CH14.3, R_Pack08#2.14 (R3.2)
unnamed: CH13.3, R_Pack08#2.13 (R4.2)
unnamed: CH12.3, R_Pack08#2.12 (R5.2)
unnamed: CH11.3, R_Pack08#2.11 (R6.2)
unnamed: CH10.3, R_Pack08#2.10 (R7.2)
unnamed: CH09.3, R_Pack08#2.9 (R8.2)
unnamed: CH08.3, R_Pack08#1.16 (R1.2)
unnamed: CH07.1, J27.10
unnamed: CH07.3, R_Pack08#1.15 (R2.2)
unnamed: CH06.1, J27.11
unnamed: CH06.3, R_Pack08#1.14 (R3.2)
unnamed: CH05.1, J27.12
unnamed: CH05.3, R_Pack08#1.13 (R4.2)
unnamed: CH04.1, J27.13
unnamed: CH04.3, R_Pack08#1.12 (R5.2)
unnamed: CH03.1, J27.14
unnamed: CH03.3, R_Pack08#1.11 (R6.2)
unnamed: CH02.1, J27.15
unnamed: CH02.3, R_Pack08#1.10 (R7.2)
unnamed: CH01.1, J27.16
unnamed: CH01.3, R_Pack08#1.9 (R8.2)
unnamed: 3.3V#1.1, 3.3V#2.1, 3.3V#3.1, 3.3V#4.1, 3.3V#5.1, 3.3V#6.1, 3.3V#7.1, B_VCC.1
unnamed: 5V#1.1, 5V#2.1, 5V#3.1, B_VCC.2
unnamed: CH14.1, J27.3
unnamed: CH13.1, J27.4
unnamed: CH12.1, J27.5
unnamed: CH11.1, J27.6
unnamed: CH10.1, J27.7
unnamed: CH09.1, J27.8
unnamed: CH08.1, J27.9
unnamed: +5V.1, AMS1117.3 (VI), J_VCC.2
unnamed: B_SIGIN.1, D1.4, R_Pack08#2.1 (R1.1)
unnamed: B_SIGIN.2, D1.3, R_Pack08#2.2 (R2.1)
unnamed: B_SIGIN.3, D1.2, R_Pack08#2.3 (R3.1)
unnamed: B_SIGIN.4, D2.4, R_Pack08#2.4 (R4.1)
unnamed: B_SIGIN.5, D3.3, R_Pack08#2.5 (R5.1)
unnamed: B_SIGIN.6, D3.2, R_Pack08#2.6 (R6.1)
unnamed: B_SIGIN.7, D2.3, R_Pack08#2.7 (R7.1)
unnamed: B_SIGIN.8, D2.2, R_Pack08#2.8 (R8.1)
unnamed: B_SIGIN.9, D3.4, R_Pack08#1.1 (R1.1)
unnamed: B_SIGIN.10, D4.3, R_Pack08#1.2 (R2.1)
unnamed: B_SIGIN.11, D4.4, R_Pack08#1.3 (R3.1)
unnamed: B_SIGIN.12, D6.4, R_Pack08#1.4 (R4.1)
unnamed: B_SIGIN.13, D4.2, R_Pack08#1.5 (R5.1)
unnamed: B_SIGIN.14, D5.3, R_Pack08#1.6 (R6.1)
unnamed: B_SIGIN.15, D6.3, R_Pack08#1.7 (R7.1)
unnamed: B_SIGIN.16, D6.2, R_Pack08#1.8 (R8.1)
unnamed: CD74HC4067 - MUX.JP1-16 (C15), J_SIGIN.1
unnamed: CD74HC4067 - MUX.JP1-15 (C14), J_SIGIN.2
unnamed: CD74HC4067 - MUX.JP1-14 (C13), J_SIGIN.3
unnamed: CD74HC4067 - MUX.JP1-13 (C12), J_SIGIN.4
unnamed: CD74HC4067 - MUX.JP1-12 (C11), J_SIGIN.5
unnamed: CD74HC4067 - MUX.JP1-11 (C10), J_SIGIN.6
unnamed: CD74HC4067 - MUX.JP1-10 (C9), J_SIGIN.7
unnamed: CD74HC4067 - MUX.JP1-9 (C8), J_SIGIN.8
unnamed: CD74HC4067 - MUX.JP1-8 (C7), J_SIGIN.9
unnamed: CD74HC4067 - MUX.JP1-7 (C6), J_SIGIN.10
unnamed: CD74HC4067 - MUX.JP1-6 (C5), J_SIGIN.11
unnamed: CD74HC4067 - MUX.JP1-5 (C4), J_SIGIN.12
unnamed: CD74HC4067 - MUX.JP1-4 (C3), J_SIGIN.13
unnamed: CD74HC4067 - MUX.JP1-3 (C2), J_SIGIN.14
unnamed: CD74HC4067 - MUX.JP1-2 (C1), J_SIGIN.15
unnamed: CD74HC4067 - MUX.JP1-1 (C0), J_SIGIN.16
unnamed: ADS1115.10 (VDD), AMS1117.2 (VO), CD74HC4067 - MUX.JP3-2 (VCC), GY-521.8 (VCC), J_ESP32.1, J_SIGOUT.1, J_VCC.1
unnamed: B_ESP32.1, ESP32 Wroom-32D.1 (3V3)
unnamed: B_ESP32.2, ESP32 Wroom-32D.38 (GND3)
unnamed: B_ESP32.3, ESP32 Wroom-32D.36 (IO22)
unnamed: B_ESP32.4, ESP32 Wroom-32D.33 (IO21)
unnamed: B_ESP32.5, ESP32 Wroom-32D.26 (IO4)
unnamed: B_ESP32.6, ESP32 Wroom-32D.29 (IO5)
unnamed: B_ESP32.7, ESP32 Wroom-32D.15 (IO13)
unnamed: B_ESP32.8, ESP32 Wroom-32D.27 (IO16)
unnamed: B_ESP32.9, ESP32 Wroom-32D.28 (IO17)
unnamed: B_ESP32.10, ESP32 Wroom-32D.9 (IO25)
unnamed: B_ESP32.11, ESP32 Wroom-32D.30 (IO18)
unnamed: B_ESP32.12, ESP32 Wroom-32D.10 (IO26)
unnamed: B_ESP32.13, ESP32 Wroom-32D.31 (IO19)
unnamed: B_ESP32.14, ESP32 Wroom-32D.11 (IO27)
unnamed: B_ESP32.15, ESP32 Wroom-32D.37 (IO23)
unnamed: B_ESP32.16, ESP32 Wroom-32D.12 (IO14)
unnamed: ADS1115.8 (SCL), GY-521.6 (SCL), J_ESP32.3
unnamed: ADS1115.7 (SDA), GY-521.5 (SDA), J_ESP32.4
unnamed: J_ESP32.5, J_SIGOUT.3
unnamed: J_ESP32.6, J_SIGOUT.4
unnamed: J_ESP32.7, J_SIGOUT.5
unnamed: J_ESP32.8, J_SIGOUT.6
unnamed: J_ESP32.9, J_SIGOUT.7
unnamed: CD74HC4067 - MUX.JP3-7 (S3), J_ESP32.10
unnamed: J_ESP32.11, J_SIGOUT.8
unnamed: CD74HC4067 - MUX.JP3-6 (S2), J_ESP32.12
unnamed: J_ESP32.13, J_SIGOUT.9
unnamed: CD74HC4067 - MUX.JP3-5 (S1), J_ESP32.14
unnamed: J_ESP32.15, J_SIGOUT.10
unnamed: CD74HC4067 - MUX.JP3-4 (S0), J_ESP32.16
unnamed: ADS1115.4 (A0), CD74HC4067 - MUX.JP3-8 (COM)

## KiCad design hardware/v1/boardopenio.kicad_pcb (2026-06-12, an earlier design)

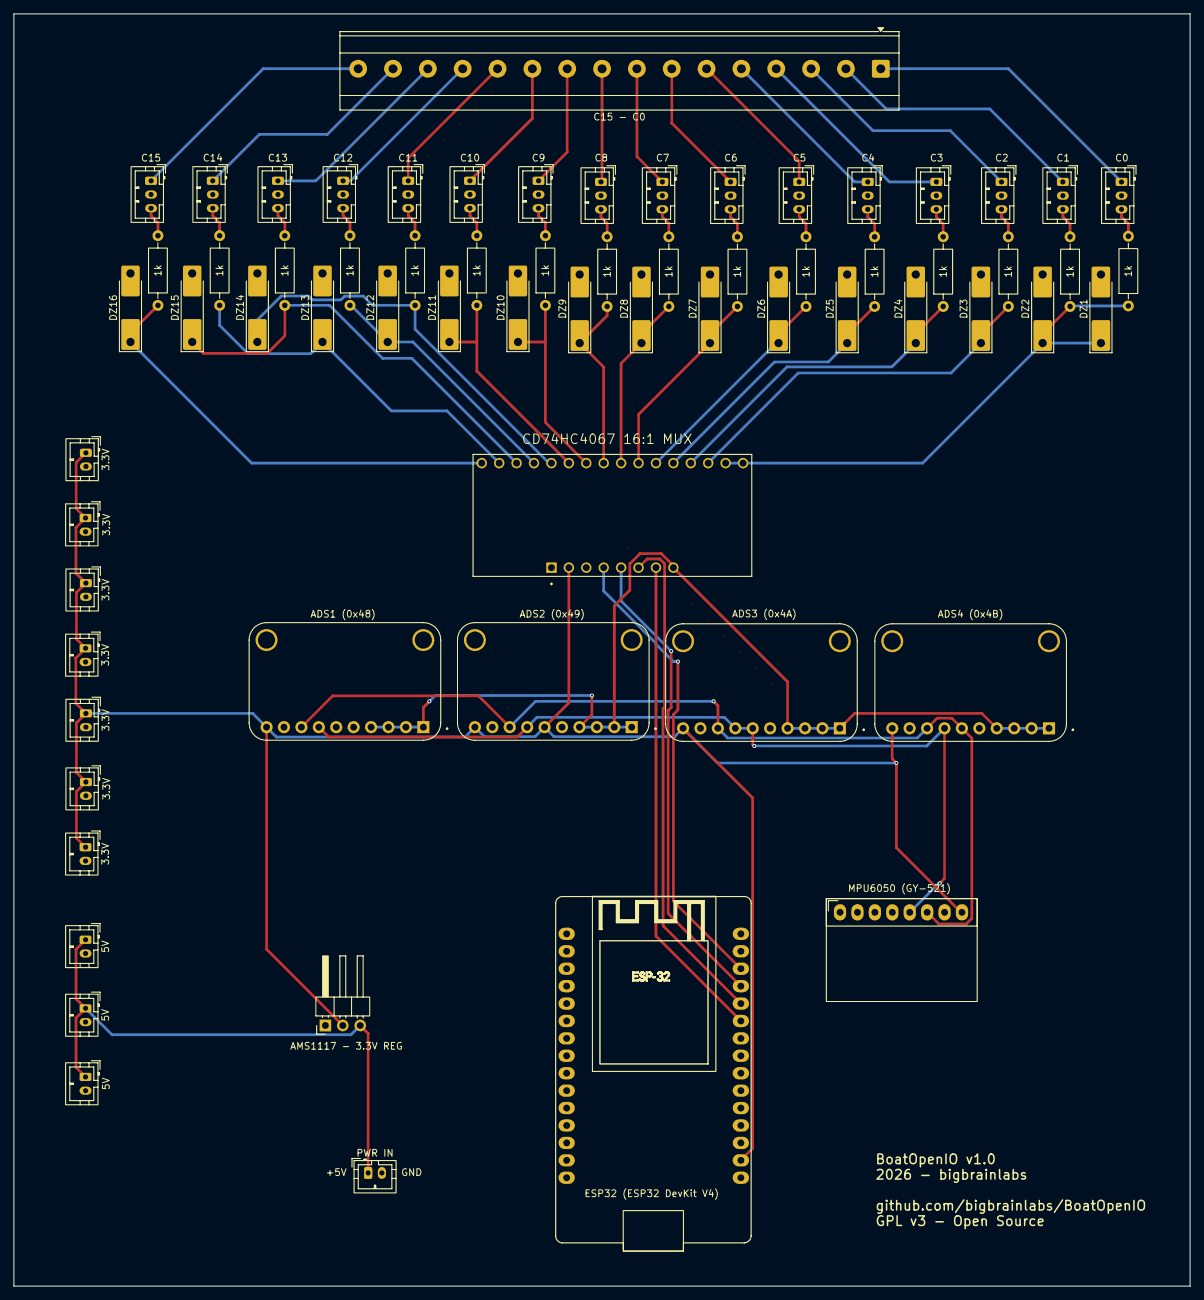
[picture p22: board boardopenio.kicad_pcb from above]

Board: 2 copper layers, 171.5 x 185.5 mm, 68 parts (0 on the bottom side), 57 nets.

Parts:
3.3V, 3.3V#2, 3.3V#3, 3.3V#4, 3.3V#5, 3.3V#6, 3.3V#7, 5V, 5V#2, 5V#3: Conn_01x02; JST_PH_B2B-PH-K_1x02_P2.00mm_Vertical
ADS1 (0x48), ADS2 (0x49), ADS3 (0x4A), ADS4 (0x4B): ZC261500; MODULE_ZC261500
AMS1117 - 3.3V REG: AMS1117CD-3.3; PinHeader_1x03_P2.54mm_Horizontal
C0, C1, C2, C3, C4, C5, C6, C7, C8, C9, C10, C11, C12, C13, C14, C15: Conn_01x03_Pin; JST_PH_B3B-PH-K_1x03_P2.00mm_Vertical
C15 - C0: Screw_Terminal_01x16; TerminalBlock_Phoenix_MKDS-3-16-5.08_1x16_P5.08mm_Horizontal
CD74HC4067 16:1 MUX: CD74HC4067 MUX; MODULE_BOB-09056
DZ1, DZ2, DZ3, DZ4, DZ5, DZ6, DZ7, DZ8, DZ9, DZ10, DZ11, DZ12, DZ13, DZ14, DZ15, DZ16: Zener 3v3; D_MELF-RM10_Universal_Handsoldering
ESP32 (ESP32 DevKit V4): DOIT_ESP32_DEVKIT_30Pins
MPU6050 (GY-521): MPU6050; MPU6050_Breakout
PWR IN: Conn_01x02; JST_PH_B2B-PH-K_1x02_P2.00mm_Vertical
R1, R2, R3, R4, R5, R6, R7, R8, R9, R10, R11, R12, R13, R14, R15, R16: 1k; R_Axial_DIN0207_L6.3mm_D2.5mm_P10.16mm_Horizontal

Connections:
GND: 3.3V.2, 3.3V#2.2, 3.3V#3.2, 3.3V#4.2, 3.3V#5.2, 3.3V#6.2, 3.3V#7.2, 5V.2, 5V#2.2, 5V#3.2, ADS1 (0x48).6 (ADDR), ADS1 (0x48).9 (GND), ADS2 (0x49).9 (GND), ADS3 (0x4A).9 (GND), ADS4 (0x4B).9 (GND), AMS1117 - 3.3V REG.1 (GND), C0.2, C1.2, C2.2, C3.2, C4.2, C5.2, C6.2, C7.2, C8.2, C9.2, C10.2, C11.2, C12.2, C13.2, C14.2, C15.2, CD74HC4067 16:1 MUX.JP3-1 (GND), CD74HC4067 16:1 MUX.JP3-3 (EN), DZ1.2 (A), DZ2.2 (A), DZ3.2 (A), DZ4.2 (A), DZ5.2 (A), DZ6.2 (A), DZ7.2 (A), DZ8.2 (A), DZ9.2 (A), DZ10.2 (A), DZ11.2 (A), DZ12.2 (A), DZ13.2 (A), DZ14.2 (A), DZ15.2 (A), DZ16.2 (A), ESP32 (ESP32 DevKit V4).1 (GND), ESP32 (ESP32 DevKit V4).15 (GND), MPU6050 (GY-521).7 (GND), PWR IN.2
unnamed: CD74HC4067 16:1 MUX.JP1-15 (C14), CD74HC4067 16:1 MUX.JP1-16 (C15), DZ1.1 (K), DZ2.1 (K), R1.1, R2.1
unnamed: CD74HC4067 16:1 MUX.JP1-14 (C13), DZ3.1 (K), R3.1
unnamed: CD74HC4067 16:1 MUX.JP1-13 (C12), DZ4.1 (K), R4.1
unnamed: CD74HC4067 16:1 MUX.JP1-12 (C11), DZ5.1 (K), R5.1
unnamed: CD74HC4067 16:1 MUX.JP1-11 (C10), DZ6.1 (K), R6.1
unnamed: CD74HC4067 16:1 MUX.JP1-10 (C9), DZ7.1 (K), R7.1
unnamed: CD74HC4067 16:1 MUX.JP1-9 (C8), DZ8.1 (K), R8.1
unnamed: CD74HC4067 16:1 MUX.JP1-8 (C7), DZ9.1 (K), R9.1
unnamed: CD74HC4067 16:1 MUX.JP1-7 (C6), DZ10.1 (K), R10.1
unnamed: CD74HC4067 16:1 MUX.JP1-6 (C5), DZ11.1 (K), R11.1
unnamed: CD74HC4067 16:1 MUX.JP1-4 (C3), DZ12.1 (K), R13.1
unnamed: CD74HC4067 16:1 MUX.JP1-2 (C1), DZ13.1 (K), R15.1
unnamed: CD74HC4067 16:1 MUX.JP1-5 (C4), DZ14.1 (K), R12.1
unnamed: CD74HC4067 16:1 MUX.JP1-3 (C2), DZ15.1 (K), R14.1
unnamed: CD74HC4067 16:1 MUX.JP1-1 (C0), DZ16.1 (K), R16.1
unnamed: C0.1, C15 - C0.1
unnamed: C0.3, R1.2
unnamed: C1.1, C15 - C0.2
unnamed: C1.3, R2.2
unnamed: C2.3, R3.2
unnamed: C3.3, R4.2
unnamed: C4.3, R5.2
unnamed: C5.3, R6.2
unnamed: C6.3, R7.2
unnamed: C7.3, R8.2
unnamed: C8.3, R9.2
unnamed: C9.1, C15 - C0.10
unnamed: C9.3, R10.2
unnamed: C10.1, C15 - C0.11
unnamed: C10.3, R11.2
unnamed: C11.1, C15 - C0.12
unnamed: C11.3, R12.2
unnamed: C12.1, C15 - C0.13
unnamed: C12.3, R13.2
unnamed: C13.1, C15 - C0.14
unnamed: C13.3, R14.2
unnamed: C14.1, C15 - C0.15
unnamed: C14.3, R15.2
unnamed: C15.1, C15 - C0.16
unnamed: C15.3, R16.2
unnamed: 3.3V.1, 3.3V#2.1, 3.3V#3.1, 3.3V#4.1, 3.3V#5.1, 3.3V#6.1, 3.3V#7.1, ADS1 (0x48).10 (VDD), ADS2 (0x49).6 (ADDR), ADS2 (0x49).10 (VDD), ADS3 (0x4A).10 (VDD), ADS4 (0x4B).10 (VDD), AMS1117 - 3.3V REG.2 (VO), CD74HC4067 16:1 MUX.JP3-2 (VCC), ESP32 (ESP32 DevKit V4).2 (VDD), MPU6050 (GY-521).8 (VCC)
unnamed: 5V.1, 5V#2.1, 5V#3.1, AMS1117 - 3.3V REG.3 (VI), PWR IN.1
unnamed: C2.1, C15 - C0.3
unnamed: C3.1, C15 - C0.4
unnamed: C4.1, C15 - C0.5
unnamed: C5.1, C15 - C0.6
unnamed: C6.1, C15 - C0.7
unnamed: C7.1, C15 - C0.8
unnamed: C8.1, C15 - C0.9
unnamed: CD74HC4067 16:1 MUX.JP3-4 (S0), ESP32 (ESP32 DevKit V4).13 (IO14)
unnamed: ADS1 (0x48).7 (SDA), ADS2 (0x49).7 (SDA), ADS3 (0x4A).6 (ADDR), ADS3 (0x4A).7 (SDA), ADS4 (0x4B).7 (SDA), MPU6050 (GY-521).5 (SDA)
unnamed: ADS1 (0x48).8 (SCL), ADS2 (0x49).8 (SCL), ADS3 (0x4A).8 (SCL), ADS4 (0x4B).6 (ADDR), ADS4 (0x4B).8 (SCL), MPU6050 (GY-521).6 (SCL)
unnamed: CD74HC4067 16:1 MUX.JP3-7 (S3), ESP32 (ESP32 DevKit V4).10 (IO25)
unnamed: CD74HC4067 16:1 MUX.JP3-6 (S2), ESP32 (ESP32 DevKit V4).11 (IO26)
unnamed: CD74HC4067 16:1 MUX.JP3-5 (S1), ESP32 (ESP32 DevKit V4).12 (IO27)
unnamed: ADS1 (0x48).1 (A3), ADS1 (0x48).2 (A2), ADS1 (0x48).3 (A1), ADS1 (0x48).4 (A0), ADS2 (0x49).1 (A3), ADS2 (0x49).2 (A2), ADS2 (0x49).3 (A1), ADS2 (0x49).4 (A0), ADS3 (0x4A).1 (A3), ADS3 (0x4A).2 (A2), ADS3 (0x4A).3 (A1), ADS3 (0x4A).4 (A0), ADS4 (0x4B).1 (A3), ADS4 (0x4B).2 (A2), ADS4 (0x4B).3 (A1), ADS4 (0x4B).4 (A0), CD74HC4067 16:1 MUX.JP3-8 (COM)

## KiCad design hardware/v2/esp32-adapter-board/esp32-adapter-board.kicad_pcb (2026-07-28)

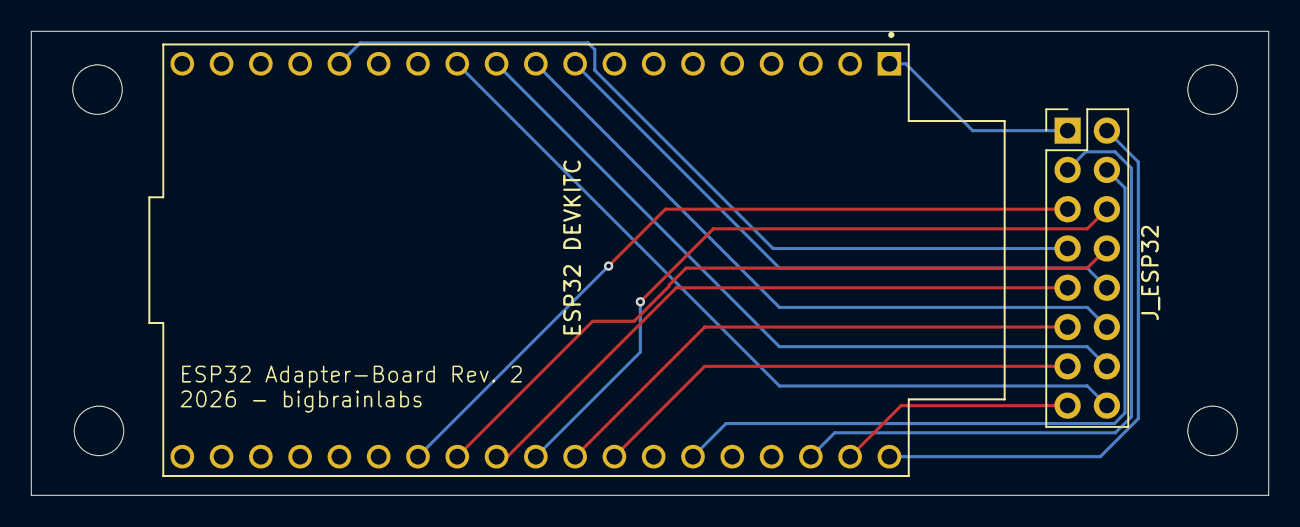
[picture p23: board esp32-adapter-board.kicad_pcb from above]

Board: 2 copper layers, 80.0 x 30.0 mm, 6 parts (0 on the bottom side), 16 nets.

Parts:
B1, B2, B3, B4: MountingHole_3.2mm_M3
ESP32 DEVKITC: ESP32-WROOM-32D; MODULE_ESP32-DEVKITC
J_ESP32: Conn_02x08_Odd_Even; PinHeader_2x08_P2.54mm_Vertical

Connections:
unnamed: ESP32 DEVKITC.1 (3V3), J_ESP32.1
unnamed: ESP32 DEVKITC.38 (GND3), J_ESP32.2
unnamed: ESP32 DEVKITC.36 (IO22), J_ESP32.3
unnamed: ESP32 DEVKITC.33 (IO21), J_ESP32.4
unnamed: ESP32 DEVKITC.26 (IO4), J_ESP32.5
unnamed: ESP32 DEVKITC.29 (IO5), J_ESP32.6
unnamed: ESP32 DEVKITC.15 (IO13), J_ESP32.7
unnamed: ESP32 DEVKITC.27 (IO16), J_ESP32.8
unnamed: ESP32 DEVKITC.28 (IO17), J_ESP32.9
unnamed: ESP32 DEVKITC.9 (IO25), J_ESP32.10
unnamed: ESP32 DEVKITC.30 (IO18), J_ESP32.11
unnamed: ESP32 DEVKITC.10 (IO26), J_ESP32.12
unnamed: ESP32 DEVKITC.31 (IO19), J_ESP32.13
unnamed: ESP32 DEVKITC.11 (IO27), J_ESP32.14
unnamed: ESP32 DEVKITC.37 (IO23), J_ESP32.15
unnamed: ESP32 DEVKITC.12 (IO14), J_ESP32.16

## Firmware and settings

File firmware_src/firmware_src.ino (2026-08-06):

// ============================================================
// BoatOpenIO – Firmware v2.2
// Universal Marine IO System
// github.com/bigbrainlabs/BoatOpenIO
// ============================================================

#define FIRMWARE_VERSION "2.4"

#include <Wire.h>
#include <WiFi.h>
#include <WebServer.h>
#include <PubSubClient.h>
#include <ArduinoOTA.h>
#include <ESPmDNS.h>
#include <esp_task_wdt.h>
#include <Adafruit_MPU6050.h>
#include <Adafruit_Sensor.h>
#include <Adafruit_ADS1X15.h>
#include <ArduinoJson.h>
#include <LittleFS.h>
#include <Preferences.h>

// ── PINS ────────────────────────────────────────────────────
#define MUX_S0           14
#define MUX_S1           27
#define MUX_S2           26
#define MUX_S3           25
// MUX-Adressleitungen debuggen: 1 = je Umschaltung Soll-Bits + tatsaechlichen
// Pad-Pegel (Readback) auf Serial ausgeben, um Firmware- gegen Hardware-Fehler
// zu trennen. Fuer den Normalbetrieb wieder auf 0 setzen.
#define MUX_DEBUG         1
// Einmaliger MUX-Selbsttest beim Boot: schaltet Kanal 0..15 durch und vergleicht
// je Adressleitung Soll-Bit gegen Pad-Readback. So laesst sich nach jedem
// Reparaturschritt ohne Multimeter pruefen. Fuer Normalbetrieb auf 0 setzen.
#define MUX_SELFTEST      1
// Park-Modus: MUX fest auf einem Kanal halten (z. B. zum Messen am Ausgang),
// waehrenddessen pausiert der automatische Sweep. Auto-Freigabe nach diesem
// Timeout (ms), falls die haltende Portalseite ohne Freigabe geschlossen wurde.
#define MUX_HOLD_TIMEOUT  60000
#define SDA_PIN          21
#define SCL_PIN          22
#define STATUS_LED_PIN    2
#define RESET_BUTTON_PIN  0

// ── KONSTANTEN ──────────────────────────────────────────────
#define CONFIG_FILE      "/config.json"
#define AP_DEFAULT_SSID  "BoatOpenIO-Setup"
#define AP_DEFAULT_PASS  "boatopenio"
#define MQTT_CLIENT_ID   "BoatOpenIO"
#define MQTT_TOPIC_BASE  "boat/io/"
#define MQTT_STATUS      "boatopenio/status"
#define READ_INTERVAL    2000
#define IMU_INTERVAL       20    // 50Hz: Aufprall-Transienten deutlich besser erfassen (M3)
#define IMU_PUBLISH_INTERVAL 1000 // Pitch/Roll aber nur 1x/s per MQTT publizieren
#define STATUS_INTERVAL  10000
#define WDT_TIMEOUT        10
#define ADS_SAMPLES         4    // Mittelung pro Kanal gegen Motorraum-Stoerungen (M8)
// TEMPORAER (Board Rev.1): Kanalreihenfolge ist gespiegelt verdrahtet — Klemme 1
// liegt physisch an MUX-Eingang C15, Klemme 2 an C14 usw. Statt die Hardware neu
// zu machen, spiegeln wir softwareseitig: logischer Kanal 0..15 -> physischer
// MUX-Eingang 15..0. Ab einer Board-Revision mit korrekter Verdrahtung: auf 0.
#define MUX_MIRROR          1    // 1 = Kanal 15-ch spiegeln (Rev.1), 0 = 1:1

// ── NETZWERK CONFIG ─────────────────────────────────────────
char wifi_ssid[40]   = "";
char wifi_pass[64]   = "";
char mqtt_server[40] = "192.168.1.100";
char mqtt_port[6]    = "1883";
char mqtt_user[40]   = "";
char mqtt_pass[40]   = "";
// AP & Portal-Credentials (in NVS gespeichert, beim ersten Boot leer)
char ap_ssid[32]     = AP_DEFAULT_SSID;
char ap_pass[32]     = AP_DEFAULT_PASS;
char portal_user[32] = "admin";
char portal_pass[64] = "";   // leer = Ersteinrichtung noch nicht abgeschlossen

// ── OBJEKTE ─────────────────────────────────────────────────
Adafruit_ADS1115 ads;      // 0x48
Adafruit_MPU6050 mpu;
WiFiClient       wifiClient;
PubSubClient     mqtt(wifiClient);
WebServer        webServer(80);
Preferences      preferences;

// ── KONFIGURATION ───────────────────────────────────────────
struct KanalConfig {
  uint8_t klemme;
  uint8_t ads;
  uint8_t pin;
  String  sensor;
  String  einheit;
  float   faktor;
  float   offset;
  bool    aktiv;
  String  topic;    // leer = boat/io/<sensor>
  String  rtopic;   // aufgeloester Publish-Topic (Cache, s. rebuildTopics())
};
KanalConfig kanaele[16];
bool testMode = true;
bool mpuOK    = false;
bool adsOK    = false;

// ── IMU / IMPACT ─────────────────────────────────────────────
float         pitch = 0.0f, roll = 0.0f;
unsigned long lastIMUMicros  = 0;
float         impactPeakG    = 0.0f;
unsigned long lastImpactTime = 0;
bool          impactActive   = false;

const float        COMP_ALPHA       = 0.98f;
const float        IMPACT_THRESHOLD = 0.5f;
const unsigned long IMPACT_DECAY   = 8000;

// Gyro-Bias (automatisch beim Boot gemessen)
float gyroBiasX = 0.0f, gyroBiasY = 0.0f, gyroBiasZ = 0.0f;
// Montage-Offset (via Web-UI kalibriert, in NVS gespeichert)
float pitch_offset = 0.0f, roll_offset = 0.0f;
// Achsen-Invertierung
bool  pitch_invert = false, roll_invert = false;
// Achsen-Tausch: IMU um 90° gedreht montiert -> Pitch- und Roll-Quelle tauschen.
// Wird VOR Offset und Invertierung angewendet, damit sich alle weiteren
// Korrekturen (inkl. "Null setzen") auf die getauschte Ausgabe beziehen.
bool  axes_swap = false;

// Rohquellen fuer die Pitch/Roll-Ausgabe nach optionalem Achsentausch.
float pitchSource() { return axes_swap ? roll  : pitch; }
float rollSource()  { return axes_swap ? pitch : roll;  }
// Montage-korrigierte Ausgabewerte: Achsentausch -> Offset -> Invertierung.
float pitchCorrected() { return (pitchSource() - pitch_offset) * (pitch_invert ? -1.0f : 1.0f); }
float rollCorrected()  { return (rollSource()  - roll_offset)  * (roll_invert  ? -1.0f : 1.0f); }

// ── TIMING ──────────────────────────────────────────────────
unsigned long lastChannelRead = 0;
unsigned long lastIMURead     = 0;
unsigned long lastIMUPublish  = 0;
unsigned long lastStatus      = 0;
unsigned long lastWiFiRetry   = 0;
bool          staServicesUp   = false;   // mDNS + OTA initialisiert?
bool          apActive        = true;    // SoftAP laeuft? (nach STA-Connect aus)

// Park-Modus (siehe MUX_HOLD_TIMEOUT): >=0 haelt den MUX fest auf diesem Kanal
// (0..15) und pausiert das automatische Sweepen; -1 = aus.
int           muxHold        = -1;
unsigned long muxHoldUntil   = 0;

// ── MUX ─────────────────────────────────────────────────────
void selectChannel(uint8_t ch) {
  ch &= 0x0F;
#if MUX_MIRROR
  uint8_t phys = 15 - ch;   // Rev.1: Kanalreihenfolge gespiegelt verdrahtet
#else
  uint8_t phys = ch;
#endif
  digitalWrite(MUX_S0,  phys        & 0x01);
  digitalWrite(MUX_S1, (phys >> 1)  & 0x01);
  digitalWrite(MUX_S2, (phys >> 2)  & 0x01);
  digitalWrite(MUX_S3, (phys >> 3)  & 0x01);
  delayMicroseconds(10);
#if MUX_DEBUG
  // Soll = aus dem physischen MUX-Eingang berechnete Bits; pad = per digitalRead
  // zurueckgelesener echter Pegel (beim ESP32 auch an OUTPUT-Pins moeglich).
  // Weichen soll und pad ab -> Pin/Trace/Loetstelle defekt oder Kurzschluss.
  Serial.printf("[MUX] ch=%2u -> phys=%2u  soll S0=%d S1=%d S2=%d S3=%d | pad S0=%d S1=%d S2=%d S3=%d\n",
                ch, phys,
                phys & 0x01, (phys >> 1) & 0x01, (phys >> 2) & 0x01, (phys >> 3) & 0x01,
                digitalRead(MUX_S0), digitalRead(MUX_S1),
                digitalRead(MUX_S2), digitalRead(MUX_S3));
#endif
}

// true, solange der MUX per Park-Modus festgehalten wird. Ist der Halte-Timeout
// abgelaufen (haltende Seite weg), wird automatisch freigegeben. millis()-
// ueberlaufsicher ueber die Differenzbildung.
bool muxHoldActive() {
  if (muxHold < 0) return false;
  if ((long)(millis() - muxHoldUntil) >= 0) { muxHold = -1; return false; }
  return true;
}

#if MUX_SELFTEST
// Einmaliger Boot-Selbsttest der vier MUX-Adressleitungen: Kanal 0..15
// durchschalten und je Leitung das Soll-Bit gegen den zurueckgelesenen Pad-Pegel
// pruefen. digitalRead liefert beim arduino-esp32 auch an OUTPUT-Pins den echten
// Pad-Zustand (OUTPUT haelt den Eingangspuffer aktiv), daher deckt ein Readback
// von 0 trotz Soll 1 einen Kurzschluss gegen GND / eine offene Leitung auf.
void muxSelfTest() {
  const char* nm[4] = { "S0/GPIO14", "S1/GPIO27", "S2/GPIO26", "S3/GPIO25" };
  const uint8_t pin[4] = { MUX_S0, MUX_S1, MUX_S2, MUX_S3 };
  uint8_t stuckLow = 0x0F;   // Bit b: Leitung b war bei KEINEM Kanal HIGH
  uint8_t mism     = 0;      // Bit b: Leitung b hatte mind. 1x Soll != Pad

  Serial.println("\n--- MUX-Selbsttest: Adressleitungen 0..15 ---");
  Serial.println("Bit-Reihenfolge: S3 S2 S1 S0  (S0=GPIO14 S1=GPIO27 S2=GPIO26 S3=GPIO25)");
  for (uint8_t ch = 0; ch < 16; ch++) {
    int soll[4], pad[4];
    for (int b = 0; b < 4; b++) {
      soll[b] = (ch >> b) & 0x01;
      digitalWrite(pin[b], soll[b]);
    }
    delay(2);                                  // Pad einschwingen lassen
    for (int b = 0; b < 4; b++) pad[b] = digitalRead(pin[b]);

    bool ok = true;
    for (int b = 0; b < 4; b++) {
      if (pad[b] != soll[b]) { ok = false; mism |= (1 << b); }
      if (pad[b] == 1)       { stuckLow &= ~(1 << b); }
    }
    Serial.printf("ch=%2u  soll %d%d%d%d | pad %d%d%d%d  %s\n",
                  ch, soll[3], soll[2], soll[1], soll[0],
                  pad[3], pad[2], pad[1], pad[0], ok ? "OK" : "<-- FEHLER");
  }

  for (int b = 0; b < 4; b++)
    if (stuckLow & (1 << b))
      Serial.printf("  ! %-9s kam NIE auf HIGH — Kurzschluss gegen GND / offene Leitung / defekter Pin\n", nm[b]);
  if (mism == 0)
    Serial.println("  Ergebnis: alle vier Leitungen folgen den Soll-Bits. MUX-Ansteuerung OK.");
  Serial.println("--------------------------------------------");
  selectChannel(0);                            // definierten Ausgangszustand hinterlassen
}
#endif

// ── ADS LESEN (mit Mittelung gegen Stoerungen, M8) ──────────
float readADS() {
  if (!adsOK) return 0.0f;
  // MUX routet alle 16 Kanäle auf A0. Mehrere Samples mitteln, da im
  // Motorraum (Lichtmaschine, Zuendimpulse) ein Einzelsample stark springt.
  int32_t sum = 0;
  for (int s = 0; s < ADS_SAMPLES; s++) sum += ads.readADC_SingleEnded(0);
  return ads.computeVolts((int16_t)(sum / ADS_SAMPLES));
}

// Liest die Spannung eines Kanals (Testmodus: Sinus-Demo, sonst MUX+ADS).
// Gemeinsame Quelle fuer readAllChannels() und die Live-Werte-API (N5).
float readChannelVoltage(int i) {
  if (testMode) return 2.5f + sinf(millis() / 3000.0f + i) * 0.3f;
  uint8_t ch = kanaele[i].klemme;              // 1..16, in loadConfig geclampt (M9)
  selectChannel((ch >= 1 && ch <= 16 ? ch : 1) - 1);
  return readADS();
}

// Berechnet den effektiven Publish-Topic je Kanal einmalig neu, statt ihn
// bei jedem Publish per String-Konkatenation zu bauen (N7). Aufzurufen nach
// jeder Aenderung der Kanal-Konfiguration.
void rebuildTopics() {
  for (int i = 0; i < 16; i++) {
    kanaele[i].rtopic = kanaele[i].topic.length() > 0
      ? kanaele[i].topic
      : String(MQTT_TOPIC_BASE) + kanaele[i].sensor;
  }
}

// ── KANÄLE LESEN & PUBLISHEN ─────────────────────────────────
void readAllChannels() {
  if (muxHoldActive()) return;   // Park-Modus: MUX steht fest, nicht wegsweepen
  for (int i = 0; i < 16; i++) {
    if (!kanaele[i].aktiv) continue;
    float wert = readChannelVoltage(i) * kanaele[i].faktor + kanaele[i].offset;
    char buf[16];
    dtostrf(wert, 6, 2, buf);
    mqtt.publish(kanaele[i].rtopic.c_str(), buf);
  }
}

// ── IMPACT ───────────────────────────────────────────────────
const char* impactSeverity(float g) {
  if (g < 1.0f) return "LEICHT";
  if (g < 3.0f) return "MITTEL";
  if (g < 6.0f) return "STARK";
  return "KRITISCH";
}

// Basis-Topic fuer Aufprall-Alarme. Im Testmodus auf boat/test/ umgeleitet,
// damit die zufaelligen Fake-Impacts der Demo NICHT die echten Alarm-Topics
// (und damit reale Dashboard-Anzeigen an Bord) ausloesen.
const char* alarmTopic(const char* leaf) {
  static char t[48];
  snprintf(t, sizeof(t), "%s%s", testMode ? "boat/test/alarm/" : "boat/alarm/", leaf);
  return t;
}

void publishImpact() {
  static unsigned long lastPub = 0;
  if (millis() - lastPub < 1000) return;
  lastPub = millis();
  char buf[10];
  dtostrf(impactPeakG, 5, 2, buf);
  mqtt.publish(alarmTopic("impact_g"),        buf, true);
  mqtt.publish(alarmTopic("impact_severity"), impactSeverity(impactPeakG), true);
  mqtt.publish(alarmTopic("impact_active"),   "true", true);
  Serial.printf("AUFPRALL%s: %.2fg -> %s\n", testMode ? " (TEST)" : "",
                impactPeakG, impactSeverity(impactPeakG));
}

// ── IMU (Komplementärfilter + Impact) ────────────────────────
void readIMU() {
  sensors_event_t a, g, temp;
  mpu.getEvent(&a, &g, &temp);

  unsigned long nowUs = micros();
  float dt = (lastIMUMicros == 0) ? 0.01f : (nowUs - lastIMUMicros) / 1e6f;
  if (dt > 1.0f) dt = 0.01f;
  lastIMUMicros = nowUs;

  float aPitch = atan2f(a.acceleration.x,
    sqrtf(a.acceleration.y * a.acceleration.y + a.acceleration.z * a.acceleration.z)) * 180.f / PI;
  float aRoll = atan2f(a.acceleration.y,
    sqrtf(a.acceleration.x * a.acceleration.x + a.acceleration.z * a.acceleration.z)) * 180.f / PI;

  pitch = COMP_ALPHA * (pitch + (g.gyro.y - gyroBiasY) * dt * 180.f / PI) + (1.f - COMP_ALPHA) * aPitch;
  roll  = COMP_ALPHA * (roll  + (g.gyro.x - gyroBiasX) * dt * 180.f / PI) + (1.f - COMP_ALPHA) * aRoll;

  float mag = sqrtf(a.acceleration.x * a.acceleration.x +
                    a.acceleration.y * a.acceleration.y +
                    a.acceleration.z * a.acceleration.z);
  float exG = mag / 9.81f - 1.0f;

  if (exG > IMPACT_THRESHOLD) {
    lastImpactTime = millis();
    if (!impactActive) impactActive = true;
    if (exG > impactPeakG) impactPeakG = exG;
    publishImpact();
  } else if (impactActive && millis() - lastImpactTime > IMPACT_DECAY) {
    impactActive = false;
    impactPeakG  = 0.0f;
    mqtt.publish(alarmTopic("impact_active"),   "false", true);
    mqtt.publish(alarmTopic("impact_g"),        "0.00",  true);
    mqtt.publish(alarmTopic("impact_severity"), "-",     true);
  }
}

// ── FAKE IMU ─────────────────────────────────────────────────
void fakeIMU() {
  static float pa = 0.0f, ra = 0.0f;
  pa += 0.004f; ra += 0.006f;
  pitch = sinf(pa) * 3.5f + sinf(pa * 2.1f) * 1.2f;
  roll  = sinf(ra) * 6.0f + sinf(ra * 1.8f) * 2.5f;

  static unsigned long lastFake = 0;
  static unsigned long fakeGap  = 45000UL;
  if (millis() - lastFake > fakeGap) {   // overflow-fest (N1)
    lastFake       = millis();
    fakeGap        = 30000UL + (unsigned long)random(0, 60000);
    impactPeakG    = 0.6f + random(0, 35) / 10.0f;
    impactActive   = true;
    lastImpactTime = millis();
    publishImpact();
  }
  if (impactActive && millis() - lastImpactTime > IMPACT_DECAY) {
    impactActive = false;
    impactPeakG  = 0.0f;
    mqtt.publish(alarmTopic("impact_active"),   "false", true);
    mqtt.publish(alarmTopic("impact_g"),        "0.00",  true);
    mqtt.publish(alarmTopic("impact_severity"), "-",     true);
  }
}

// Erlaubt nur unbedenkliche Zeichen in Sensor-Namen und MQTT-Topics.
// Blockt MQTT-Wildcards (#, +) und vor allem HTML-/Script-Zeichen, damit
// ein manipulierter Sensorname (der spaeter als JSON-Key im Dashboard
// landet) keine Stored-XSS ermoeglicht. allowSlash=true fuer Signal-K-Pfade.
String sanitizeToken(const String& in, bool allowSlash) {
  String out;
  out.reserve(in.length());
  for (size_t i = 0; i < in.length(); i++) {
    char c = in[i];
    bool ok = (c >= 'A' && c <= 'Z') || (c >= 'a' && c <= 'z') ||
              (c >= '0' && c <= '9') || c == '_' || c == '-' || c == '.';
    if (allowSlash && c == '/') ok = true;
    if (ok) out += c;
  }
  return out;
}

// ── KONFIGURATION LADEN / SPEICHERN ─────────────────────────
void loadConfig() {
  for (int i = 0; i < 16; i++) {
    kanaele[i] = {(uint8_t)(i + 1), 1, 0,
                  "kanal_" + String(i + 1), "V", 1.0f, 0.0f, false, "", ""};
  }
  if (!LittleFS.exists(CONFIG_FILE)) { rebuildTopics(); return; }
  File f = LittleFS.open(CONFIG_FILE, "r");
  DynamicJsonDocument doc(8192);
  DeserializationError err = deserializeJson(doc, f);
  f.close();
  if (err) {
    // Wichtig: NICHT die (noch) gueltigen Default-Kanaele verwerfen und
    // vor allem die Datei nicht ueberschreiben - so bleibt eine intakte
    // Konfig nach einem Spannungseinbruch beim Anlassen erhalten.
    Serial.printf("loadConfig: JSON-Fehler (%s) - Defaults aktiv\n", err.c_str());
    return;
  }
  JsonArray arr = doc["kanaele"].as<JsonArray>();
  int idx = 0;
  for (JsonObject k : arr) {
    if (idx >= 16) break;
    kanaele[idx].klemme  = k["klemme"]  | (idx + 1);
    if (kanaele[idx].klemme < 1 || kanaele[idx].klemme > 16)  // MUX-Kanal absichern (M9)
      kanaele[idx].klemme = idx + 1;
    kanaele[idx].ads     = k["ads"]     | 1;
    kanaele[idx].pin     = k["pin"]     | 0;
    kanaele[idx].sensor  = k["sensor"].isNull()  ? "kanal_" + String(idx + 1) : sanitizeToken(k["sensor"].as<String>(), false);
    if (kanaele[idx].sensor.length() == 0) kanaele[idx].sensor = "kanal_" + String(idx + 1);
    kanaele[idx].einheit = k["einheit"].isNull() ? "V"                         : k["einheit"].as<String>();
    kanaele[idx].faktor  = k["faktor"]  | 1.0f;
    kanaele[idx].offset  = k["offset"]  | 0.0f;
    kanaele[idx].aktiv   = k["aktiv"]   | false;
    kanaele[idx].topic   = k["topic"].isNull() ? "" : sanitizeToken(k["topic"].as<String>(), true);
    idx++;
  }
  rebuildTopics();
}
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
void loop() {
  esp_task_wdt_reset();

  // WiFi-Reconnect: erzwingt alle 30s einen Verbindungsversuch, falls STA
  // konfiguriert aber getrennt ist (z.B. Router bootet nach Stromausfall
  // langsamer als der ESP). Sobald verbunden, mDNS/OTA nachziehen.
  if (strlen(wifi_ssid) > 0) {
    if (WiFi.status() != WL_CONNECTED) {
      staServicesUp = false;
      // STA weg -> SoftAP wieder hochfahren (in ensureStaServices abgeschaltet),
      // damit das Config-Portal unter 192.168.4.1 erreichbar bleibt.
      if (!apActive) {
        WiFi.mode(WIFI_AP_STA);
        WiFi.softAP(ap_ssid, ap_pass);
        apActive = true;
        Serial.println("SoftAP reaktiviert (STA getrennt)");
      }
      if (millis() - lastWiFiRetry > 30000) {
        lastWiFiRetry = millis();
        Serial.println("WiFi getrennt - Reconnect...");
        WiFi.begin(wifi_ssid, wifi_pass);
      }
    } else {
      ensureStaServices();
    }
  }

  if (!mqtt.connected()) reconnectMQTT();
  mqtt.loop();
  if (WiFi.status() == WL_CONNECTED) ArduinoOTA.handle();
  loopWebServer();

  // GPIO0 Langdruck (3s) im Betrieb → WiFi-Credentials löschen & Neustart
  static unsigned long btnHeld = 0;
  if (digitalRead(RESET_BUTTON_PIN) == LOW) {
    if (!btnHeld) btnHeld = millis();
    if (millis() - btnHeld > 3000) {
      btnHeld = 0;
      Serial.println("Button: WiFi-Credentials loeschen...");
      preferences.begin("boatopenio", false);
      preferences.remove("wifi_ssid");
      preferences.remove("wifi_pass");
      preferences.end();
      delay(500);
      ESP.restart();
    }
  } else {
    btnHeld = 0;
  }

  // LED blinken
  static unsigned long lastBlink = 0;
  if (millis() - lastBlink > 1000) {
    digitalWrite(STATUS_LED_PIN, !digitalRead(STATUS_LED_PIN));
    lastBlink = millis();
  }

  unsigned long now = millis();

  // IMU mit 50Hz sampeln, damit kurze Aufprall-Transienten erfasst werden (M3).
  // readIMU()/publishImpact() feuern Alarme selbst; Pitch/Roll wird getrennt
  // nur 1x/s per MQTT publiziert, um den Broker nicht zu fluten.
  if (now - lastIMURead >= IMU_INTERVAL) {
    lastIMURead = now;
    if (mpuOK) readIMU();
    else        fakeIMU();
  }
  if (now - lastIMUPublish >= IMU_PUBLISH_INTERVAL) {
    lastIMUPublish = now;
    if (mqtt.connected()) {
      char buf[10];
      dtostrf(pitchCorrected(), 5, 1, buf); mqtt.publish("boat/io/pitch", buf, true);
      dtostrf(rollCorrected(),  5, 1, buf); mqtt.publish("boat/io/roll",  buf, true);
    }
  }

  // Kanäle (2s)
  if (now - lastChannelRead >= READ_INTERVAL) {
    lastChannelRead = now;
    if (mqtt.connected()) readAllChannels();
  }

  // Heartbeat (10s)
  if (now - lastStatus >= STATUS_INTERVAL) {
    lastStatus = now;
    if (mqtt.connected()) {
      mqtt.publish(MQTT_STATUS, "online", true);
      char buf[16];
      ltoa(now / 1000, buf, 10); mqtt.publish("boatopenio/uptime", buf);
      itoa(WiFi.RSSI(),  buf, 10); mqtt.publish("boatopenio/rssi",   buf);
      mqtt.publish("boatopenio/mode", testMode ? "TEST" : "LIVE", true);
    }
    Serial.printf("[%lus] WiFi:%s  MQTT:%s  Modus:%s  Pitch:%.1f  Roll:%.1f  Heap:%d\n",
                  now / 1000,
                  WiFi.status() == WL_CONNECTED ? WiFi.localIP().toString().c_str() : "X",
                  mqtt.connected() ? "OK" : "X",
                  testMode ? "TEST" : "LIVE",
                  pitch, roll, ESP.getFreeHeap());
  }
}

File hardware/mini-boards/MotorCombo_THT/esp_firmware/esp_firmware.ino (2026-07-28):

const int inputPin = 0;       // GPIO0: Eingang vom Optokoppler (Lima-W)
const int analogOutPin = 2;   // GPIO2: PWM-Ausgang zum MUX / ADS1115

volatile unsigned long pulsZaehler = 0;
unsigned long letzteMessung = 0;
const unsigned long messIntervall = 200; // Alle 200ms aktualisieren für schnelle Reaktion

void IRAM_ATTR pulsISR() {
  pulsZaehler++;
}

void setup() {
  pinMode(inputPin, INPUT_PULLUP);
  attachInterrupt(digitalPinToInterrupt(inputPin), pulsISR, RISING);

  pinMode(analogOutPin, OUTPUT);

  // WICHTIG beim ESP8266/ESP01s: Erhöhe die PWM-Frequenz auf z.B. 5000 Hz.
  // Das macht das Filtern mit dem 1k Widerstand und Kondensator extrem effektiv.
  analogWriteFreq(5000);
}

void loop() {
  unsigned long aktuelleZeit = millis();

  if (aktuelleZeit - letzteMessung >= messIntervall) {
    noInterrupts();
    unsigned long pulse = pulsZaehler;
    pulsZaehler = 0;
    interrupts();

    letzteMessung = aktuelleZeit;

    // Frequenz der Lichtmaschine berechnen
    float frequenz = (pulse * 1000.0) / messIntervall;

    // HIER IHRER ANPASSUNG: Max. Frequenz Ihrer Lima bei Höchstdrehzahl ermitteln
    // Beispiel: 0 Hz = 0V (PWM 0) | 1500 Hz (z.B. 6000 U/min) = 3.3V (PWM 1023)
    // Hinweis: ESP8266 nutzt standardmäßig 10-Bit PWM (0 bis 1023)
    int pwmWert = map(frequenz, 0, 1500, 0, 1023);
    pwmWert = constrain(pwmWert, 0, 1023);

    // Ausgabe an das RC-Glied vor dem MUX
    analogWrite(analogOutPin, pwmWert);
  }
}

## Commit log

2026-05-19 Initial commit: README und Architekturschema
    README mit Projektbeschreibung und erste SVG-Schemazeichnung der Systemarchitektur.
2026-06-04 Add firmware v2.2, docs, license and security hardening
    - firmware_src: complete firmware with web UI, MQTT, OTA, IMU calibration
    - webui.h: bilingual DE/EN portal, captive portal, first-boot setup,
    HTTP Basic Auth, AP/portal credentials in NVS, security card,
    ADS diagnostics, IMU calibration card
    - First-time setup (/setup) required before portal access; forces
    setting portal password and AP credentials on first boot
    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
2026-06-04 Fix compile error and add IMU invert + security hardening
    - Fix operator+ compile error: split sendContent() at dynamic char[]
    values (ap_ssid, ap_pass, portal_user) instead of concatenating
    const char[] with char[] via +
    - Add pitch_invert / roll_invert flags (NVS, default false)
    - IMU calibration card: invert checkboxes with live state sync,
    POST /setinvert saves to NVS without restart
    - Inversion applied consistently to MQTT, /api/values, /api/imu
    - Security: AP + portal credentials in NVS, first-boot /setup page,
    HTTP Basic Auth on all config routes, warning banner for default AP pass
    - i18n: added invert labels DE/EN
    [firmware_src.ino]
2026-06-04 Fix IMU invert checkboxes being reset by polling loop
    Only set checkbox state from API on first load (imuInvLoaded flag).
    Subsequent 1s polls update the values table but leave checkboxes alone
    so the user can toggle them before saving.
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2026-06-12 Add KiCad PCB project, Gerbers, schematic image and update READMEs
    - Add hardware/boardopenio/ KiCad project files (PCB, schematic, project, rules)
    - Add hardware/mainboard/ Gerber ZIP and schematic JPG
    - Ignore KiCad auto-backups and fp-info-cache
    - Update README.md and README_de.md
    [boardopenio.kicad_pcb, boardopenio.kicad_sch]
2026-06-12 Fix JST 3-Pin signal connector pinout in READMEs
    Pin 2 and 3 were swapped: GND is Pin 2, Signal OUT is Pin 3.
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2026-06-16 Add files via upload
    ready v1 pcb - failed
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2026-06-23 Restructure hardware/ into v1/ and v2/, update .gitignore
    - Move hardware/boardopenio/ and hardware/mainboard/ → hardware/v1/
    - Add hardware/v2/ KiCad project (main-board, input-board, esp32-adapter-board, vcc-board)
    - Replace specific fp-info-cache and backups ignore rules with glob patterns
    [BoatOpenIO-v2.dsn, BoatOpenIO-v2.kicad_pcb, BoatOpenIO-v2.kicad_sch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]
2026-06-25 Add v2 hardware updates: gerber files, updated KiCad projects, schematic revisions
    [esp32-adapter-board-B_Cu.gbr, esp32-adapter-board-B_Mask.gbr, esp32-adapter-board-B_Paste.gbr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]
2026-06-30 Update firmware to v3.0 and redesign web UI for v2 hardware
    - firmware_src.ino: Single ADS1115 @ 0x48, readADS() uses MUX A0 only,
    removed multi-ADS loop, loadConfig() defaults updated, version bump v3.0
    - webui.h: Remove ADS/Pin columns from channel table, responsive card-grid
    live values, single ADS1115 status chip, sticky header, dark marine theme,
    mobile-friendly layout (breakpoints 580px/400px), i18n DE/EN updated
    - README.md: Full English rewrite for v2 hardware (single ADS, 4-board topology,
    BOM with 20 items, updated GPIO table, v1 failure note removed)
    - README_de.md: v2 hardware details, updated BOM, softened book quote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
    [firmware_src.ino]
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2026-07-01 v2.1: UI theme, version define, SVG rework, connector corrections
    - firmware: bump to v2.1, add #define FIRMWARE_VERSION
    - webui.h: clean zinc-dark theme, flat buttons, version in header
    - README/README_de: fix Input Board connectors (no VCC), add VCC Board
    connector section, bypass protection circuit instructions
    - SVG: complete redesign (v2 architecture, 4 boards, single ADS1115,
    no overlapping elements, VCC board with JST connectors)
    [firmware_src.ino]
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2026-07-02 Add roadmap, target audience section, update all docs to v2
    - ROADMAP.md / ROADMAP_de.md: new files, feature freeze, v2.1 done list,
    planned and backlog items incl. enclosure, no HA discovery
    - README / README_de: add "Who is this for?" section (pre-2000 boats,
    analog marine gateway pitch), add roadmap link
    - docs/setup.md + setup_de.md: remove ADS/pin columns, add Topic + SK
    button description, add MUX note
    - docs/configuration.md + configuration_de.md: remove ADS/pin from all
    sections, add topic field to schema, field reference, MQTT table,
    subscribe example, fix /api/raw description
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2026-07-07 Hardware v2: Schaltplan aktualisiert, Netzliste + PNG-Export, Prototyp-Bilder nach v1_proto/
    - KiCad-Schaltplaene aktualisiert (Mainboard, ESP32-Adapter, Eingangsboard, VCC)
    - Netzliste BoatOpenIO-v2.net exportiert
    - Schaltplan-Uebersicht als images/schaltplan_v2.png
    - v1-Prototyp-Fotos nach images/v1_proto/ verschoben
    [BoatOpenIO-v2.kicad_sch, esp32_32D.kicad_sch, input-board.kicad_sch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]
2026-07-13 Ein-Punkt-Kalibrierung für Spannungsteiler + Board-Bemaßungen und Layout-PNGs
    Web-UI: Der Kalibrierdialog unterscheidet jetzt zwei Geber-Typen. Für
    proportionale Spannungsteiler (z. B. Batterie) genügt ein Punkt
    (Faktor = Wert / V_A0, Offset = 0); Punkt 2 und der Referenz-Block werden
    ausgeblendet. Resistive VDO-Geber behalten die Zwei-Punkt-Rechnung mit
    Referenzspannung, Vorwiderstand und Pull-up/-down.
    Hardware v2: Bemaßungen (User.1) für alle vier Boards ergänzt und
    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
    [esp32-adapter-board.kicad_pcb, input-board.kicad_pcb, main-board.kicad_pcb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]
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2026-07-19 Hardware: Gehäuse-Referenzscans und MotorCombo-Miniboard ergänzen
    - hardware/enclosures/: README (DE/EN) zum Community-Gehäuse-Contest
    inkl. Platinenmaßen, Zugänglichkeits-Anforderungen und CC BY-SA 4.0,
    plus 3D-Scans aller vier v2-Boards als STL-Referenzgeometrie
    - hardware/mini-boards/MotorCombo/: KiCad-Projekt (Schaltplan, PCB)
    - .gitignore: KiCad-Sperr- und Autosave-Dateien ausschließen
    [MotorCombo.kicad_pcb, MotorCombo.kicad_sch, SensorBoard-V1.stl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]
2026-07-19 Gehäuse-Contest: Lizenzzustimmung vor der Einreichung einholen
    CC BY-SA 4.0 war bisher nur als Tatsache in der README behauptet. Das
    Urheberrecht bleibt aber beim Designer — ohne vorherige Zustimmung dürfen
    Einreichungen gar nicht veröffentlicht werden. Die Lizenz wird deshalb jetzt
    vor dem Einreichen kommuniziert und beim Einreichen aktiv bestätigt.
    - Issue-Formular mit drei Pflicht-Checkboxen (eigene Arbeit, CC BY-SA 4.0
    unwiderruflich, Namensnennung) — GitHub blockiert das Absenden ohne sie
    - SUBMISSION_TEMPLATE.md als DESIGN.md je Design, hält Urheber und
    Lizenz dauerhaft neben den Dateien fest
    - Enclosures-README (DE/EN): Abschnitte "Einreichen" und "Rechte & Lizenz",
    We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
2026-07-21 MotorCombo THT: eigenes Board-Projekt mit Gerber-Dateien
    Die THT-Variante des MotorCombo-Miniboards liegt jetzt als eigenes
    KiCad-Projekt in hardware/mini-boards/MotorCombo_THT/ — inklusive
    fertigungsfertiger Gerber-Dateien und Netzliste.
    - .gitignore: redundante Backup-Regeln entfernt, **/*-backups/ deckt sie ab
    - MotorCombo.kicad_pcb aktualisiert
    [MotorCombo.kicad_pcb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]
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2026-07-21 MotorCombo THT: ESP-01S als Tipp gegen das GPIO0-Boot-Problem
    Der ESP-01S hat GPIO0 bereits mit einem Pull-up bestückt und hält den Pin
    im Ruhezustand sicher auf High — entschärft das oben beschriebene
    Boot-Modus-Problem. Pinkompatibel, passt in denselben Sockel. In beiden
    READMEs als Hinweis nach dem GPIO0-Absatz.
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2026-07-28 MotorCombo THT: Jumper-Doku, Rev.1-Bild, ESP-01-Firmware; SMD-Variante entfernt
    - README (DE/EN): neuer Abschnitt "Kanalmodus — Jumper (Kanäle 1–5)":
    JP1 (P1=3.3V/Pullup, P3=SIG-IN/Teiler, P2=gemeinsam), JP2 und R2 wählen
    Pull-up- vs. Spannungsteiler-Modus je Kanal. Hinweis unter der Kanaltabelle.
    - Neues Platinenbild MotorCombo_THT.jpg (Rev.1-Render) eingebunden.
    - esp_firmware/esp_firmware.ino wiederhergestellt (ESP-01 Drehzahl: GPIO0
    Impulszählung vom Optokoppler, GPIO2 PWM zum MUX).
    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
    [MotorCombo.kicad_pcb, MotorCombo.kicad_sch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]
2026-07-28 Gehäuse: Community-Einreichung von Bernd aufgenommen
    Design "Main Components Box with Lid" (Wand-/Hutschienenmontage, Lüfter-
    option, Kabelzugentlastung) nach hardware/enclosures/community/Bernd/.
    STL + OBJ-Quellen. Eingereicht per Issue #9, CC BY-SA 4.0 bestätigt.
    [Boden V2.stl, HutschienenMontage V2.stl, Lid Obj.obj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]
2026-07-28 Hardware v2: Input-Board neu generiert (Rev.1/Rev.2)
    Gerber neu erzeugt, rev1/rev2-ZIP und Pick-&-Place-CSV ergänzt,
    Schaltplan/Layout und Projektdateien aktualisiert.
    [BoatOpenIO-v2.kicad_sch, esp32-adapter-board.kicad_pcb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]
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2026-07-29 MotorCombo THT: Gerber neu erzeugt (bestellfertig, inkl. ZIP)
    Nach der Board-Prüfung Gerber, Bohrdateien und ZIP neu exportiert.
    gerber/ wieder vollständig, Projektdatei aktualisiert.
    [MotorCombo_THT-B_Cu.gbr, MotorCombo_THT-B_Mask.gbr, MotorCombo_THT-B_Silkscreen.gbr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]
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2026-08-06 Firmware v2.4: Pitch/Roll-Achsentausch + MUX-Cleanup
    - IMU: Pitch/Roll-Achsen per Konfiguration tauschbar (axes_swap, NVS).
    Zentrale Helfer pitchCorrected()/rollCorrected(): Reihenfolge
    Achsentausch -> Offset -> Invertierung, genutzt von MQTT-Publish,
    /api/values, /api/imu. Web-UI: Checkbox + /setinvert-Arg 'as',
    "Null setzen" bezieht Offset auf die getauschte Quelle. i18n DE/EN.
    - MUX: GND-Kanal-16-Workaround entfernt (durch 1M-Widerstand ueberfluessig),
    selectChannelPrimed weg -> direktes selectChannel.
    - Docs: Multiplexer-Tabelle auf die Software-Spiegelung (Klemme N ->
    Adresse 16-N) korrigiert; Achsentausch in Backend-/Config-Docs ergaenzt.
    - Version 2.2 -> 2.4.
    Co-Authored-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
    [firmware_src.ino]
2026-08-06 Hardware: Gerber & KiCad-Projektdateien aktualisiert
    MotorCombo_THT und v2/input-board: Gerber, Bohrdateien, ZIP,
    Bestueckungs-CSV und KiCad-Projektdateien neu erzeugt.
    [MotorCombo_THT-B_Cu.gbr, MotorCombo_THT-B_Mask.gbr, MotorCombo_THT-B_Silkscreen.gbr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]
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2026-08-09 Firmware v2.5: IMU-MQTT-Topics konfigurierbar
    - topic_pitch / topic_roll / topic_impact (Basis) in NVS, im Web-UI
    unter WiFi & MQTT editierbar. Publish-Stellen und alarmTopic() nutzen
    die Werte; Impact-Suffixe _g/_severity/_active an die Basis angehaengt.
    Testmodus-Umleitung auf boat/test/alarm/impact_* bleibt erhalten.
    Defaults exakt wie bisher -> bestehende Setups unveraendert.
    - Docs: MQTT-Topics-Abschnitt in READMEs korrigiert (falsches
    boat/io/impact -> LIGHT), Backend-/Config-Docs um die drei Topics
    und NVS-Keys ergaenzt.
    - Version 2.4 -> 2.5.
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

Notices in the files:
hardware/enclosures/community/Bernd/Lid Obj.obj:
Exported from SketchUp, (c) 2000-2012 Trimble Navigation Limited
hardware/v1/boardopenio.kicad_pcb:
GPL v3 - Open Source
